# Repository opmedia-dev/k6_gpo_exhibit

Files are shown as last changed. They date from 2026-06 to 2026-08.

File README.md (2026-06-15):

# K6 GPO Exhibit

ESP32-based interface that lets an **unmodified** GPO 232 or 332 rotary-dial
telephone work as an interactive exhibit in a K6 phone box.

## Features

- **Random ringing** — the phone rings at configurable random intervals
  (default 5-30 min); answering plays a randomly selected history track
- **Dial-a-number** — dial up to 11 digits; if a matching MP3 exists on the
  SD card it plays, otherwise a "number not recognised" message plays
- **External control box** — three buttons (RING / CANCEL / RESET) on the
  operator's equipment box, connected via an extended lead
- **Full GPO phone interface** — hook detection, rotary pulse decoding, bell
  ringing (25 Hz UK cadence), all through the original 3-core cord
- **SD card audio** — all audio (history tracks, number tracks, dial tone,
  busy tone) loaded from a micro-SD card as MP3 files
- **I2S audio output** — MAX98357A DAC for quality playback through the
  phone's earpiece via a coupling transformer
- **Optional A+B coin box** — auto-detected daughter board supports classic
  GPO pre-payment coin mechanisms (Button A/B, coin weight switch)
- **Auto/Manual mode** — 4th button toggles auto-ring on/off with panel lamp
  indicator (GPIO 13, 3–6 V)
- **Wi-Fi file manager** — ESP32 creates a `K6-Exhibit` Wi-Fi hotspot;
  connect from any phone/laptop browser to upload, delete, and manage
  SD card files without removing the card
- **OTA firmware update** — upload a compiled `.bin` through the web
  interface to update firmware wirelessly
- **System & call logging** — separate logs for system events and call
  history, viewable and clearable via the web interface

No modifications are made to the telephone.

## Supported Phones

| Phone | Bell | Notes |
|---|---|---|
| GPO 232 | External (Bellset No. 26) | Blue wire drives external bell, or leave unconnected |
| GPO 332 | Internal (2 µF cap + bell coils) | Full bell ringing via blue wire |
| GPO 332L | Internal | "Listener" variant, same 3-wire connection |

Any GPO phone with a 3-wire connection (Line A, Line B, Bell) should work.
See the hardware docs for notes on other models (706, 746, etc.).

## System Architecture

```
┌─────────────┐   3-core cord    ┌─────────────────────────────┐
│  GPO Phone  │ ◄──────────────► │   ESP32 Interface Board     │
│  (unmod.)   │  extended lead   │   (in separate enclosure)   │
└─────────────┘                  │                             │
                                 │  ESP32 DevKit               │
                                 │  + SD card module           │
                                 │  + MAX98357A I2S DAC        │
                                 │  + L293D H-bridge (ringer)  │
                                 │  + 12V adapter → buck (5V)  │
                                 │    + XL6009 boost (50V)     │
                                 │  + Optocoupler (line sense) │
                                 │  + 3 control buttons        │
                                 └─────────────────────────────┘
```

## Hardware

See [`docs/hardware/`](docs/hardware/) for:
- [**Schematic**](docs/hardware/schematic.md) — full circuit with ASCII diagrams
- [**Bill of Materials**](docs/hardware/bom.md) — ~£29 in components
- [**Wiring Guide**](docs/hardware/wiring-guide.md) — step-by-step build + test

### PCB

A KiCad carrier board layout is in [`pcb/`](pcb/) — 100 × 80 mm, 2-layer,
all through-hole.  All modules (ESP32 DevKit, MAX98357A, SD card, buck/boost
converters) plug in via pin headers.  See [`pcb/README.md`](pcb/README.md)
for fabrication instructions.

## SD Card Setup

Format a micro-SD card as FAT32 and create this directory structure:

```
/system/
    dialtone.mp3           Continuous dial tone (loops while off-hook)
    busy.mp3               Busy / error tone (loops)
    not_recognised.mp3     "The number you have dialled…"
/history/
    001.mp3                History track 1 (picked at random on ring answer)
    002.mp3                History track 2
    …
/numbers/
    999.mp3                Plays when user dials 999
    100.mp3                Plays when user dials 100
    08001111.mp3           Plays when user dials 08001111
    …
```

- History tracks play when the phone rings and is answered
- Number tracks are matched by filename: dialling `999` looks for `/numbers/999.mp3`
- If no match is found, `/system/not_recognised.mp3` plays

## Wi-Fi File Manager

The ESP32 creates a Wi-Fi access point on boot:

| Setting | Value |
|---|---|
| SSID | `K6-Exhibit` |
| Password | `phonebox` |
| URL | `http://192.168.4.1/` |

Connect with any phone or laptop, open a browser, and you can:
- **Controls** — volume slider, auto-ring timing, mode toggle, Ring Now button
- **Visitor stats** — call counters, most-dialled numbers, total uptime
- **Browse** the SD card directory structure
- **Upload** new MP3 files (validated as valid MP3 before saving)
- **Delete** existing files
- **Create** new folders
- **View logs** — system events and call history (separate tabs)
- **Clear logs** — wipe system or call log
- **Flash firmware** — upload a `.bin` file for OTA update
- **System status** — free heap, SD card space (used/total), current state

### Logs

| Log | Path | Contents |
|-----|---|---|
| System | `/logs/system.log` | Boot, Wi-Fi, SD card, mode changes, OTA, errors |
| Calls | `/logs/calls.log` | Incoming/outgoing calls with timestamps, numbers, outcomes |

Logs auto-rotate at 64 KB to avoid filling the SD card.

## Firmware

Built with [PlatformIO](https://platformio.org/) (Arduino framework for ESP32).

### Build & Flash

```bash
cd firmware
pio run                    # compile
pio run -t upload          # flash to ESP32
pio device monitor         # serial console (115200 baud)
```

### Serial Commands

| Command | Action |
|---|---|
| `R` | Ring the bell |
| `H` | Hang up / stop everything |
| `C` | Cancel ring / stop playback |
| `S` | Print current state + diagnostics |
| `A` | Toggle auto-ring on/off |
| `V0`-`V9` | Set volume (0 = min, 9 = max) |

### Control Panel Buttons

| Button | Function |
|---|---|
| RING (GPIO 32) | Manually trigger the phone bell |
| CANCEL (GPIO 33) | Cancel ringing / stop current playback |
| RESET (GPIO 27) | Full system restart |
| MODE (GPIO 14) | Toggle auto/manual ring mode |

All buttons are active-low (connect to GND when pressed); the ESP32's
internal pull-ups are enabled.

### Auto-Mode Indicator Lamp

GPIO 13 drives a 3–6 V panel lamp (active-high) that illuminates when
auto-ring mode is active.  In **auto mode** the phone rings at random
intervals (5–30 min) and the lamp is ON.  In **manual mode** the phone
only rings when the RING button is pressed and the lamp is OFF.
Calling (lifting the handset, dialling) works in both modes.

### Firmware Architecture

```
main.cpp                    Arduino setup/loop, serial commands
  └─ PhoneController        Top-level state machine
       ├─ PhoneLine         Hook detection via optocoupler + ADC
       ├─ RotaryDecoder     Dial pulse counting → digit
       ├─ BellDriver        25 Hz H-bridge with UK ring cadence
       ├─ AudioPlayer       SD card MP3 playback via I2S
       ├─ ControlPanel      3-button debounced input
       └─ CoinBox           Optional A+B coin box (auto-detected)
```

State machine:

```
             auto-ring timer
                  or
IDLE ──── BTN_RING/serial 'R' ──── RINGING ──── (answer) ──── PLAYING_HISTORY
  │                                                                 │
  │                                                            (on-hook)
  │                                                                 │
  └── (lift handset) ── DIAL_TONE ── DIALING ─┬── PLAYING_NUMBER ──┘
                                               │         │
                                               │    (playback ends) ── BUSY ── (on-hook) ── IDLE
                                               │
                              [A+B, recognised] ├── AWAIT_COINS ── (coins in) ── AWAIT_BTN_A
                                               │                   "press A" prompt
                              [A+B, coins in]  ├── AWAIT_BTN_A ── (Btn A) ── PLAYING_NUMBER
                                               │                  (Btn B) ── IDLE (refund)
                                               │
                          [A+B, not recognised] └── AWAIT_BTN_B ── (Btn B) ── IDLE (refund)
                                                    "not recognised" then "press B" prompt

Without A+B: DIALING → PLAYING_NUMBER or PLAYING_NOT_REC directly.
Incoming calls (RINGING → answer) never require A+B interaction.
```

### Callbacks

```cpp
phone.onDigit([](uint8_t d)       { /* each digit as dialled */ });
phone.onNumber([](const char* n)  { /* complete number string */ });
phone.onHook([](HookState s)      { /* hook state change */     });
phone.onState([](PhoneState s)    { /* state transition */      });
```

## Pin Assignments

| GPIO | Function |
|---|---|
| 34 | Line sense (hook / dial pulse) — ADC input |
| 26 | I2S BCLK (to MAX98357A) |
| 25 | I2S LRCLK (to MAX98357A) |
| 22 | I2S DOUT (to MAX98357A) |
| 5 | SD card CS (SPI) |
| 23 | SD card MOSI |
| 19 | SD card MISO |
| 18 | SD card SCK |
| 4 | Ring enable (H-bridge EN) |
| 16 | Ring phase A (H-bridge IN1) |
| 17 | Ring phase B (H-bridge IN2) |
| 32 | Button: RING (active-low) |
| 33 | Button: CANCEL (active-low) |
| 27 | Button: RESET (active-low) |
| 14 | Button: MODE (active-low) |
| 13 | Auto-mode lamp (active-high, 3–6 V) |
| 2 | Status LED |
| 36 | Coin box: coin sense (optional, input-only) |
| 39 | Coin box: Button A (optional, input-only) |
| 35 | Coin box: Button B (optional, input-only) |

## Technical Reference

See [`docs/gpo-phone-reference.md`](docs/gpo-phone-reference.md) for detailed
GPO 232/332 electrical specifications, rotary dial pulse characteristics, and
bell ringing requirements.

## Future Enhancements

- **Wi-Fi / MQTT** integration for remote exhibit control
- **Multi-phone networking** — connect two GPO phones via ESP-NOW
- **VoIP gateway** — bridge the GPO phone to SIP/VoIP
- **A+B coin box daughter board** — PCB design for coin mechanism interface
- **OLED status display** on the operator's control box

## License

MIT

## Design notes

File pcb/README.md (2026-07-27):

# PCB — K6 GPO Exhibit Carrier Board

KiCad 10 project for a 2-layer carrier board (100 × 100 mm).  All modules
plug in via through-hole pin headers — no SMD soldering required.

See **[PINOUT.md](PINOUT.md)** for the complete pinout reference with every
pin, net, and signal described.

## Files

| File | Description |
|---|---|
| `k6_gpo_carrier.kicad_pro` | KiCad project file |
| `k6_gpo_carrier.kicad_sch` | Schematic (text-documentation style — shows all nets and pin assignments) |
| `k6_gpo_carrier.kicad_pcb` | PCB layout with component placement, ground-fill zones, and board outline |
| `generate_kicad.py` | Python script that generates all files above (run to regenerate) |
| `PINOUT.md` | Complete pinout reference (full tables for every connector and IC) |
| `k6_carrier_rev2-8.kicad_pcb` | **Hand-routed manufacturing master (Rev 2.1, as-built & bench-proven).** Use this file for reorders. Includes the Rev 2.1 fixes: R7 (R_LIM 2.2 kΩ) and D1 in series in the opto leg, C3 (10 µF/63 V coupling cap) in series with the transformer secondary, and R2 (470 Ω) as the opto-LED shunt. Power/48 V nets widened. Not generated by the scripts — edit here directly. |

> **Reorders:** fabricate from `k6_carrier_rev2-8.kicad_pcb`. The
> `generate_*.py` scripts produce the earlier auto-layout boards and do
> **not** include the hand-routed Rev 2.1 corrections above — regenerating
> will not reproduce this master. Before ordering: continuity-check the
> built board, confirm R7 is populated in series, and confirm D1's banded
> (cathode) end faces the PC817 side.

## Board Specifications

| Parameter | Value |
|---|---|
| Dimensions | 100 × 100 mm |
| Layers | 2 (F.Cu + B.Cu) |
| Copper weight | 1 oz |
| Board thickness | 1.6 mm |
| Mounting holes | 4× M3, 4 mm from edges |
| Min trace width | 0.5 mm (power) / 0.25 mm (signal) |
| Min drill | 0.4 mm (vias), 0.8 mm (IC pads), 1.0 mm (headers) |

## Component Placement

```
┌──────────────────────────────────────────────────────────────────────────────┐
│ (MH)  [12V IN]  [BUCK]   [BOOST]                [MAX98357A] [DAC] (MH)     │
│         J3       J1        J2                      J5        J6             │
│                                                                             │
│                                                    [XFMR T1]               │
│                 ┌─────────────────────┐                                     │
│                 │                     │            [PHONE J4]               │
│                 │    ESP32 DevKit     │             3-pin screw             │
│                 │        U1           │                                     │
│ [BUTTONS]       │  2×15 pin headers   │                                     │
│  J8 RING        └─────────────────────┘       [C1]                         │
│  J9 CANCEL                                                                  │
│  J10 RESET                                    ┌────────┐                   │
│                                               │ L293D  │                   │
│                                               │  U2    │                   │
│                 [R1 470R]  [R2 220R]          └────────┘  [R3 10K]         │
│ [SD CARD]                                     ┌────┐                       │
│  J7                                           │PC817│                      │
│                                               │ U3  │                      │
│ (MH)                                          └────┘            (MH)       │
└──────────────────────────────────────────────────────────────────────────────┘
  (MH) = Mounting hole M3
```

## Connectors

| Ref | Description | Pins |
|-----|---|---|
| J1 | LM2596 buck converter (12V → 5V) | 4: IN+, IN-, OUT+, OUT- |
| J2 | XL6009 boost converter (12V → 50V) | 4: IN+, IN-, OUT+, OUT- |
| J3 | 12V DC power input | 2: +12V, GND |
| J4 | Phone cord (3-pin screw terminal) | 3: Line A, Line B, Bell |
| J5 | MAX98357A DAC module | 7: VIN, GND, SD, GAIN, DIN, BCLK, LRC |
| J6 | DAC audio output (to transformer) | 2: L+, L- |
| J7 | SD card module (SPI) | 6: GND, VCC, MOSI, MISO, SCK, CS |
| J8 | RING button (to control panel) | 2: signal, GND |
| J9 | CANCEL button (to control panel) | 2: signal, GND |
| J10 | RESET button (to control panel) | 2: signal, GND |

## ICs

| Ref | Part | Package |
|-----|---|---|
| U1 | ESP32 DevKit V1 | 2×15 pin header socket (25.4 mm row spacing) |
| U2 | L293D H-bridge | DIP-16 (use IC socket) |
| U3 | PC817 optocoupler | DIP-4 (use IC socket) |

## Passive Components

| Ref | Value | Purpose |
|-----|---|---|
| R1 | 470 Ω 1W | Line current limit |
| R2 | 220 Ω ¼W | Optocoupler LED current limit |
| R3 | 10 kΩ ¼W | Optocoupler output pull-down |
| C1 | 100 nF | L293D decoupling capacitor |
| T1 | 600 Ω : 600 Ω transformer | Audio coupling to phone line |

## Fabrication

### Ordering from JLCPCB / PCBWay

1. Open the project in KiCad 10+
2. **File → Plot** → select Gerber format, output to `gerbers/`
3. Check layers: F.Cu, B.Cu, F.SilkS, B.SilkS, F.Mask, B.Mask, Edge.Cuts
4. **Generate Drill Files** → Excellon format
5. Zip the `gerbers/` folder and upload to your fabricator

Typical 5-board order from JLCPCB: ~$2 + shipping.

### Assembly Notes

1. Solder IC sockets first (U2 DIP-16, U3 DIP-4)
2. Solder resistors and capacitor
3. Solder pin headers for all module connectors
4. Solder screw terminals (J3 power, J4 phone)
5. Solder transformer T1
6. Insert ICs into sockets (mind pin 1 orientation)
7. Plug in modules: ESP32, MAX98357A, SD card, buck converter, boost converter

## Regenerating Files

If you modify the board layout, edit `generate_kicad.py` and run:

```bash
cd pcb
python3 generate_kicad.py
```

This regenerates all three KiCad files from scratch.

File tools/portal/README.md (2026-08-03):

# K6 GPO Portal (web UI source)

React + Vite + Tailwind (shadcn/ui) source for the control panel served by the
ESP32 firmware. The firmware does **not** run this build directly — instead the
compiled app is inlined into a single HTML file, gzip-compressed, and embedded
as a byte array in `firmware/src/portal_html.h`, which `handleIndex()` serves
with `Content-Encoding: gzip`.

Every control is wired to the firmware's existing HTTP API (`/api/status`,
`/api/stats`, `/api/files`, `/api/wifi`, `/api/ota`, `/api/terminal`, …); no
server changes are needed to change the look of the portal.

## Requirements

Node 18+ and npm.

## Regenerate the embedded portal

From this directory:

```bash
npm install
npm run build      # vite build -> dist/public/
npm run inline     # -> esp32_portal.html (single self-contained file)

# Compress and turn into the C byte array the firmware embeds:
gzip -9 -n -c esp32_portal.html > esp32_portal.html.gz
python3 - <<'PY'
data=open("esp32_portal.html.gz","rb").read()
out="../../firmware/src/portal_html.h"
L=["// AUTO-GENERATED — do not edit by hand.",
"// Gzip-compressed single-file React portal (source project: tools/portal).",
"// Regenerate: see tools/portal/README.md",
"#pragma once","#include <pgmspace.h>","#include <stddef.h>","",
"const uint8_t PORTAL_HTML_GZ[] PROGMEM = {"]
row=[];body=[]
for b in data:
    row.append("0x%02x,"%b)
    if len(row)==20: body.append("  "+"".join(row)); row=[]
if row: body.append("  "+"".join(row))
L.append("\n".join(body)); L.append("};")
L.append("const size_t PORTAL_HTML_GZ_LEN = %d;"%len(data)); L.append("")
open(out,"w").write("\n".join(L)); print("wrote",out,len(data),"bytes")
PY
```

Then rebuild the firmware (`cd ../../firmware && pio run`) and flash it.

## Local preview against a real device

`npm run build` then open `dist/public/index.html`, or run a dev server and
proxy `/api/*` to a phone box on your network. The app talks to relative
`/api/...` paths, so serving it from the device (or a proxy) is all that's
needed.

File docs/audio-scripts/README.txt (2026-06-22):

K6 GPO Exhibit — Audio Scripts
==============================

These scripts are intended for recording as MP3 audio files for the
K6 telephone exhibit. Record them using a clear British voice, or use
a text-to-speech service. All files should be mono, 8kHz or higher
sample rate, MP3 format.

The scripts are organised to match the SD card directory structure
expected by the firmware.

HISTORY FILES — /history/
-------------------------
Played in random order when a visitor answers an auto-ring call.

  k6_history.mp3      The story of the K6 telephone box (~45s)
  gpo_exchange.mp3    How calls were connected by operators (~50s)
  rotary_dialling.mp3 How the rotary dial works (~40s)
  speaking_clock.mp3  The story of TIM / Speaking Clock (~45s)
  999_history.mp3     The world's first emergency number (~45s)
  button_ab.mp3       How Button A and Button B worked (~45s)
  model_railways.mp3  Telephones and the railway (~50s)

NUMBER FILES — /numbers/
------------------------
Played when a visitor dials the corresponding number.

  Dial    File                  Description
  ----    ----                  -----------
  100     operator.mp3          GPO operator — "Number please?"
  0       operator.mp3          (same file, mapped to both numbers)
  123     speaking_clock.mp3    TIM speaking clock demonstration
  999     emergency.mp3         Emergency services demonstration
  192     directory.mp3         Directory enquiries
  150     faults.mp3            GPO faults reporting line
  246     station_master.mp3    Station master's office
  347     departures.mp3        Train departure announcements
  501     signal_box.mp3        Signal box / signalman
  742     parcels.mp3           Railway parcels office
  800     timetable.mp3         Timetable enquiries
  007     bond.mp3              Easter egg — spy theme
  666     spooky.mp3            Easter egg — ghost train

SYSTEM FILES — /system/
-----------------------
Used by the firmware for specific events.

  not_recognised.mp3  Played when a dialled number is not in the directory
  welcome.mp3         Optional welcome message for auto-ring answers
  insert_coins.mp3    Prompt to insert coins (coinbox mode only)
  press_a.mp3         Prompt to press Button A (coinbox mode only)

RECORDING TIPS
--------------
- Use a quiet room with minimal echo
- Speak clearly at a moderate pace
- Leave a 0.5-second silence at the start and end of each file
- Target volume: -16 dBFS peak (loud enough to hear through
  the telephone earpiece without distortion)
- For sound effects (static, reverb, bells), add them in post-
  production rather than trying to record them live
- The telephone earpiece has limited frequency response — avoid
  relying on very high or very low frequencies for important content

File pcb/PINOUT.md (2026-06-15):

# K6 GPO Exhibit — Carrier Board Pinout Reference

Full pinout for every connector and IC on the carrier board. Silkscreen
labels on the PCB use short abbreviations — this document provides the
complete mapping.

## Silkscreen Abbreviation Legend

| Abbreviation | Meaning |
|---|---|
| SN | LINE_SENSE (hook detect ADC) |
| RG | BTN_RING (manual ring button) |
| CN | BTN_CANCEL (cancel button) |
| LR | I2S_LRCLK (word select) |
| BC | I2S_BCLK (bit clock) |
| RS | BTN_RESET (reset button) |
| MO | SPI_MOSI |
| MI | SPI_MISO |
| CK | SPI_SCK |
| CS | SD_CS (SD card chip select) |
| DIN | I2S_DOUT (data to DAC) |
| RB | RING_B (bell H-bridge B) |
| RA | RING_A (bell H-bridge A) |
| REN | RING_EN (bell enable) |
| LD | LED_STATUS |
| VIN | LM2596 pin 1 (12V input) |
| SW | LM2596 pin 2 (switch output) |
| FB | LM2596 pin 4 (feedback / +5V) |
| ON | LM2596 pin 5 (ON/OFF) |
| LnA | LINE_A (phone line) |
| LnB | LINE_B (phone line) |
| An | Anode |
| Kth | Cathode |
| Col | Collector |
| Em | Emitter |

---

## J3 — 12V DC Power Input

2-pin screw terminal (rotated 90°)

| Pin | Net | Description |
|-----|-----|---|
| 1 | +12V | DC input from wall adapter |
| 2 | GND | Ground |

## U4 — LM2596-5.0 Buck Converter IC (12V → 5V)

TO-220-5 package, on-board with supporting passives.

| Pin | Silk | Net | Description |
|-----|---|-----|---|
| 1 | VIN | +12V | Input voltage (12V) |
| 2 | SW | SW_OUT | Switch output → D1 cathode / L1 input |
| 3 | GND | GND | Ground (also connected to heatsink tab) |
| 4 | FB | +5V | Feedback (fixed 5V version → connects to output) |
| 5 | ON | GND | ON/OFF control (GND = always on) |

### Supporting Buck Converter Components

| Ref | Value | Net 1 | Net 2 | Description |
|-----|---|---|---|---|
| C2 | 680 µF 25V electrolytic | +12V | GND | Input filter capacitor |
| L1 | 33 µH power inductor | SW_OUT | +5V | Energy storage inductor |
| D1 | 1N5825 (5A 40V Schottky) | GND (anode) | SW_OUT (cathode) | Freewheeling diode |
| C3 | 220 µF 25V electrolytic | +5V | GND | Output filter capacitor |

**Circuit:** +12V → CIN (C2) → U4 VIN (pin 1). U4 OUTPUT (pin 2) → L1 → +5V rail.
D1 cathode connects to pin 2/L1 junction (SW_OUT); D1 anode to GND.
COUT (C3) smooths the +5V output. Pin 5 tied to GND for always-on operation.

## J2 — XL6009 Boost Converter (12V → 50V)

4-pin header

| Pin | Silk | Net | Description |
|-----|---|-----|---|
| 1 | 12V+ | +12V | Input positive |
| 2 | GND | GND | Input negative |
| 3 | 50V+ | +50V | Output positive (adjust trimpot) |
| 4 | GND | GND | Output negative |

## U1 — ESP32 DevKit V1

2×15 pin header socket (25.4 mm row spacing, 2.54 mm pin pitch)

### Left Column (top → bottom)

| Pin | Silk | GPIO | Net | Function |
|-----|---|---|-----|---|
| L1 | 3V3 | — | +3V3 | 3.3V output |
| L2 | EN | — | — | Enable (reset) |
| L3 | 36 | 36 | — | Input only |
| L4 | 39 | 39 | — | Input only |
| L5 | 34 SN | 34 | LINE_SENSE | Hook detect ADC input |
| L6 | 35 | 35 | — | Unused |
| L7 | 32 RG | 32 | BTN_RING | Manual ring button |
| L8 | 33 CN | 33 | BTN_CANCEL | Cancel button |
| L9 | 25 LR | 25 | I2S_LRCLK | I2S word select clock |
| L10 | 26 BC | 26 | I2S_BCLK | I2S bit clock |
| L11 | 27 RS | 27 | BTN_RESET | Reset button |
| L12 | 14 | 14 | — | Unused |
| L13 | 12 | 12 | — | Unused |
| L14 | GND | — | GND | Ground |
| L15 | 13 | 13 | — | Unused |

### Right Column (top → bottom)

| Pin | Silk | GPIO | Net | Function |
|-----|---|---|-----|---|
| R1 | 5V | — | +5V | 5V input from buck converter |
| R2 | GND | — | GND | Ground |
| R3 | 23 MO | 23 | SPI_MOSI | SD card data out |
| R4 | 22 DIN | 22 | I2S_DOUT | I2S data to DAC |
| R5 | TX | TX0 | — | Serial TX (debug) |
| R6 | RX | RX0 | — | Serial RX (debug) |
| R7 | 21 | 21 | — | Unused |
| R8 | 19 MI | 19 | SPI_MISO | SD card data in |
| R9 | 18 CK | 18 | SPI_SCK | SD card SPI clock |
| R10 | 5 CS | 5 | SD_CS | SD card chip select |
| R11 | 17 RB | 17 | RING_B | Bell H-bridge input B |
| R12 | 16 RA | 16 | RING_A | Bell H-bridge input A |
| R13 | 4 REN | 4 | RING_EN | Bell H-bridge enable |
| R14 | 2 LD | 2 | LED_STATUS | On-board LED |
| R15 | 15 | 15 | — | Unused |

## J5 — MAX98357A I2S DAC Module

7-pin header

| Pin | Silk | Net | Description |
|-----|---|-----|---|
| 1 | 5V | +5V | Module power |
| 2 | GND | GND | Ground |
| 3 | SD | — | Shutdown (leave floating or tie high) |
| 4 | GAIN | — | Gain select (leave floating = 9 dB) |
| 5 | DIN | I2S_DOUT | I2S data input (from ESP32 GPIO 22) |
| 6 | BCK | I2S_BCLK | I2S bit clock (from ESP32 GPIO 26) |
| 7 | LRC | I2S_LRCLK | I2S word select (from ESP32 GPIO 25) |

## J6 — DAC Audio Output

2-pin header (connects to transformer T1 primary)

| Pin | Silk | Net | Description |
|-----|---|-----|---|
| 1 | SPK+ | AUDIO_P1 | Speaker output + |
| 2 | SPK- | AUDIO_P2 | Speaker output − |

## T1 — Audio Coupling Transformer

600 Ω : 600 Ω, 4-pin

| Pin | Silk | Net | Description |
|-----|---|-----|---|
| 1 | SPK+ | AUDIO_P1 | Primary (from DAC SPK+) |
| 2 | SPK- | AUDIO_P2 | Primary (from DAC SPK−) |
| 3 | LnA | LINE_A | Secondary → phone Line A |
| 4 | LnB | LINE_B | Secondary → phone Line B |

## J4 — Phone Cord

3-pin screw terminal (rotated 90°, pitch 5.08 mm)

| Pin | Silk | Net | Wire Colour | Description |
|-----|---|-----|---|---|
| 1 | A Red | LINE_A | Red | Line A |
| 2 | B Wht | LINE_B | White | Line B |
| 3 | Bell | BELL | Blue | Bell coil connection |

## J8 — Ring Button

2-pin header (active low, internal pull-up)

| Pin | Silk | Net | Description |
|-----|---|-----|---|
| 1 | RING | BTN_RING | Button signal → ESP32 GPIO 32 |
| 2 | GND | GND | Ground |

## J9 — Cancel Button

2-pin header (active low, internal pull-up)

| Pin | Silk | Net | Description |
|-----|---|-----|---|
| 1 | CANCEL | BTN_CANCEL | Button signal → ESP32 GPIO 33 |
| 2 | GND | GND | Ground |

## J10 — Reset Button

2-pin header (active low, internal pull-up)

| Pin | Silk | Net | Description |
|-----|---|-----|---|
| 1 | RESET | BTN_RESET | Button signal → ESP32 GPIO 27 |
| 2 | GND | GND | Ground |

## J7 — Micro-SD Card Module (SPI)

6-pin header

| Pin | Silk | Net | Description |
|-----|---|-----|---|
| 1 | GND | GND | Ground |
| 2 | 3V3 | +3V3 | Module power |
| 3 | MOSI | SPI_MOSI | Data out → ESP32 GPIO 23 |
| 4 | MISO | SPI_MISO | Data in ← ESP32 GPIO 19 |
| 5 | SCK | SPI_SCK | SPI clock → ESP32 GPIO 18 |
| 6 | CS | SD_CS | Chip select → ESP32 GPIO 5 |

## U2 — L293D H-Bridge Motor Driver (DIP-16)

| Pin | Side | Silk | Net | Description |
|-----|---|---|-----|---|
| 1 | L | EN | RING_EN | Enable 1/2 → ESP32 GPIO 4 |
| 2 | L | IN1 | RING_A | Input 1 → ESP32 GPIO 16 |
| 3 | L | BELL | BELL | Output 1 → bell coil |
| 4 | L | GND | GND | Ground |
| 5 | L | GND | GND | Ground |
| 6 | L | LnB | LINE_B | Output 2 → phone Line B |
| 7 | L | IN2 | RING_B | Input 2 → ESP32 GPIO 17 |
| 8 | L | 50V | +50V | Motor supply (from boost) |
| 9 | R | GND | GND | Ground |
| 10 | R | — | — | Not connected |
| 11 | R | — | — | Not connected |
| 12 | R | — | GND | Ground |
| 13 | R | — | GND | Ground |
| 14 | R | — | — | Not connected |
| 15 | R | — | — | Not connected |
| 16 | R | 5V | +5V | Logic supply |

## U3 — PC817 Optocoupler (DIP-4)

| Pin | Side | Silk | Net | Description |
|-----|---|---|-----|---|
| 1 | L | An | OPTO_ANODE | LED anode (from R2) |
| 2 | L | Kth | LINE_B | LED cathode → Line B |
| 3 | R | Em | OPTO_EMIT | Phototransistor emitter → R3 → GND |
| 4 | R | Col | +3V3 | Phototransistor collector → 3.3V |

**Hook detect circuit:** +12V → R1 (470 Ω) → junction → R2 (220 Ω) → PC817 anode (pin 1). PC817 cathode (pin 2) → LINE_B. When phone is off-hook, current flows through the loop, illuminating the optocoupler LED. The phototransistor output (pin 3) is read by ESP32 GPIO 34 (ADC).

## Passive Components

| Ref | Value | Silk | Net 1 | Net 2 | Function |
|-----|---|---|---|---|---|
| R1 | 470 Ω 1W | R1 470R | +12V | JUNC_A | Line current limit |
| R2 | 220 Ω ¼W | R2 220R | JUNC_A | OPTO_ANODE | Opto LED current limit |
| R3 | 10 kΩ ¼W | R3 10K | OPTO_EMIT | GND | Opto output pull-down |
| C1 | 100 nF | C1 100nF | +5V | GND | L293D decoupling |
| C2 | 680 µF 25V | C2 680µF | +12V | GND | LM2596 input filter |
| C3 | 220 µF 25V | C3 220µF | +5V | GND | LM2596 output filter |
| L1 | 33 µH 3A | L1 33µH | SW_OUT | +5V | Buck inductor |
| D1 | 1N5825 | D1 1N5825 | GND | SW_OUT | Buck freewheeling diode |

## Module Clearance Zones

Dashed silkscreen outlines on the PCB show where plug-in module boards sit.
Do not place tall components within these zones.

| Module | Size (mm) | Header | Orientation |
|---|---|---|---|
| XL6009 Boost | 43 × 21 | J2 (4-pin) | Extends right from header |
| MAX98357A DAC | 19 × 18 | J5 (7-pin) | Extends left from header |
| Micro-SD Card | 25 × 20 | J7 (6-pin) | Extends right from header |

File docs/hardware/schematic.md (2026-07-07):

# Hardware Schematic — ESP32 GPO Phone Interface (Rev 2)

> **Revision 2** — redesigned for two separate DC supplies (12 V + 48 V),
> corrected pull-ups on input-only GPIOs, four control buttons,
> development access holes on every ESP32 pin, and a 6-pin daughter
> board header.

> All components are housed in a **separate enclosure** connected to the
> phone via an extended 3-core lead.

---

## Revision Notes — What Changed from Rev 1

| Issue (Rev 1) | Root Cause | Fix (Rev 2) |
|---|---|---|
| False A+B coin box detection when no daughter board attached | GPIO 36/39/35 are input-only with **no internal pull-up**. They float randomly — a LOW reading during the 2 s boot window triggers false detection. | Added **external 10 kΩ pull-up resistors** (R4, R5, R6) to 3.3 V on each coin box GPIO. Pins now read HIGH reliably when nothing is connected. |
| Buttons not responding (except CANCEL intermittently) | Likely wiring/positioning error on the PCB. GPIO 14 (MODE button) also has an internal pull-down during ESP32 boot, which may fight the signal. The original docs only listed 3 buttons, but firmware uses 4. | All 4 buttons clearly positioned with their own PCB zone. GPIO 14 pull-down is only active during boot — the internal pull-up is set in firmware after boot, so this is fine for a button. Ensure button wiring is correct per the new layout. |
| Polarity issues | Component orientation not clearly marked on the stripboard. | New layout includes clear polarity markers for the optocoupler, L293D, and all electrolytic capacitors. |
| Single 12 V supply for everything | XL6009 boost converter draws heavily during ringing, causing voltage dips on the 5 V rail → ESP32 brownout. | **Two separate supplies**: 12 V 1 A for logic (5 V buck), 48 V 1 A for bell (direct to L293D VS). No shared current path. |

---

## 1. Power Supply

Two **separate** DC adapters power the system. This eliminates voltage
dips during bell ringing that caused ESP32 resets in Rev 1.

```
    ┌─────────────────────┐         ┌─────────────────────┐
    │  12 V DC  1 A       │         │  48 V DC  1 A       │
    │  (barrel jack)      │         │  (barrel jack)      │
    │                     │         │                     │
    │  Powers:            │         │  Powers:            │
    │  • Buck converter   │         │  • L293D H-bridge   │
    │    (12 V → 5 V)     │         │    pin 8 (VS)       │
    │  • Line sense       │         │    for bell ringing  │
    │    circuit (R1)     │         │                     │
    └─────────┬───────────┘         └─────────┬───────────┘
              │                               │
     ┌────────┴────────┐                      │
     │  Buck Converter  │                      │
     │  LM2596 module   │                      │
     │  12 V → 5 V      │                      │
     │  (adjust trimpot) │                     │
     └────────┬─────────┘                      │
              │                                │
         +5 V rail                        +48 V rail
         Powers:                          (bell only)
         • ESP32 VIN
         • MAX98357A VIN
         • SD card module
         • L293D pin 16 (VSS)
```

### Power Bus Wiring

The board has **two bus rails** running the full length:

| Bus | Voltage | Source | Connects to |
|-----|---|---|---|
| **5 V bus** | +5 V / GND | LM2596 output | ESP32 VIN, MAX98357A VIN, SD card VCC, L293D pin 16 |
| **48 V bus** | +48 V / GND | 48 V adapter | L293D pin 8 (VS) only |

> **IMPORTANT:** The GND rails of both supplies must be **connected
> together** at a single point on the board. This provides a common
> ground reference. Connect them near the L293D GND pins.

### Components

| Part | Example | Purpose |
|---|---|---|
| 12 V DC adapter | Any 12 V / 1 A barrel-jack adapter | Logic power |
| 48 V DC adapter | Any 48 V / 1 A barrel-jack adapter | Bell power |
| Buck converter module | LM2596 adjustable (set to 5 V) | 12 V → 5 V for logic |

> **Setup:** Before connecting anything else, power the buck converter
> from 12 V and adjust its trimpot until the output reads **5.0 V** on a
> multimeter.

---

## 2. Hook / Dial Pulse Detection

This circuit detects whether the handset is on the cradle (on-hook) or
lifted (off-hook), and senses the rotary dial pulses — all on a single
GPIO pin.

> **Rev 2.1 correction — the optocoupler must be *in series* with the
> loop, not bridged across it.** The original Rev 2 layout wired the
> PC817 LED across the line (Line A via R2 → LED → Line B), with Line B
> having no return to ground. That topology can carry **no loop current
> in any hook state**, so hook and dial detection never worked. The LED
> is now in series in the return leg: **+12 V → R1 → Line A → phone →
> Line B → R_LIM → D1 → LED → GND.** R2 is deleted. This was verified on
> the bench (hook + dial both decode correctly). See the warning below
> before ever applying the 48 V bell supply.

```
    +12 V ────────┐
                  │
                 [R1]  470 Ω  1W
                  │
                  └──────────── Terminal 1 (RED wire = Line A)

                  ═══ phone loop ═══  (open on-hook, ~360 Ω off-hook)

    Terminal 2 ───┐
    (WHITE wire   │
     = Line B)   [R_LIM]  2.2 kΩ        ← current limit (MANDATORY, see warning)
                  │
                  ▼  D1  (1N4148, anode → Line B side)
                  │
             ┌────┴────┐
             │  PC817   │
             │ OPTO-    │
             │ COUPLER  │
             │  Anode  ┌┤
             │    (p1) ││── Collector (p4) ─── +3.3 V
             │  LED    └┤
             │ Cathode   │
             │  (p2)     Emitter (p3) ──┬── GPIO 34 (ESP32)
             └────┬────┘                │
                  │                    [R3]  10 kΩ
                 GND                     │
                                        GND
```

**PC817 pinout (DIP-4) — polarity markers:**

```
    ┌──────────┐
    │  Pin 1   │  Anode  ── dot/band on package (from D1 cathode / Line B leg)
    │  Pin 2   │  Cathode ── to GND
    │  Pin 3   │  Emitter ── (to GPIO 34 + R3)
    │  Pin 4   │  Collector ── (to +3.3 V)
    └──────────┘
    Pin 1 is marked with a dot on the IC package.
    The LED inside goes from pin 1 (anode) to pin 2 (cathode).
```

**How it works:**

| Phone state | What happens | GPIO 34 reads |
|---|---|---|
| **On-hook** (handset down) | Loop open — no current, LED off | LOW (~0 V) |
| **Off-hook** (handset lifted) | Loop closed — ~4-13 mA flows through R1 → phone → R_LIM → D1 → LED → GND | HIGH (~3.3 V) |
| **Dial pulse** (rotary dial break) | Loop briefly interrupted → LED off | LOW pulse (20-120 ms) |

The firmware counts these LOW pulses to decode the dialled digit
(1 pulse = digit 1, 10 pulses = digit 0).

> ### ⚠️ SAFETY: R_LIM is mandatory before applying 48 V
>
> Line B carries the **48 V ring voltage** during ringing. The opto LED
> leg (Line B → D1 → LED → GND) has **no other current limit** — R1 is
> on the Line A side and is *not* in this path. Without **R_LIM
> (1.5–2.2 kΩ)** in the Line B leg, the 48 V ring drives destructive
> current through the LED.
>
> **This is not theoretical:** on the bench, applying 48 V with R_LIM
> omitted breached the PC817's isolation and back-fed the ESP32, cooking
> both the optocoupler *and* the ESP32 module (it powered up but ran
> hot). **Never apply 48 V unless R_LIM is fitted.**
>
> - Ring peak current with R_LIM = 2.2 kΩ: 48 V / 2.2 kΩ ≈ **22 mA**
>   (safe for the PC817).
> - Off-hook detect current: (15 V − ~1.9 V) / (470 + 360 + 2200) ≈
>   **4–5 mA** (enough to trigger; drop R_LIM to 1.5 kΩ if marginal).
> - **D1 (series diode)** blocks the reverse half of the ring, so a
>   separate anti-parallel clamp diode is *not* required.

---

## 3. Ring Generator

Makes the bell ring using a 48 V square-wave AC signal at 25 Hz,
switched by an L293D H-bridge IC.

```
    +48 V (from 48 V DC adapter) ── L293D pin 8 (VS)

    +5 V ──────────────────────────── L293D pin 16 (VSS / logic supply)

    ESP32 GPIO 4  ─────────────────── L293D pin 1 (EN1,2 — enable)
    ESP32 GPIO 16 ─────────────────── L293D pin 2 (IN1)
    ESP32 GPIO 17 ─────────────────── L293D pin 7 (IN2)

    L293D pin 3 (OUT1) ──────────── Terminal 3 (BLUE wire = Bell)
    L293D pin 6 (OUT2) ──────────── Terminal 2 (WHITE wire = Line B)

    L293D pins 4, 5, 12, 13 ─────── GND (common ground bus)
    L293D pin 9 ──────────────────── GND
```

**How it works:**

The firmware alternates IN1/IN2 at 25 Hz while EN is HIGH (with PWM
for volume control), producing a square wave that swings between +48 V
and -48 V across the bell coil.  The GPO 332's internal 2 µF capacitor
passes this AC to the bell mechanism.

> **Note:** Rev 1 used a boost converter to generate 50 V from 12 V.
> Rev 2 uses a dedicated 48 V DC supply, eliminating the boost converter
> entirely. 48 V is sufficient to ring the bell — the GPO spec is
> 60-80 V AC, but the capacitive impedance at 25 Hz means 48 V
> produces adequate striking force.

**L293D pinout (DIP-16) — notch at top:**

```
                 ┌───┐
    EN1,2  1 ────┤   ├──── 16  VSS (+5 V logic)
      IN1  2 ────┤   ├──── 15  EN3,4 (n/c)
     OUT1  3 ────┤   ├──── 14  IN4 (n/c)
      GND  4 ────┤   ├──── 13  GND
      GND  5 ────┤   ├──── 12  GND
     OUT2  6 ────┤   ├──── 11  OUT4 (n/c)
      IN2  7 ────┤   ├──── 10  IN3 (n/c)
  VS(+48V) 8 ────┤   ├──── 9   GND
                 └───┘
    Notch/dot at pin 1 end. Mount with notch facing away from
    the 48 V bus to keep high-voltage traces on one side.
```

---

## 4. Audio Output (I2S DAC → Phone Line)

Audio plays from the SD card through an I2S DAC module, then into the
phone line via a coupling transformer.

```
    ESP32                     MAX98357A              Audio Transformer
    GPIO 26 ── BCLK ────────► BCLK                 (600 Ω : 600 Ω, 1:1)
    GPIO 25 ── LRCLK ───────► LRC
    GPIO 22 ── DIN ──────────► DIN        L+ ──────► Primary pin 1 ──┐
    5 V ─────── VIN ─────────► VIN                                    │(transformer)
    GND ─────── GND ─────────► GND        L- ──────► Primary pin 2 ──┘
                                                           │
                                        Secondary pin 1 ──[ Cc ]── Terminal 1 (Line A)
                                        Secondary pin 2 ────────── Terminal 2 (Line B)
```

**How it works:**

The MAX98357A decodes I2S audio into an analogue signal on L+/L-.
The coupling transformer isolates this from the phone line's DC bias
and matches impedance.  Audio passes through the phone's internal
induction coil to the earpiece.

> ### ⚠️ Cc — DC-blocking coupling capacitor is MANDATORY
>
> The transformer secondary winding is only **~70–120 Ω at DC**, so if
> it connects directly across Terminal 1 ↔ Terminal 2 it forms a **DC
> short across the line**. That short:
> 1. **Swamps the hook loop** — the phone's 360 Ω (off-hook) vs. open
>    (on-hook) swing is invisible next to a fixed ~120 Ω, so the
>    optocoupler stays saturated and hook/dial detection fails; and
> 2. **Saturates the transformer core** with the DC bias current now
>    flowing (+12 V → R1 → Line A → secondary → Line B → LED → GND),
>    adding gross distortion.
>
> Fit **Cc in series with one secondary leg** (Line A leg shown):
> - **10 µF non-polar / bipolar, ≥63 V** (film or bipolar electrolytic), **or**
> - **two 10 µF 63 V electrolytics in series, back-to-back** (join the
>   two like terminals, − to −) ≈ **5 µF non-polar, 63 V** — perfectly
>   adequate for telephone-band voice (~106 Ω at 300 Hz).
>
> Cc passes voice but blocks DC, so the line is no longer shorted:
> hook + dial work, the core no longer saturates, and 25 Hz ring bleed
> into the earpiece is attenuated. The old "10 Ω in series with the
> primary" note is superseded by this.

---

## 5. SD Card (SPI)

Standard micro-SD card breakout module, using the ESP32's default VSPI bus.

```
    ESP32                SD Card Module
    GPIO 5  ── CS ──────► CS
    GPIO 23 ── MOSI ────► MOSI (DI)
    GPIO 19 ── MISO ◄───  MISO (DO)
    GPIO 18 ── SCK ─────► SCK (CLK)
    3.3 V ───── VCC ────► VCC
    GND ─────── GND ────► GND
```

---

## 6. Control Panel — Four Buttons

Four momentary push buttons on the operator's control box.
No external resistors needed — the ESP32's internal pull-ups are enabled
in firmware. Each button connects its GPIO pin to GND when pressed.

```
    ESP32 GPIO 32 ──── [RING button]   ──── GND
    ESP32 GPIO 33 ──── [CANCEL button] ──── GND
    ESP32 GPIO 27 ──── [RESET button]  ──── GND
    ESP32 GPIO 14 ──── [MODE button]   ──── GND
```

| Button | What it does |
|---|---|
| RING | Manually triggers the phone bell |
| CANCEL | Stops ringing or current audio playback |
| RESET | Reboots the ESP32 |
| MODE | Toggles between Automatic and Manual ringing mode |

> **Note on GPIO 14:** This pin has an internal pull-down during the
> ESP32 boot sequence (it is used for JTAG). The MODE button may read
> as "pressed" momentarily during the first ~100 ms of boot. The
> firmware ignores button inputs until after `setup()` completes, so
> this has no effect in practice. After boot, `INPUT_PULLUP` is
> configured and the pin behaves normally.

---

## 7. Auto-Mode Panel Lamp

A small panel indicator lamp (3-6 V filament or LED with resistor)
driven by a GPIO via a simple transistor switch if needed, or directly
for an LED.

```
    ESP32 GPIO 13 ──── [lamp +] ──── [lamp -] ──── GND
```

For a 3 V LED: add a **100 Ω resistor** in series.
For a 5-6 V filament lamp: use a **2N2222 NPN transistor** as a switch:

```
    GPIO 13 ── [1 kΩ] ── Base
                         Collector ── [lamp +]
                         Emitter ──── GND
                         [lamp -] ──── +5 V
```

| Lamp state | Meaning |
|---|---|
| Steady ON | Automatic ringing mode active |
| OFF | Manual mode |
| Flashing (500 ms) | Inactivity warning — no visitors for configured period |
| Fast blink (100 ms) | System booting |

---

## 8. A+B Coin Box Daughter Board Header

A 6-pin header connects the optional A+B coin box daughter board.
When no daughter board is installed, the **external pull-up resistors**
(R4, R5, R6) hold the three input pins HIGH, and the firmware
correctly disables the coin box feature.

### Mainboard wiring (Rev 2 — with pull-ups)

```
    +3.3 V ──┬──────────┬──────────┐
             │          │          │
            [R4]       [R5]       [R6]    ← 10 kΩ each
            10kΩ       10kΩ       10kΩ
             │          │          │
    GPIO 36 ─┤  GPIO 39 ┤  GPIO 35 ┤
             │          │          │
             │          │          │
             ▼          ▼          ▼
          Header      Header     Header
          Pin 1       Pin 2      Pin 3

    Header Pin 4 ──── +3.3 V (power for daughter board optocouplers)
    Header Pin 5 ──── GND
    Header Pin 6 ──── +5 V (optional, for daughter board LED drive)
```

### 6-pin header pinout

| Pin | Signal | Direction | Notes |
|-----|---|---|---|
| 1 | COIN_SENSE (GPIO 36) | Input | Coin weight switch |
| 2 | BTN_A (GPIO 39) | Input | Button A (collect coins) |
| 3 | BTN_B (GPIO 35) | Input | Button B (refund coins) |
| 4 | +3.3 V | Power | Supplies daughter board |
| 5 | GND | Power | Common ground |
| 6 | +5 V | Power | Optional — for optocoupler LED drive |

### Why external pull-ups are essential

GPIO 36, 39, and 35 are **input-only** pins on the ESP32. Unlike
regular GPIOs, they do **not** support the internal pull-up resistor
(`INPUT_PULLUP` has no effect on these pins). Without external pull-ups:

- The pins float at an indeterminate voltage
- Random LOW readings during the 2-second boot detection window
  cause the firmware to falsely detect a daughter board
- Once falsely detected, the coin box logic blocks normal call flow
  (waits for Button A press that never comes)

The 10 kΩ pull-ups hold the pins at 3.3 V (HIGH). When the daughter
board is connected, its optocoupler outputs pull the pins LOW through
a lower impedance (~1 kΩ), overriding the pull-ups cleanly.

---

## 9. Protection Diodes

The LINE_B net is shared between the L293D output (48 V during ringing),
the opto LED leg (R_LIM → D1 → PC817 anode), and the transformer
secondary (via Cc). Without protection, the ring voltage damages the
optocoupler and can back-feed into the DAC.

### R_LIM + D1 — opto LED current limit and reverse block (Rev 2.1)

```
    Terminal 2 (LINE_B) ──[R_LIM 2.2 kΩ]──►|── PC817 pin 1 (Anode)
                                          D1
                                       (1N4148,
                                    anode→Line B side)

    PC817 pin 2 (Cathode) ──── GND
```

**R_LIM (1.5–2.2 kΩ)** sits in series in the opto LED leg and limits
both the off-hook loop current (~4–5 mA) and, crucially, the **48 V ring
current (~22 mA at 2.2 kΩ)**. It is **mandatory** — R1 is on the Line A
side and does not protect this leg (see the Section 2 safety warning:
omitting R_LIM cooked the opto *and* the ESP32 on the bench).

**D1 in series** (anode toward Line B, cathode toward the LED anode)
passes the off-hook / dial loop current but **blocks the reverse half of
the 48 V ring**, so the LED is never reverse-biased. Because D1 is in
series, the old anti-parallel clamp diode is no longer used.

### D2–D5 — DAC overvoltage clamps

```
    +5V ──────────┬──────────────┐
                  │              │
              D2 cathode    D4 cathode
              D2 anode      D4 anode
                  │              │
              DAC_LP          DAC_LN
              (J_SPK pin 1)   (J_SPK pin 2)
                  │              │
              D3 cathode    D5 cathode
              D3 anode      D4 anode
                  │              │
    GND ──────────┴──────────────┘
```

These four diodes clamp the transformer primary voltage to between
−0.7 V and +5.7 V. During normal audio playback the DAC output stays
within 0–5 V, so the diodes do not conduct. During ringing, any
coupled voltage that exceeds these limits is safely shunted to the
+5 V or GND rail.

---

## Master Interconnect Table

Every wire in the system, listed by destination:

| From | To | Wire/Note |
|---|----|---|
| **12 V adapter +** | Buck converter IN+ | Logic power in |
| **12 V adapter +** | R1 (470 Ω) top end | Line sense supply |
| **12 V adapter -** | Common GND bus | Ground reference |
| **48 V adapter +** | L293D pin 8 (VS) | Bell power |
| **48 V adapter -** | Common GND bus | Ground reference (join to 12 V GND) |
| Buck converter OUT+ (5 V) | ESP32 VIN pin | Logic power |
| Buck converter OUT+ (5 V) | MAX98357A VIN | DAC power |
| Buck converter OUT+ (5 V) | L293D pin 16 (VSS) | H-bridge logic |
| Buck converter OUT+ (5 V) | SD card module VCC | SD card power |
| Buck converter OUT+ (5 V) | Header pin 6 | Daughter board (optional) |
| ESP32 3.3 V | PC817 Collector (pin 4) | Optocoupler pull-up |
| ESP32 3.3 V | R4, R5, R6 (top) | Coin box GPIO pull-ups |
| ESP32 3.3 V | Header pin 4 | Daughter board power |
| ESP32 3.3 V | SD card VCC (if 3.3 V module) | Some modules need 3.3 V |
| R1 (470 Ω) bottom | Terminal 1 (Line A) | Line A feed (R2 deleted in Rev 2.1) |
| Terminal 2 (Line B) | R_LIM (2.2 kΩ) top | Opto LED leg current limit |
| R_LIM (2.2 kΩ) bottom | D1 anode | Series limit → reverse block |
| D1 cathode (1N4148) | PC817 Anode (pin 1) | Loop drive, reverse-blocked |
| PC817 Cathode (pin 2) | GND | Loop return to ground |
| PC817 Emitter (pin 3) | GPIO 34 + R3 to GND | Hook/dial sense |
| L293D OUT1 (pin 3) | Terminal 3 (Blue/Bell) | Ring signal |
| L293D OUT2 (pin 6) | Terminal 2 (White/Line B) | Ring return |
| L293D pins 4,5,9,12,13 | GND | All GND pins connected |
| MAX98357A L+ | Transformer primary 1 | Audio out |
| MAX98357A L- | Transformer primary 2 | Audio out |
| Transformer secondary 1 | Cc → Terminal 1 (Red/Line A) | Audio to phone via DC-block cap Cc |
| Transformer secondary 2 | Terminal 2 (White/Line B) | Audio to phone |
| GPIO 32 | RING button → GND | Control panel |
| GPIO 33 | CANCEL button → GND | Control panel |
| GPIO 27 | RESET button → GND | Control panel |
| GPIO 14 | MODE button → GND | Control panel |
| GPIO 13 | Panel lamp → GND | Status indicator |
| GPIO 36 | Header pin 1 (+ R4 to 3.3 V) | Coin sense |
| GPIO 39 | Header pin 2 (+ R5 to 3.3 V) | Button A |
| GPIO 35 | Header pin 3 (+ R6 to 3.3 V) | Button B |
| D1 anode | R_LIM bottom (Line B leg) | Series diode (blocks reverse ring) |
| D1 cathode | PC817 Anode (pin 1) | Series diode (blocks reverse ring) |
| D2 anode | DAC_LP (J_SPK pin 1 / T1 pri 1) | Positive clamp on L+ |
| D2 cathode | +5V rail | Positive clamp on L+ |
| D3 anode | GND | Negative clamp on L+ |
| D3 cathode | DAC_LP (J_SPK pin 1 / T1 pri 1) | Negative clamp on L+ |
| D4 anode | DAC_LN (J_SPK pin 2 / T1 pri 2) | Positive clamp on L- |
| D4 cathode | +5V rail | Positive clamp on L- |
| D5 anode | GND | Negative clamp on L- |
| D5 cathode | DAC_LN (J_SPK pin 2 / T1 pri 2) | Negative clamp on L- |
| Terminal 1 | Red wire (Line A) | Phone cord |
| Terminal 2 | White wire (Line B) | Phone cord |
| Terminal 3 | Blue wire (Bell) | Phone cord |

---

## PCB Layout Guide (Rev 2)

### Board zones

Organise the prototype board into clearly separated zones to avoid
interference and make assembly/debugging easier:

```
    ┌─────────────────────────────────────────────────────────────┐
    │  ZONE A: POWER                                              │
    │  ┌──────────────────────────┐  ┌────────────────┐           │
    │  │  12 V barrel jack        │  │  48 V barrel   │           │
    │  │  Buck converter module   │  │  jack           │           │
    │  │  5 V / GND bus start     │  │  48 V bus       │           │
    │  └──────────────────────────┘  └────────────────┘           │
    │  GND tie point (12 V GND ── 48 V GND) ●                    │
    ├─────────────────────────────────────────────────────────────┤
    │  ZONE B: ESP32 + DEV ACCESS                                 │
    │  ┌──────────────────────────────────────────────┐           │
    │  │  ESP32 DevKit V1 (30-pin, 2×15 headers)      │           │
    │  │  ○ ○ ○ ○ ○ ○ ○ ○ ○ ○ ○ ○ ○ ○ ○              │           │
    │  │  █ █ █ █ █ █ █ █ █ █ █ █ █ █ █              │  ← ESP32  │
    │  │  █ █ █ █ █ █ █ █ █ █ █ █ █ █ █              │  module   │
    │  │  ○ ○ ○ ○ ○ ○ ○ ○ ○ ○ ○ ○ ○ ○ ○              │           │
    │  │           USB port → board edge               │           │
    │  └──────────────────────────────────────────────┘           │
    │  ○ = dev access hole (1 per pin, adjacent to each ESP32 pin)│
    ├─────────────────────────────────────────────────────────────┤
    │  ZONE C: PERIPHERALS                   │  HIGH VOLTAGE     │
    │  ┌──────────────────────────┐          │  ┌──────────────┐ │
    │  │  MAX98357A DAC module    │          │  │  L293D        │ │
    │  │  SD card module          │          │  │  (DIP-16)     │ │
    │  │  Audio transformer       │          │  │  48 V traces  │ │
    │  │  PC817 optocoupler       │          │  │  Bell output  │ │
    │  │  R1, R2, R3              │          │  └──────────────┘ │
    │  └──────────────────────────┘          │                   │
    ├─────────────────────────────────────────────────────────────┤
    │  ZONE D: PROTECTION DIODES                                  │
    │  ┌──────────────┐  ┌──────────────────────────────────────┐ │
    │  │  D1 (1N4007)  │  │  D2, D3 (DAC_LP clamps)             │ │
    │  │  PC817 prot   │  │  D4, D5 (DAC_LN clamps)             │ │
    │  └──────────────┘  └──────────────────────────────────────┘ │
    ├─────────────────────────────────────────────────────────────┤
    │  ZONE E: CONNECTORS                                         │
    │  ┌────────────┐ ┌────────────┐ ┌──────┐ ┌──────────────┐  │
    │  │ 3-way screw │ │ 4× button  │ │ Lamp │ │ 6-pin header │  │
    │  │ terminal    │ │ headers    │ │ conn │ │ (daughter bd) │  │
    │  │ (phone cord)│ │ (RING,     │ │      │ │              │  │
    │  │             │ │  CANCEL,   │ │      │ │              │  │
    │  │             │ │  RESET,    │ │      │ │              │  │
    │  │             │ │  MODE)     │ │      │ │              │  │
    │  └────────────┘ └────────────┘ └──────┘ └──────────────┘  │
    └─────────────────────────────────────────────────────────────┘
```

### Development access holes

Every ESP32 pin gets **one additional through-hole pad** adjacent to it
on the board. These are connected to the same net as the ESP32 pin but
are left unpopulated. Purpose:

- Probe with a multimeter or oscilloscope during development
- Solder temporary jumper wires for testing new features
- Attach clip leads without disturbing the main wiring

Arrange them in a single row running parallel to each side of the ESP32
module, spaced 2.54 mm (standard 0.1" pitch).

### Layout rules

1. **Keep the high-voltage area (L293D / 48 V) physically separated**
   from Zone B (ESP32) and the audio section. Minimum 10 mm clearance
   between 48 V traces and logic traces.
2. **Use a ground plane.** Join analogue and digital grounds at a single
   point near the ESP32.
3. The optocoupler (PC817) provides **galvanic isolation** — do not
   bridge the isolation gap with other traces.
4. Place the **audio transformer close** to the phone terminal block
   to minimise audio trace length.
5. **L293D heat dissipation** — the GND pins (4, 5, 12, 13) also serve
   as the heat sink. Connect them to a generous copper pour on the
   ground plane.
6. **Decoupling capacitors:** Place a 100 nF ceramic capacitor between
   L293D pin 16 (VSS) and GND, close to the IC. Place a 100 nF ceramic
   between the 5 V bus and GND near the ESP32 VIN pin.
7. **Pull-up resistors R4/R5/R6** should be placed close to the 6-pin
   daughter board header, not near the ESP32. This keeps the pull-up
   path short and clean.
8. **D1** should be placed close to the PC817 (Zone D, near Zone C
   peripherals). D2–D5 should be near the DAC speaker terminal (J_SPK).
9. **48 V trace width:** Use 0.75–1.0 mm traces for +48V, BELL, and
   LINE_B nets. Use 0.5 mm for +5V/+12V/+3V3 power rails. Increase
   clearance around 48 V nets to 0.5 mm minimum.

### Recommended board size

**100 mm × 100 mm** double-sided prototype board (standard size,
available from most PCB suppliers). The extra height accommodates
Zone D (protection diodes) with clear separation between all zones.

---

## ESP32 DevKit V1 Pin Map

Complete pin usage table. Pins marked **DEV** are unused by the
firmware and available via the development access holes.

| Pin | GPIO | Function | Direction | Notes |
|-----|---|---|---|---|
| D2 | 2 | Status LED | Output | On-board LED |
| D4 | 4 | Bell EN (L293D EN1,2) | Output | PWM for bell volume |
| D5 | 5 | SD card CS | Output | SPI chip select |
| D13 | 13 | Panel lamp | Output | Auto-mode indicator |
| D14 | 14 | MODE button | Input | Pull-up in firmware |
| D16 | 16 | Bell IN1 (L293D) | Output | H-bridge phase A |
| D17 | 17 | Bell IN2 (L293D) | Output | H-bridge phase B |
| D18 | 18 | SD card SCK | Output | SPI clock |
| D19 | 19 | SD card MISO | Input | SPI data in |
| D22 | 22 | I2S DIN (MAX98357A) | Output | Audio data |
| D23 | 23 | SD card MOSI | Output | SPI data out |
| D25 | 25 | I2S LRCLK | Output | Audio word select |
| D26 | 26 | I2S BCLK | Output | Audio bit clock |
| D27 | 27 | RESET button | Input | Pull-up in firmware |
| D32 | 32 | RING button | Input | Pull-up in firmware |
| D33 | 33 | CANCEL button | Input | Pull-up in firmware |
| D34 | 34 | Line sense (ADC) | Input | Analogue, input-only |
| D35 | 35 | Coin BTN_B | Input | Input-only, ext pull-up R6 |
| SVN (D36) | 36 | Coin SENSE | Input | Input-only, ext pull-up R4 |
| SVP (D39) | 39 | Coin BTN_A | Input | Input-only, ext pull-up R5 |
| VIN | — | +5 V power in | Power | From buck converter |
| 3V3 | — | +3.3 V out | Power | For optocoupler + pull-ups |
| GND | — | Ground | Power | Common ground bus |
| EN | — | Enable (reset) | — | Leave unconnected (has on-board pull-up) |
| D12 | 12 | DEV | — | Boot-sensitive (avoid pull-high at boot) |
| D15 | 15 | DEV | — | Outputs PWM at boot (may cause brief pulse) |
| D21 | 21 | DEV | — | Available |
| TX0 | 1 | Serial TX | Output | USB serial (debug) |
| RX0 | 3 | Serial RX | Input | USB serial (debug) |

> **Note:** This project uses the **30-pin** ESP32 DevKit V1 (2×15 pin
> headers). GPIO 0 is on the module but not broken out as a header pin —
> it is accessible via the on-board BOOT button. All GPIOs used by the
> firmware are available on the 30-pin version. Position the ESP32 with
> the **USB port facing the board edge** for easy cable access.

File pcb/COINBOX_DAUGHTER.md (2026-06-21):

# A+B Coin Box Daughter Board

Universal optocoupler-isolated interface board for connecting any GPO A+B
coin collecting box mechanism to the K6 GPO Exhibit carrier board.

## Board Specs

- **Size:** 45 x 35 mm, 2-layer, all through-hole
- **Power:** 3.3V from carrier board (pull-ups) + 5V from carrier board (optocoupler LED drive)
- **Isolation:** 3x optocouplers provide galvanic isolation between A+B box contacts and ESP32

## Circuit (per channel)

```
A+B box contact             Daughter board                    Carrier board
--------------+     +--------------------------------+     +--------------
              |     |  VCC_5V --> J_in pin 1 (C+)    |     |
  Switch -----+-----+- (dry contact across J_in)     |     |
              |     |  J_in pin 2 (C-) -> R(470R)    |     |
              |     |         -> Opto LED -> GND     |     |
              |     |                                |     |
              |     |  Opto collector -- R_pull(10k)--+-->--+ VCC_3V3
              |     |  Opto collector ----------------+-->--+ GPIO (36/39/35)
              |     |  Opto emitter -----------------+-->--+ GND
              |     |                                |     |
--------------+     +--------------------------------+     +--------------
```

**Contact OPEN:**  No current flows, opto LED off -> output pulled HIGH by 10k -> ESP32 reads HIGH
**Contact CLOSED:** 5V -> R(470R) -> LED = 8mA -> opto on -> output pulled LOW -> ESP32 reads LOW

## Connector Pinouts

### J1 -- Coin Sense Input (2-pin screw terminal)

| Pin | Label | Function |
|-----|---|---|
| 1 | C+ | VCC_5V output (drive voltage to switch) |
| 2 | C- | Switch return -> R1 -> opto LED -> GND |

Connect the A+B box balance arm (Spring Assembly No. 2) dry contacts across pins 1-2.

### J2 -- Button A Input (2-pin screw terminal)

| Pin | Label | Function |
|-----|---|---|
| 1 | A+ | VCC_5V output (drive voltage to switch) |
| 2 | A- | Switch return -> R2 -> opto LED -> GND |

Connect the A+B box Button A dry contacts across pins 1-2.

### J3 -- Button B Input (2-pin screw terminal)

| Pin | Label | Function |
|-----|---|---|
| 1 | B+ | VCC_5V output (drive voltage to switch) |
| 2 | B- | Switch return -> R3 -> opto LED -> GND |

Connect the A+B box Button B dry contacts across pins 1-2.

### J4 -- Output Header (6-pin, to carrier board)

Pin order matches carrier board J_COIN header for straight ribbon cable connection.

| Pin | Label | Connect To (carrier board J_COIN) |
|-----|---|---|
| 1 | COIN | ESP32 GPIO 36 (coin sense) |
| 2 | A | ESP32 GPIO 39 (Button A) |
| 3 | B | ESP32 GPIO 35 (Button B) |
| 4 | 3V3 | +3.3V rail (powers pull-ups R4/R5/R6) |
| 5 | GND | Ground |
| 6 | 5V | +5V rail (powers optocoupler LEDs via input side) |

## Components

| Ref | Component | Value | Purpose |
|-----|---|---|---|
| U1 | Optocoupler (DIP-4) | PC817 / EL817 | Coin sense isolation |
| U2 | Optocoupler (DIP-4) | PC817 / EL817 | Button A isolation |
| U3 | Optocoupler (DIP-4) | PC817 / EL817 | Button B isolation |
| R1 | Resistor | 470R 1/4W | Coin opto LED current limit |
| R2 | Resistor | 470R 1/4W | Button A opto LED current limit |
| R3 | Resistor | 470R 1/4W | Button B opto LED current limit |
| R4 | Resistor | 10K 1/4W | Coin output pull-up |
| R5 | Resistor | 10K 1/4W | Button A output pull-up |
| R6 | Resistor | 10K 1/4W | Button B output pull-up |
| J1 | Screw terminal | 2-pos, 5.08mm | Coin sense input |
| J2 | Screw terminal | 2-pos, 5.08mm | Button A input |
| J3 | Screw terminal | 2-pos, 5.08mm | Button B input |
| J4 | Pin header | 1x6, 2.54mm | Output to carrier board |

## Wiring Guide -- Which A+B Box Contacts to Use

The A+B mechanism uses numbered spring assemblies. The exact terminal
numbering varies by mechanism variant, but the function is the same:

### Mechanism No. 14 (most common, used in BCC No. 14/14A/14D/14DD)

| Signal | Spring Assembly | What It Does |
|---|---|---|
| **COIN (J1)** | Spring Assembly No. 2 | Balance arm -- closes when sufficient coins are in the basket |
| **BTN A (J2)** | Spring Assembly No. 1 (A-button path) | Closes momentarily when Button A is pressed |
| **BTN B (J3)** | Spring Assembly No. 1 (B-button path) | Closes momentarily when Button B is pressed |

### Mechanism No. 13 (earlier type, BCC No. 13)

Same spring assembly functions but uses bullet-style brass connectors
instead of the U-spring plug. Identify the balance arm contact and
A/B button contacts from the mechanism wiring diagram (N.215).

### General Approach (any A+B box)

1. **Identify the coin weight/balance arm contact** -- this closes when
   coins are sitting in the mechanism basket. Connect across it to J1.
2. **Identify the Button A contact** -- closes when Button A is pressed
   to collect coins. Connect across it to J2.
3. **Identify the Button B contact** -- closes when Button B is pressed
   to refund coins. Connect across it to J3.

**No external power needed** -- VCC_5V is supplied on pin 1 of each
screw terminal from the carrier board. The A+B box contacts are
simple dry switches; when they close, they bridge pin 1 to pin 2
and 8mA flows through the optocoupler LED. No external voltage
source is required.

### Testing Without an A+B Box

You can test the daughter board with a simple jumper wire or
momentary switch across any screw terminal pair. Shorting J1 should
cause the ESP32 serial output to show coin detection; shorting J2/J3
should trigger Button A/B events.

## Auto-Detection

The firmware automatically detects whether the daughter board is
installed at boot. GPIO 36/39/35 are input-only pins with no
internal pull-up on the ESP32. When the daughter board is connected,
the 10k pull-ups hold these pins HIGH. If any pin reads LOW during
the 2-second boot window (indicating an optocoupler is active), the
coin box feature is enabled.

When no daughter board is connected, the pins float and the firmware
disables all coin logic -- the phone operates exactly as a normal
exhibit phone with no coin requirement.

## Reference

- [britishtelephones.com -- Mechanism No. 14](https://www.britishtelephones.com/mech14.htm)
- [britishtelephones.com -- How A&B Works](https://www.britishtelephones.com/howaandb.htm)
- [britishtelephones.com -- Coin Box Wiring Diagrams](https://www.britishtelephones.com/ccbwiring.htm)

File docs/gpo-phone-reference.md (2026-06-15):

# GPO 232 & 332 Telephone — Technical Reference

## Overview

The **GPO Telephone No. 232** (1935) and **No. 332** (1937) are classic British
Post Office Bakelite rotary-dial telephones.  Both use a 3-core cord to
connect to the line, and neither requires modification for this project.

| Feature | No. 232 | No. 332 |
|---|---|---|
| Internal bell | **No** — requires external Bellset No. 26 | **Yes** — bell + 2 µF capacitor fitted |
| Induction coil | No. 20 (Mk1) / No. 27 (Mk2) | No. 27 |
| DC resistance (off-hook) | ~150-200 Ω | ~150-200 Ω |
| Handset | No. 164 (carbon mic + electromagnetic receiver) | No. 164 |
| Dial | Automatic No. 10 series | Automatic No. 10 series |
| Cord | 3-core, spade-terminal or wrapped-loop | 3-core |

## 3-Core Cord Wiring

The cord from the phone terminates in three wires.  Colours may vary on
restored phones, but the original convention is:

| Wire | Colour (original) | Function | Internal terminal |
|---|---|---|---|
| Line A | Red | Line pair — through hook switch to circuit | T9 (332) |
| Line B | White | Line pair — return | T1 (332) |
| Bell | Blue | Bell / earth — via 2 µF cap to bell (332) | T11 (332) |

> **GPO 232 note:** Because the 232 has no internal bell, the blue wire
> connects to the external Bellset.  If no bellset is fitted, only the red
> and white wires are needed for basic phone operation (hook, dial, audio).

## Rotary Dial Pulse Characteristics

The GPO Dial Automatic No. 10 produces:

- **Pulse rate:** 10 impulses per second (ips), tolerance 9-11 ips
- **Break/make ratio:** approximately 2:1 (66 ms break, 33 ms make)
- **Digit encoding:** N pulses = digit N (digit 0 = 10 pulses)
- **Off-normal contacts:** short-circuit the receiver during dialling to
  suppress clicks in the earpiece

From the exchange (our ESP32) side, a dialled digit appears as a series
of brief current interruptions on the line pair.

## Hook Switch

The hook switch is a set of spring contacts actuated by the handset cradle.
Placing the handset on the cradle opens the line circuit; lifting it closes
the circuit and allows DC current to flow.

- **On-hook:** open circuit (~∞ Ω across line pair)
- **Off-hook:** ~150-200 Ω (induction coil + carbon microphone bias)

## Bell Ringing

### GPO 332 (internal bell)
The bell coils are connected between T11 (bell wire) and one side of the
line pair, in series with a 2 µF capacitor.  The capacitor blocks DC and
passes the AC ringing signal.

- **Frequency:** 25 Hz (UK standard)
- **Voltage:** 50-75 V AC peak-to-peak nominal, though many bells will
  operate from as low as 30 V AC
- **UK cadence:** 400 ms ON, 200 ms OFF, 400 ms ON, 2000 ms OFF (3 s cycle)

### GPO 232 (external bellset)
The Bellset No. 26 contains the bell and ringing capacitor.  It connects
between the line pair and earth.  The same ring signal drives it.

## Carbon Microphone

The handset (Telephone No. 164) contains a carbon-granule transmitter that
requires DC bias current to operate.  In normal exchange operation this
current (~20-30 mA) is supplied by the 48 V exchange battery through the
line.  Our interface board provides this via a 12 V supply and series
resistor.  The microphone modulates the line current, producing an audio
signal.

## Earpiece / Receiver

The electromagnetic receiver in the handset is driven by audio-frequency
AC on the line, coupled through the phone's induction coil.  Nominal
impedance is around 300 Ω.

## References

- [British Telephones — Telephone No. 232](https://www.britishtelephones.com/t232.htm)
- [British Telephones — Telephone No. 332](https://www.britishtelephones.com/t332.htm)
- Diagram N332 (circuit diagram for No. 332)
- Diagram N4300 (connecting No. 232 to Bellset No. 26)

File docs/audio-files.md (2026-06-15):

# Audio Files Required

This document lists all audio files the firmware expects on the SD card. Files are organised into directories by purpose.

## SD Card Directory Structure

```
/
├── system/            System sounds and configuration
├── history/           Exhibit history tracks (played at random)
├── numbers/           Audio keyed by dialled number
├── plugins/           JSON dial sequence scripts (not audio)
└── logs/              Auto-generated logs and stats (do not edit)
```

---

## /system/ — System Sounds

These are the core audio files the firmware looks for by exact path.

| File | Required | Description |
|---|---|---|
| `dialtone.mp3` | **Yes** | Continuous dial tone played when the handset is lifted. Should loop cleanly. |
| `busy.mp3` | **Yes** | Busy/error tone played when a call cannot be connected. Should loop cleanly. |
| `not_recognised.mp3` | **Yes** | "The number you have dialled has not been recognised" announcement. Plays when a dialled number has no matching file or alias. |
| `ringing_tone.mp3` | **Yes** | UK ringing tone (ring-ring ... ring-ring). Played through the earpiece while waiting for a connection. |
| `replace_handset.mp3` | Recommended | End-of-call reminder. Played after audio finishes to prompt the visitor to hang up. |
| `insert_coins.mp3` | Optional | A+B coin box only. "Insert coins now" prompt played when the coin box is active. |
| `press_a.mp3` | Optional | A+B coin box only. "Press Button A to connect" instruction. |
| `press_b.mp3` | Optional | A+B coin box only. "Press Button B for your money back" instruction. |

### /system/ — Configuration Files (auto-managed)

These JSON files are created and updated automatically by the firmware via the web UI. Do not edit manually.

| File | Purpose |
|---|---|
| `settings.json` | All device settings (volume, bell, ring timing, idle alert, etc.) |
| `aliases.json` | Number-to-filename mappings configured in the Number Directory |

---

## /history/ — Exhibit History Tracks

MP3 files in this directory are picked **at random** when a visitor answers an auto-ring call (or when no specific number is dialled). These are the main exhibit content — the stories, recordings, and historical audio that visitors hear.

**Naming:** Any `.mp3` filename works. The firmware scans the directory and picks randomly. Suggested convention: `001.mp3`, `002.mp3`, etc., or descriptive names like `history_of_k6.mp3`.

**Examples:**
```
/history/001_history_of_k6_phone_box.mp3
/history/002_local_area_1950s.mp3
/history/003_telephone_exchange_story.mp3
/history/004_post_office_memories.mp3
```

**Requirements:**
- At least one `.mp3` file is needed for the exhibit to play content
- Files should be standard MP3 format (CBR or VBR, any bitrate)
- Recommended: 128kbps mono or stereo for good quality vs. file size balance

---

## /numbers/ — Dialled Number Audio

When a visitor dials a number, the firmware looks for a matching file in this directory. The filename is determined by the Number Directory (aliases) configured in the web UI.

**How it works:**
1. Visitor dials `999`
2. Firmware checks aliases — finds `999` → `emergency`
3. Firmware plays `/numbers/emergency.mp3`

If no alias exists, the firmware tries `/numbers/999.mp3` directly (literal number as filename).

**Examples:**
```
/numbers/emergency.mp3        (mapped from 999)
/numbers/operator.mp3         (mapped from 100)
/numbers/speaking_clock.mp3   (mapped from 123)
/numbers/weather.mp3          (mapped from 200)
```

**Requirements:**
- Standard MP3 format
- Filename must match the alias name (or the literal dialled number if no alias)
- No limit on the number of files

---

## /plugins/ — Dial Sequence Scripts

JSON files that define custom multi-step sequences triggered by dialling specific numbers. These are **not audio files** but they reference audio files.

**Naming:** `<number>.json` — e.g., `999.json` is triggered when `999` is dialled.

**Example** (`/plugins/999.json`):
```json
{
  "steps": [
    {"action": "play", "file": "/system/siren.mp3"},
    {"action": "delay", "ms": 2000},
    {"action": "play", "file": "/numbers/emergency.mp3"}
  ]
}
```

**Available actions:**

| Action | Parameters | Description |
|---|---|---|
| `play` | `file` (path) | Play an MP3 file, advance when finished |
| `delay` | `ms` (milliseconds) | Wait for the specified time |
| `loop` | `file` (path), `ms` (milliseconds) | Play file on loop for the specified time |

**Notes:**
- Maximum 10 steps per plugin
- Plugins are checked **before** normal number/alias lookup (they take priority)
- Any audio files referenced in plugin steps must exist at the specified path

---

## /logs/ — Auto-generated (Do Not Edit)

These files are created and managed automatically by the firmware.

| File | Purpose |
|---|---|
| `system.log` | Boot events, errors, Wi-Fi, SD card, mode changes, OTA updates |
| `calls.log` | Incoming/outgoing call records with timestamps |
| `stats.json` | Visitor statistics (ring count, answer count, call durations, etc.) |
| `boot_count.txt` | Boot counter for log rotation |

---

## Audio Format Guidelines

- **Format:** MP3 (`.mp3`)
- **Bitrate:** 128kbps recommended (64–320kbps supported)
- **Sample rate:** 44.1kHz or 22.05kHz
- **Channels:** Mono or stereo (mono recommended — the telephone earpiece is mono)
- **Quality note:** The audio plays through a vintage telephone earpiece with limited frequency response (~300Hz–3.4kHz), so high-fidelity recordings are not necessary. Clear speech at 128kbps mono is ideal.

## Quick Setup Checklist

To get a working exhibit, you need at minimum:

1. Create the directories: `/system/`, `/history/`, `/numbers/`, `/plugins/`, `/logs/`
2. Add the four required system files to `/system/`:
   - `dialtone.mp3`
   - `busy.mp3`
   - `not_recognised.mp3`
   - `ringing_tone.mp3`
3. Add at least one history track to `/history/`
4. Optionally add number-specific audio to `/numbers/`
5. Optionally add `replace_handset.mp3` to `/system/`
6. Insert the SD card and power on — the firmware creates `/logs/` and config files automatically

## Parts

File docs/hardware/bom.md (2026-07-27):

# Bill of Materials (Rev 2)

> **Revision 2** — updated for dual DC supply (12 V + 48 V), four
> control buttons, external pull-ups, and panel lamp.

## Power Supply

| Qty | Component | Value / Part | Purpose | Approx. Cost |
|-----|---|---|---|---|
| 1 | 12 V DC adapter | 12 V / 1 A, barrel-jack wall-wart | Logic power | £5 |
| 1 | 48 V DC adapter | 48 V / 1 A, barrel-jack wall-wart | Bell power | £10-15 |
| 1 | Buck converter module | LM2596 adjustable (set to 5 V) | 12 V → 5 V for ESP32 and peripherals | £1-2 |

> **Rev 2 change:** The XL6009 boost converter has been removed. Bell
> power comes directly from the 48 V adapter, eliminating the component
> that caused voltage dips and ESP32 brownouts during ringing.

## Controller & Audio

| Qty | Component | Value / Part | Purpose | Approx. Cost |
|-----|---|---|---|---|
| 1 | ESP32 DevKit V1 | ESP-WROOM-32 | Main controller | £6 |
| 1 | MAX98357A I2S DAC module | — | Audio output to phone earpiece | £2 |
| 1 | Micro-SD card module | SPI breakout | MP3 file storage | £1 |
| 1 | Micro-SD card | ≥ 1 GB, FAT32 | Stores audio files and settings | £3 |

## Phone Line Interface

| Qty | Component | Value / Part | Purpose | Approx. Cost |
|-----|---|---|---|---|
| 1 | Optocoupler | PC817 (DIP-4) | Hook/dial isolation + detection | £0.30 |
| 1 | H-bridge motor driver | L293D (DIP-16) | Bell ring generator | £1.50 |
| 1 | Audio transformer | 600 Ω : 600 Ω 1:1 | Phone line audio coupling | £2 |

## Passive Components

| Qty | Component | Value | Label | Purpose |
|-----|---|---|---|---|
| 1 | Resistor | 470 Ω, 1 W | R1 | Line current limit (12 V to phone) |
| 1 | Resistor | 2.2 kΩ, ¼ W | R7 (R_LIM) | **Opto LED leg current limit — limits off-hook (~5 mA) AND 48 V ring (~22 mA). MANDATORY (Rev 2.1)** |
| 1 | Resistor | 470 Ω, ¼ W | R2 | Shunt across PC817 LED (pin 1 ↔ pin 2) — diverts coupling-cap leakage so the opto only lights on real off-hook current (required when C3 is an electrolytic) |
| 1 | Resistor | 10 kΩ, ¼ W | R3 | Pull-down for optocoupler output (GPIO 34) |
| 3 | Resistor | 10 kΩ, ¼ W | R4, R5, R6 | **Pull-ups for coin box GPIOs (36, 39, 35)** |
| 2 | Capacitor (ceramic) | 100 nF | C1, C2 | Decoupling: C1 at L293D VSS, C2 at ESP32 VIN |
| 1 | Capacitor (electrolytic) | 10 µF / 63 V radial, **+ toward Line A** | C3 (Cc) | **DC-block coupling cap in series with transformer secondary — MANDATORY (Rev 2.1). Blocks the ~120 Ω DC short that otherwise kills hook/dial + saturates the core.** As-built uses a forward-biased electrolytic + R2 shunt (bench-proven). A non-polar film/bipolar ≥63 V part is the cleaner production choice and removes the need for R2. |

> **Rev 2.1 change:** The optocoupler is now wired *in series* in the
> loop return leg (Line B → R7/R_LIM → D1 → LED → GND), not bridged
> across the line. Added **R7 (R_LIM)** (current limit, mandatory before
> applying 48 V) and **C3 (Cc)** (DC-block coupling cap on the transformer
> secondary). **R2 is repurposed** as a 470 Ω shunt across the PC817 LED
> (pin 1 ↔ pin 2) to divert the electrolytic coupling-cap's small DC
> leakage. Without R7, the 48 V ring cooks the opto and ESP32; without
> C3, the transformer DC-shorts the line and hook/dial detection cannot
> work. (If C3 is a non-polar film cap, R2 can be omitted.)

## Protection Diodes

| Qty | Component | Value / Part | Label | Purpose |
|-----|---|---|---|---|
| 1 | Rectifier diode | 1N4007 (DO-41) | D1 | **In series** in opto LED leg (anode→Line B via R7) — blocks reverse half of 48 V ring (Rev 2.1). 1N4148 also works; 1N4007 fitted as-built. |
| 4 | Rectifier diode | 1N4007 (DO-41) | D2–D5 | Overvoltage clamps on transformer primary (DAC_LP and DAC_LN to +5V and GND) |

> **Why these are needed:** During bell ringing, L293D OUT2 drives LINE_B
> between 0 V and 48 V. The opto LED leg (R_LIM → D1 → PC817) and the
> transformer secondary (via Cc) are also on LINE_B. **R_LIM** limits the
> forward ring current through the LED and **D1 (in series)** blocks the
> reverse half, so the LED is protected both ways. Without D2–D5, the
> coupled ring voltage can back-feed through the transformer primary into
> the MAX98357A output pins.

> **Rev 2 change:** Added R4/R5/R6 pull-up resistors. These are
> essential — GPIO 36/39/35 are input-only and have no internal
> pull-up. Without these, the firmware falsely detects an A+B coin
> box. Also removed the LM2596 discrete components (inductor, Schottky
> diode, electrolytic caps) since we now use a pre-built module.

## Control Panel

| Qty | Component | Notes |
|-----|---|---|
| 4 | Momentary push buttons | RING / CANCEL / RESET / MODE |
| 1 | Panel lamp | 3-6 V LED or filament indicator lamp |

> **Rev 2 change:** Added MODE button (GPIO 14) — was missing from
> Rev 1 BOM but required by firmware. Added panel lamp.

## Connectors & Mechanical

| Qty | Component | Notes |
|-----|---|---|
| 1 | 3-way screw terminal block | Phone cord connection (Line A, Line B, Bell) |
| 2 | Barrel jack sockets (2.1 mm) | 12 V and 48 V power inputs |
| 1 | 6-pin header (2.54 mm) | A+B coin box daughter board connector |
| 2 | 15-pin female headers | ESP32 DevKit V1 (30-pin) sockets (allows removal) |
| 1 | Project box / enclosure | Houses all electronics + buttons |
| 1 | Multi-core cable (≥ 6 conductors) | Extended lead from phone to enclosure |
| 1 | Custom carrier PCB | 100 × 100 mm, 2-layer |
| — | Hook-up wire, solder, standoffs | Assembly |

## Optional — A+B Coin Box Daughter Board

Small add-on board for connecting a GPO A+B coin collecting box mechanism.
Plugs into the 6-pin header on the carrier board.

| Qty | Component | Value / Part | Purpose | Approx. Cost |
|-----|---|---|---|---|
| 3 | Optocoupler (DIP-4) | PC817 / EL817 | Isolate A+B box contacts from ESP32 | £0.90 |
| 3 | Resistor | 470 Ω, ¼ W | Optocoupler LED current limit | £0.10 |
| 3 | Screw terminal | 2-pos, 5.08 mm pitch | A+B box contact inputs | £0.60 |
| 1 | Pin header | 1×6, 2.54 mm | Output to carrier board 6-pin header | £0.10 |
| 1 | Daughter board PCB | 45 × 35 mm | — | £2 |
| — | Hook-up wire | 22–26 AWG | A+B box to daughter board wiring | £1 |
| | | | **Daughter board subtotal** | **~£5** |

> **Rev 2 change:** The 10 kΩ pull-up resistors that were on the
> daughter board in Rev 1 have been moved to the **carrier board**
> (R4/R5/R6). This ensures the pull-ups are always present even when
> the daughter board is not connected.

## Optional — Other

| Qty | Component | Purpose |
|-----|---|---|
| 1 | Electromagnetic bell (Bellset No. 26) | External bell for GPO 232 |
| 1 | USB Micro-B cable | For reprogramming / serial debug |
| 1 | 3D-printed enclosure | Tidier than a generic project box |
| 1 | 2N2222 NPN transistor | For driving a filament panel lamp (not needed for LED) |
| 1 | 1 kΩ resistor | Base resistor for 2N2222 (if using filament lamp) |
| 1 | 100 Ω resistor | Series resistor for LED panel lamp (if using LED) |

## Total Estimated Cost

| Category | Cost |
|---|---|
| Power supply (12 V adapter + 48 V adapter + buck module) | ~£18 |
| Controller + audio (ESP32 + DAC + SD) | ~£12 |
| Phone line interface (opto + H-bridge + transformer) | ~£4 |
| Passives (resistors, capacitors, diodes) | ~£3 |
| Connectors, buttons, lamp | ~£5 |
| **Total** | **~£42** |

*Excludes: phone, SD card content, enclosure, extended cable.*

## Where to Buy (UK)

- **Amazon UK** — ESP32 DevKit, LM2596 modules, SD card modules, 48 V adapters
- **RS Components / Mouser** — L293D, resistors, capacitors, barrel jack sockets
- **eBay** — PC817 optocouplers, 600 Ω audio transformers, push buttons, 48 V PSUs
- **CPC/Farnell** — Resistors, capacitors, screw terminals, headers
- **AliExpress** — Cheapest for modules (longer delivery)
- **Pimoroni / The Pi Hut** — ESP32 boards, breakout modules

## Rev 1 → Rev 2 Component Changes Summary

| Removed | Added | Reason |
|---|---|---|
| XL6009 boost converter module | 48 V DC adapter | Direct bell power, no boost needed |
| LM2596 bare IC + inductor + Schottky + caps | LM2596 pre-built module | Simpler, fewer discrete components |
| — | 3× 10 kΩ pull-up resistors (R4/R5/R6) | Fix false A+B detection |
| — | MODE button (4th button) | Was in firmware but missing from BOM |
| — | Panel lamp + driver components | Auto-mode status indicator |
| — | 2nd barrel jack socket | Separate 48 V power input |
| — | 6-pin header | Standardised daughter board connector |
| — | 2× 15-pin female headers | ESP32 30-pin DevKit V1 socket (allows removal for dev) |
| — | 100 nF decoupling cap (C2) | Noise filtering at ESP32 VIN |
| — | 5× 1N4007 rectifier diodes (D1–D5) | PC817 reverse voltage protection + DAC overvoltage clamps |

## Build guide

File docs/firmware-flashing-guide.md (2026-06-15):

# Firmware Flashing Guide

Step-by-step instructions for flashing the K6 GPO Exhibit firmware to an ESP32 for the first time. Covers Windows, macOS, and Linux.

## What You Need

- **ESP32 DevKit** (ESP32-WROOM-32 or similar) — the board that goes on the carrier PCB
- **USB cable** — micro-USB or USB-C depending on your ESP32 board
- **Computer** — Windows 10/11, macOS 12+, or Ubuntu/Debian Linux
- **Internet connection** — to download tools and libraries (first time only)

---

## Step 1: Install Python

PlatformIO requires Python 3.6 or later. Check if you already have it:

```
python3 --version
```

### Windows

1. Download the latest Python from [python.org/downloads](https://www.python.org/downloads/)
2. Run the installer
3. **Important:** Tick the box that says **"Add Python to PATH"** before clicking Install
4. Open a new Command Prompt and verify: `python --version`

### macOS

Python 3 is included on recent macOS versions. If not:

```bash
brew install python
```

If you don't have Homebrew, install it first from [brew.sh](https://brew.sh).

### Linux (Ubuntu/Debian)

```bash
sudo apt update
sudo apt install python3 python3-pip python3-venv
```

---

## Step 2: Install PlatformIO

PlatformIO is the build system used to compile and flash the firmware. Install it via pip:

### All Platforms

```bash
pip install platformio
```

Or if `pip` isn't on your PATH:

```bash
python3 -m pip install platformio
```

Verify it installed correctly:

```bash
pio --version
```

You should see something like `PlatformIO Core, version 6.x.x`.

> **Alternative: VS Code Extension**
>
> If you prefer a graphical interface, install [Visual Studio Code](https://code.visualstudio.com/) and then install the **PlatformIO IDE** extension from the Extensions marketplace. This gives you a GUI for building and flashing. The commands below still work in the VS Code terminal.

---

## Step 3: Install USB Drivers

The ESP32 DevKit uses a USB-to-serial chip to communicate with your computer. You may need to install the driver for it.

### Identify Your Chip

Look at the largest chip near the USB connector on your ESP32 board:

| Chip | Markings | Driver |
|---|---|---|
| CP2102 | "SILABS CP2102" | [Silicon Labs CP210x](https://www.silabs.com/developers/usb-to-uart-bridge-vcp-drivers) |
| CH340 | "CH340G" or "CH340C" | [WCH CH340](http://www.wch-ic.com/downloads/CH341SER_ZIP.html) |
| CP2104 | "CP2104" | Same as CP2102 (Silicon Labs) |

### Windows

1. Download the driver for your chip from the link above
2. Run the installer
3. Restart your computer if prompted
4. Plug in the ESP32 — it should appear in Device Manager under **Ports (COM & LPT)** as `COM3`, `COM4`, etc.

### macOS

- **CP2102**: Download and install from [Silicon Labs](https://www.silabs.com/developers/usb-to-uart-bridge-vcp-drivers). You may need to allow the kernel extension in **System Settings → Privacy & Security**.
- **CH340**: Download and install from [WCH](http://www.wch-ic.com/downloads/CH341SER_MAC_ZIP.html). On macOS Ventura+, you may need to allow the driver in **System Settings → Privacy & Security**.

After installing, plug in the ESP32. Check it appears:

```bash
ls /dev/cu.usbserial* /dev/cu.SLAB_USBtoUART* 2>/dev/null
```

You should see something like `/dev/cu.usbserial-0001` or `/dev/cu.SLAB_USBtoUART`.

### Linux (Ubuntu/Debian)

Most Linux kernels include drivers for both CP2102 and CH340 out of the box. No manual installation needed.

Plug in the ESP32 and check:

```bash
ls /dev/ttyUSB* /dev/ttyACM* 2>/dev/null
```

You should see `/dev/ttyUSB0` or similar.

**Permission fix** — if you get "Permission denied" errors when flashing:

```bash
sudo usermod -a -G dialout $USER
```

Then **log out and back in** (or restart) for the group change to take effect.

---

## Step 4: Download the Project

Clone or download the repository:

```bash
git clone https://github.com/opmedia-dev/k6_gpo_exhibit.git
cd k6_gpo_exhibit
```

Or download as a ZIP from GitHub and extract it.

---

## Step 5: Connect the ESP32

1. Plug the ESP32 into your computer via USB
2. Wait a few seconds for the driver to initialise
3. Confirm the device is detected:

**Windows:**
Open Device Manager → Ports (COM & LPT). Note the COM port number (e.g., `COM3`).

**macOS:**
```bash
ls /dev/cu.usbserial* /dev/cu.SLAB_USBtoUART*
```

**Linux:**
```bash
ls /dev/ttyUSB* /dev/ttyACM*
```

If nothing appears, try a different USB cable — some cables are charge-only and don't carry data.

---

## Step 6: Compile the Firmware

Navigate to the firmware directory and compile:

```bash
cd firmware
pio run
```

The first time you run this, PlatformIO will automatically:
- Download the ESP32 platform tools (~200MB)
- Download the Arduino framework for ESP32
- Download the required libraries (ESP32-audioI2S, ArduinoJson)
- Compile the firmware

This may take **2-5 minutes** the first time. Subsequent builds take ~10 seconds.

You should see output ending with:

```
RAM:   [==        ]  19.5% (used 63856 bytes from 327680 bytes)
Flash: [=======   ]  66.4% (used 1304733 bytes from 1966080 bytes)
========================= [SUCCESS] Took X.XX seconds =========================
```

If you see `[SUCCESS]`, the firmware compiled correctly and you're ready to flash.

---

## Step 7: Flash the Firmware

With the ESP32 still plugged in:

```bash
pio run -t upload
```

PlatformIO will automatically detect the correct port. If it can't find the ESP32, specify the port manually:

**Windows:**
```bash
pio run -t upload --upload-port COM3
```

**macOS:**
```bash
pio run -t upload --upload-port /dev/cu.usbserial-0001
```

**Linux:**
```bash
pio run -t upload --upload-port /dev/ttyUSB0
```

You should see:

```
Uploading .pio/build/esp32dev/firmware.bin
esptool.py v4.x
...
Writing at 0x00010000... (100%)
Wrote XXXXXX bytes
Hash of data verified.
Leaving...
Hard resetting via RTS pin...
========================= [SUCCESS] Took X.XX seconds =========================
```

The ESP32 will automatically reboot with the new firmware.

---

## Step 8: Verify It's Working

Open the serial monitor to see the boot output:

```bash
pio device monitor
```

You should see output similar to:

```
[boot] K6 GPO Exhibit v1.2.0
[boot] SD card: OK
[boot] WiFi AP: K6-Exhibit (password: phonebox)
[boot] Web server started at 192.168.4.1
[boot] Ready
```

Press `Ctrl+C` to exit the serial monitor.

### Connect to the Web Interface

1. On your phone or laptop, connect to the Wi-Fi network **K6-Exhibit** (password: **phonebox**)
2. Open a browser and go to **http://192.168.4.1/**
3. You should see the K6 GPO Exhibit management interface

---

## Step 9: Prepare the SD Card

Before the exhibit is fully functional, you need an SD card with the required audio files. See [`docs/audio-files.md`](audio-files.md) for the complete list.

**Quick summary:**

1. Format a micro-SD card as **FAT32**
2. Create these directories: `/system/`, `/history/`, `/numbers/`
3. Add the required system files:
   - `/system/dialtone.mp3`
   - `/system/busy.mp3`
   - `/system/not_recognised.mp3`
   - `/system/ringing_tone.mp3`
4. Add at least one history track to `/history/` (e.g., `001.mp3`)
5. Insert the SD card into the ESP32's SD card module
6. Power cycle the ESP32

The `/logs/` and `/plugins/` directories are created automatically by the firmware.

You can also upload audio files wirelessly via the web interface after the SD card is inserted.

---

## Troubleshooting

### "No such file or directory: platformio" or "pio: command not found"

PlatformIO isn't on your PATH. Try running it via Python:

```bash
python3 -m platformio run
```

Or add the PlatformIO installation directory to your PATH:
- **Windows:** `%USERPROFILE%\.platformio\penv\Scripts`
- **macOS/Linux:** `~/.platformio/penv/bin`

### "Error: Failed to connect to ESP32: Timed out waiting for packet header"

- Press and hold the **BOOT** button on the ESP32 board while the upload starts, then release it when you see "Connecting..."
- Try a different USB cable (must be a data cable, not charge-only)
- Try a different USB port (preferably directly on the computer, not a hub)

### "Permission denied" on Linux

```bash
sudo usermod -a -G dialout $USER
```

Log out and back in, then retry.

### "Permission denied" on macOS (driver not loaded)

Go to **System Settings → Privacy & Security** and click **Allow** next to the blocked driver message. Then unplug and replug the ESP32.

### Compilation errors

Make sure you're in the `firmware/` directory (not the project root):

```bash
cd k6_gpo_exhibit/firmware
pio run
```

### ESP32 keeps rebooting (crash loop)

Connect the serial monitor (`pio device monitor`) and check the error output. Common causes:
- SD card not inserted or not formatted as FAT32
- SD card module not wired correctly

The firmware enters safe mode after 3 consecutive crashes within 10 seconds. In safe mode, only the Wi-Fi access point and web interface are active — you can use this to diagnose the issue or flash new firmware via OTA.

### "SD card: FAIL" in serial output

- Check the SD card is inserted and making good contact
- Verify the SD card is formatted as FAT32 (not exFAT or NTFS)
- Check the SPI wiring: CS=GPIO 5, MOSI=GPIO 23, MISO=GPIO 19, SCK=GPIO 18

---

## Updating Firmware Later

After the first flash, you have two options for updating:

### Option 1: USB (same as above)

```bash
cd firmware
pio run -t upload
```

### Option 2: Wireless (OTA)

1. Connect to the **K6-Exhibit** Wi-Fi network
2. Open **http://192.168.4.1/**
3. Scroll to **Update Firmware**
4. Click **Choose File** and select the `.bin` file from `firmware/.pio/build/esp32dev/firmware.bin`
5. Click **Install Update**
6. Wait for the upload to complete — the device will restart automatically

The firmware uses A/B partitioning, so if an OTA update fails, it automatically rolls back to the previous working version after 3 failed boots.

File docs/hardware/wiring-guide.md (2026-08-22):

# Wiring Guide (Rev 2)

> **Revision 2** — updated for dual DC supply, four buttons, external
> pull-ups, panel lamp, and 6-pin daughter board header.

## Before You Start

1. **Identify your phone model.**
   - GPO 232 — no internal bell (needs external Bellset No. 26)
   - GPO 332 — internal bell + 2 µF capacitor
2. **Check the cord wires.** Wire colours may vary on restored phones.
   Use a multimeter:
   - **Line pair:** two wires that show ~150-200 Ω when the handset is lifted
   - **Bell wire:** the third wire, high impedance to both line wires when on-hook
3. **Do not modify the phone.** All connections are to the free cord ends only.
4. **The ESP32 board lives in a separate enclosure**, connected to the phone
   via an extended multi-core cable.

---

## Parts You Need

| # | Part | Notes |
|---|---|---|
| 1 | ESP32 DevKit V1 (30-pin) | Main controller, USB port faces board edge |
| 2 | 12 V DC adapter (≥ 1 A) | Barrel jack, logic power |
| 3 | 48 V DC adapter (≥ 1 A) | Barrel jack, bell power |
| 4 | LM2596 buck converter module | Adjustable, set to 5 V output |
| 5 | PC817 optocoupler | Hook/dial detection |
| 6 | L293D H-bridge (DIP-16) | Bell ring generator |
| 7 | MAX98357A I2S DAC module | Audio output |
| 8 | Micro-SD card breakout module | SPI interface |
| 9 | 600 Ω : 600 Ω audio transformer | 1:1, telephone line coupling |
| 10 | 470 Ω resistor (1 W) | R1 — line current limit |
| 11 | 1.5–2.2 kΩ resistor (¼ W) | R_LIM — opto LED leg current limit (Rev 2.1, replaces R2). Mandatory before 48 V |
| 11b | 10 µF ≥63 V non-polar cap (or 2× 10 µF 63 V electrolytic back-to-back) | Cc — DC-block coupling cap on transformer secondary (Rev 2.1) |
| 11c | 1N4148 diode | D1 — series in opto LED leg, blocks reverse ring (Rev 2.1) |
| 12 | 10 kΩ resistor (¼ W) | R3 — pull-down on GPIO 34 |
| 13 | 3× 10 kΩ resistors (¼ W) | R4, R5, R6 — pull-ups on GPIO 36/39/35 |
| 14 | 2× 100 nF ceramic capacitors | C1, C2 — decoupling |
| 15 | 4× momentary push buttons | RING / CANCEL / RESET / MODE |
| 16 | 1× panel lamp (LED or filament) | Auto-mode indicator |
| 17 | 3-way screw terminal block | Phone cord connection |
| 18 | 2× barrel jack sockets | 12 V and 48 V power inputs |
| 19 | 1× 6-pin header (2.54 mm) | A+B daughter board connector |
| 20 | Prototype PCB | 100 × 80 mm minimum |
| 21 | Hook-up wire, solder | Assembly |

---

## Step 1: Set Up the Power Supplies

> **Do this first, before connecting any other components.**
> **Rev 2 uses two separate power supplies.**

### 1a. Buck converter (12 V → 5 V)

```
    12 V adapter (+) ──────► [LM2596 module IN+]
    12 V adapter (-) ──────► [LM2596 module IN-]

    Adjust trimpot until output reads 5.0 V on multimeter.

    [LM2596 module OUT+] = +5 V rail
    [LM2596 module OUT-] = GND rail
```

### 1b. 48 V supply (bell power)

```
    48 V adapter (+) ──────► +48 V rail (goes to L293D pin 8 only)
    48 V adapter (-) ──────► GND rail

    ⚠ CAUTION: 48 V can give a nasty tingle. Don't touch the output.
```

### 1c. Common ground

```
    12 V GND ──────┐
                   ├──── Common GND bus on the board
    48 V GND ──────┘

    Connect these at a SINGLE POINT near the L293D GND pins.
```

---

## Step 2: Wire the ESP32 DevKit

### 2a. Power

```
    +5 V rail ──────► ESP32 VIN pin
    GND rail ───────► ESP32 GND pin
```

> **Note:** Do not connect both USB and 12 V at the same time unless you
> add a diode on VIN to prevent back-feeding.

### 2b. Development access holes

For each ESP32 pin, solder an extra through-hole pad adjacent to it on
the prototype board, connected to the same trace. Leave these unpopulated
— they provide probe points and temporary connection points during
development.

---

## Step 3: Wire the Phone Cord Terminal Block

Strip ~5 mm from each wire of the 3-core cord:

```
    Terminal 1  ◄──  Red wire    (Line A)
    Terminal 2  ◄──  White wire  (Line B)
    Terminal 3  ◄──  Blue wire   (Bell)
```

---

## Step 4: Wire the Hook / Dial Detection Circuit

> **Rev 2.1 — opto is IN SERIES with the loop (R2 deleted).** The LED
> sits in the return leg with a current-limit resistor and a series
> diode: **+12 V → R1 → Line A → phone → Line B → R_LIM → D1 → LED →
> GND.** Do **not** wire the LED across Line A↔Line B (the old layout) —
> that carries no loop current and never detects hook or dial.

```
    +12 V ─── [R1 470 Ω 1W] ─── Terminal 1 (Red / Line A)

    Terminal 2 (White / Line B) ─── [R_LIM 2.2 kΩ] ─── D1 anode
    D1 cathode (1N4148, stripe) ─── PC817 pin 1 (Anode)
    PC817 pin 2 (Cathode) ─── GND

    PC817 pin 4 (Collector) ─── +3.3 V (ESP32 3V3 pin)
    PC817 pin 3 (Emitter) ─── GPIO 34
    PC817 pin 3 (Emitter) ─── [R3 10 kΩ] ─── GND
```

**PC817 pinout — check polarity carefully:**

```
    ┌──────────┐
    │  1  ●    │  Anode   ── DOT on package (from D1 cathode / Line B leg)
    │  2       │  Cathode ── to GND
    │  3       │  Emitter ── (to GPIO 34 + R3)
    │  4       │  Collector ── (to +3.3 V)
    └──────────┘
    Pin 1 is marked with a DOT on the IC.
    Current flows: pin 1 (anode) → pin 2 (cathode).
    D1 stripe (cathode) faces the PC817 anode; D1 body points at Line B.
```

> **Polarity is critical.** If the optocoupler or D1 is backwards, hook
> detection will not work. The dot on the package marks pin 1.
>
> **⚠️ Never apply the 48 V bell supply without R_LIM fitted.** Line B
> carries 48 V during ringing, and R_LIM is the only current limit in
> this leg (R1 is on the Line A side). On the bench, omitting R_LIM let
> the 48 V ring breach the opto and cook both the PC817 **and the
> ESP32**. R_LIM = 2.2 kΩ keeps the ring current to ~22 mA.

---

## Step 5: Wire the Ring Generator (L293D H-Bridge)

```
    L293D pin 1  (EN1,2)  ──── GPIO 4
    L293D pin 2  (IN1)    ──── GPIO 16
    L293D pin 7  (IN2)    ──── GPIO 17
    L293D pin 8  (VS)     ──── +48 V (from 48 V DC adapter)
    L293D pin 16 (VSS)    ──── +5 V
    L293D pin 3  (OUT1)   ──── Terminal 3 (Blue / Bell wire)
    L293D pin 6  (OUT2)   ──── Terminal 2 (White / Line B)
    L293D pins 4, 5, 9, 12, 13 ──── GND
```

> **All five GND pins must be connected.** They also act as the heat
> sink — connect them to a copper pour if possible.

**L293D pinout (DIP-16) — notch/dot at pin 1 end:**

```
          ┌────────┐
   EN1,2  │ 1●  16 │  VSS (+5V)
     IN1  │ 2   15 │  EN3,4 (n/c)
    OUT1  │ 3   14 │  IN4 (n/c)
     GND  │ 4   13 │  GND
     GND  │ 5   12 │  GND
    OUT2  │ 6   11 │  OUT4 (n/c)
     IN2  │ 7   10 │  IN3 (n/c)
 VS(48V)  │ 8    9 │  GND
          └────────┘
```

Place a **100 nF ceramic capacitor (C1)** between pin 16 (VSS) and the
nearest GND pin, as close to the IC as possible.

---

## Step 6: Wire the Audio Output (MAX98357A + Transformer)

```
    GPIO 26 ──── MAX98357A BCLK
    GPIO 25 ──── MAX98357A LRC
    GPIO 22 ──── MAX98357A DIN
    +5 V    ──── MAX98357A VIN
    GND     ──── MAX98357A GND

    MAX98357A L+ ──── Audio transformer PRIMARY pin 1
    MAX98357A L- ──── Audio transformer PRIMARY pin 2

    Audio transformer SECONDARY pin 1 ──[ Cc ]── Terminal 1 (Red / Line A)
    Audio transformer SECONDARY pin 2 ────────── Terminal 2 (White / Line B)
```

> **⚠️ Cc (DC-block coupling cap) is MANDATORY.** The transformer
> secondary is only ~70–120 Ω at DC, so wiring it directly across
> Terminal 1 ↔ Terminal 2 shorts the line at DC — this swamps the hook
> loop (detection fails) and saturates the core (distortion). Fit **Cc
> in series with one secondary leg**: 10 µF non-polar ≥63 V, **or** two
> 10 µF 63 V electrolytics back-to-back (− to −) ≈ 5 µF non-polar. This
> supersedes the old "10 Ω on the primary" note.

---

## Step 7: Wire the SD Card Module

```
    SD module pin order (left to right, facing pins):
    CS  SCK  MOSI  MISO  VCC  GND

    GPIO 5  ──── CS
    GPIO 18 ──── SCK (CLK)
    GPIO 23 ──── MOSI (DI)
    GPIO 19 ──── MISO (DO)
    +3.3 V  ──── VCC
    GND     ──── GND
```

> Most SD card modules have an on-board 3.3 V regulator, so you can
> safely connect VCC to 3.3 V or 5 V depending on the module. Check
> your module's documentation.

Place a **100 nF ceramic capacitor (C2)** between the ESP32 VIN pin
and GND, close to the ESP32 board.

---

## Step 8: Wire the Control Panel

### 8a. Four buttons

Four momentary push buttons, each wired between the GPIO pin and GND.
No external resistors — the ESP32 enables internal pull-ups in firmware.

```
    GPIO 32 ──── [RING button]   ──── GND
    GPIO 33 ──── [CANCEL button] ──── GND
    GPIO 27 ──── [RESET button]  ──── GND
    GPIO 14 ──── [MODE button]   ──── GND
```

> **Check each button with a multimeter** before soldering: when pressed,
> continuity between the two pins should read < 1 Ω. When released,
> open circuit.

### 8b. Panel lamp

For a 3 V LED with 100 Ω series resistor:

```
    GPIO 13 ──── [100 Ω] ──── LED anode (+)
                               LED cathode (-) ──── GND
```

> The longer LED leg is the anode (+). The flat side of the LED
> housing is the cathode (-).

For a 5-6 V filament lamp with transistor driver:

```
    GPIO 13 ──── [1 kΩ] ──── 2N2222 Base
                              2N2222 Emitter ──── GND
                              2N2222 Collector ── Lamp (-) terminal
                              Lamp (+) terminal ── +5 V
```

---

## Step 9: Wire the Coin Box Pull-Ups and Header

### 9a. Pull-up resistors (required even without daughter board)

```
    +3.3 V ──┬──────────┬──────────┐
             │          │          │
           [R4]       [R5]       [R6]
           10kΩ       10kΩ       10kΩ
             │          │          │
    GPIO 36 ─┘  GPIO 39 ┘  GPIO 35 ┘
```

> **These pull-ups are essential.** GPIO 36, 39, 35 have no internal
> pull-up. Without R4/R5/R6, the firmware falsely detects a coin box
> and blocks normal phone operation.

### 9b. 6-pin daughter board header

```
    Header Pin 1 ──── GPIO 36 (+ R4 pull-up to 3.3 V)
    Header Pin 2 ──── GPIO 39 (+ R5 pull-up to 3.3 V)
    Header Pin 3 ──── GPIO 35 (+ R6 pull-up to 3.3 V)
    Header Pin 4 ──── +3.3 V
    Header Pin 5 ──── GND
    Header Pin 6 ──── +5 V
```

Mount this header at the board edge for easy daughter board connection.

---

## Step 10: Prepare the SD Card

1. Format a micro-SD card as **FAT32**
2. Create directories and add MP3 files:

```
    /system/
        dialtone.mp3             ← Continuous dial tone (will loop)
        busy.mp3                 ← Busy/error tone (will loop)
        not_recognised.mp3       ← "The number you have dialled..."
    /history/
        001.mp3                  ← History tracks (random pick on answer)
        002.mp3
        003.mp3
    /numbers/
        999.mp3                  ← Plays when user dials 999
        100.mp3                  ← Plays when user dials 100
        08001111.mp3             ← Plays when user dials 08001111
```

3. Insert into the SD card module **before** powering on

See `docs/audio-files.md` for the complete list of required and optional
audio files.

---

## Testing Procedure

> **Quick start:** once the board boots, send `T` on serial (or the **self-test**
> button on the web Terminal tab) to run the whole checklist in one shot — SD,
> line-sense reading, bell strike, 1 kHz earpiece tone, panel buttons, coin box
> and heap. The individual tests below explain each item and how to fix failures.

### Commissioning commands (serial / web Terminal)

| Command | Serial | Web Terminal | Purpose |
|---|---|---|---|
| Self-test | `T` | `selftest` | One-shot bring-up checklist (PASS/FAIL/WARN). |
| Calibrate line | `K` | `calibrate on` then `calibrate off` | Capture on-hook + off-hook ADC levels and auto-set the hook thresholds, saved to `/system/settings.json`. Run this after any change to R_LIM or the opto leg. |
| Dial echo | `E` | `dialecho` | Toggle rotary self-confirm — each dialled digit is blinked on the panel lamp (0 = 10 blinks) so dialling can be verified with no laptop. |
| Dial ticks | `I` | `ticks` | Toggle the earpiece click heard on each rotary pulse (on by default), reproducing the ticks a real GPO dial makes as it runs back. Saved to `/system/settings.json`. |
| Audio probe | `Q` | `probe` | Play a 1 kHz tone and report the peak/RMS/crest of the samples fed to I2S (digital side only). |
| Line debug | `N` | — (serial only) | Stream raw `line=` values and dial `BREAK`/`make` pulse timing. |
| Wi-Fi report | `W` | — (serial only) | Link mode, channel, signal strength, connected clients, worst loop/web delay, then a survey of every network in range with per-channel congestion and the clearest of channels 1/6/11. Takes the radio off channel for a second or so. |
| Set channel | `W <1-13>` | Settings → Wi-Fi | Move the hotspot to a channel and restart to apply. Saved to `/system/settings.json`. |
| Request trace | `G` | — (serial only) | Log every HTTP request with the time spent handling it and the time it waited to be picked up — the fastest way to see which requests a slow page load is stuck on. |
| Clear timers | `Z` | `/api/status?reset=1` | Zero the loop/web/connection counters so a measurement covers a known window. |

### Test 1: Power (no phone connected)

1. Connect the **12 V adapter only** first. Do not connect 48 V yet.
2. Verify with a multimeter:
   - Buck converter output = **5.0 V** (±0.2 V)
3. Confirm the ESP32 boots — serial monitor (115200 baud) should show:
   ```
   K6 GPO Exhibit — ESP32 Phone Interface
   [audio] SD card ready
   [phone] controller ready
   ```
4. Verify the boot lamp indication: LED turns on, blinks, then bell
   strikes once when boot completes.
5. Now connect the **48 V adapter**. Verify 48 V at the L293D pin 8 with
   a multimeter.

### Test 2: Coin Box Detection

1. With **no daughter board connected**, check serial output at boot:
   ```
   [coin] no coin box detected — feature disabled
   ```
2. If it says "DETECTED" instead, check R4/R5/R6 pull-up wiring.

### Test 3: SD Card

1. Send `S` via serial. Check output shows `sd=OK`.
2. If `sd=FAIL`, check SPI wiring and card format.

### Test 4: Buttons

1. Send `S` via serial to check current state.
2. Press each button and verify serial output:
   - RING → `[app] RING pressed` (bell should ring if phone is on-hook)
   - CANCEL → `[app] CANCEL pressed` (stops ringing if active)
   - RESET → ESP32 reboots
   - MODE → `[app] MODE toggled` (switches auto/manual)
3. If a button doesn't respond:
   - Check continuity from GPIO pin to button terminal
   - Check continuity from other button terminal to GND
   - Verify button is not shorted (stuck low)

### Test 5: Hook Detection

1. Connect the phone's 3-core cord to the terminal block.
2. With handset **on the cradle**, send `S` — should show `hook=ON_HOOK`.
3. **Lift the handset** — serial should print:
   ```
   [app] hook: OFF_HOOK
   [phone] → DIAL_TONE
   ```
   You should hear the dial tone in the earpiece.
4. If on/off-hook aren't cleanly detected, run the calibration wizard: send
   `K` (or `calibrate on` / `calibrate off` in the web Terminal), which captures
   both ADC levels and sets the thresholds automatically — no need to edit
   `config.h`.

### Test 6: Rotary Dialling

1. With handset lifted, dial digit **5**.
2. Serial should print `[phone] digit: 5`. (Send `E` first to also blink each
   digit on the panel lamp for a hands-off check.)
   You should also hear a click in the earpiece on each pulse — the authentic
   GPO dialling sound. Send `I` (or `ticks`) to turn these clicks off.
3. Wait 3 seconds — if `/numbers/5.mp3` exists it plays, otherwise
   you'll hear "number not recognised".

### Test 7: Bell Ringing

1. Replace the handset (on-hook).
2. Send `R` via serial **or** press the RING button.
3. The bell should ring with the UK cadence (ring-ring, pause).
4. Lift the handset — ringing stops, a random history track plays.

### Test 8: Panel Lamp

1. Check the lamp turns on solid in AUTO mode.
2. Press MODE → lamp should turn off (MANUAL mode).
3. Press MODE again → lamp turns back on (AUTO mode).

---

## Troubleshooting

| Symptom | What to check |
|---|---|
| ESP32 doesn't boot | Check 5 V rail with multimeter. Ensure VIN (not 3.3 V) is connected to +5 V. |
| No hook detection | Confirm opto is wired IN SERIES (Line B → R_LIM → D1 → LED → GND), not across the line. Confirm Cc is fitted (a directly-connected transformer secondary DC-shorts the line and holds the opto saturated). Check opto + D1 orientation (dot = pin 1 = anode). Use the `N` serial command to watch the raw `line=` value swing on/off hook. |
| Dial pulses not counted | Enable the `N` serial command and dial — you should see `BREAK`/`make` pairs with `break_len` of ~20–120 ms. If the raw value doesn't drop below the off threshold on a break, run the `K` calibration wizard (or lower R_LIM). Calibration replaces the old need to hand-edit `LINE_THRESHOLD_ON/OFF` in `config.h`. |
| Bell doesn't ring | Verify 48 V at L293D pin 8. Check all 5 GND pins on L293D. GPO 232 needs an external bellset. |
| Bell too quiet | 48 V is lower than the GPO spec of 60-80 V. Consider a higher voltage adapter (up to 60 V — check L293D absolute max). |
| No audio / no sound | Check MAX98357A wiring (BCLK, LRC, DIN). Try `V9` serial command for max volume. Check transformer orientation. |
| Audio distorted | First run `Q` (audio probe) — a clean digital feed reads crest ≈ 1.41; a much lower ratio means the samples are already clipped before I2S (lower the line level / volume). If the digital side is clean, confirm Cc (DC-block cap) is fitted in series with the transformer secondary — without it, DC bias current saturates the core. If still distorted with Cc, listen at the amp output (MAX98357A L+/L−) with a small speaker: clean there ⇒ transformer at fault; distorted there ⇒ MAX98357A module at fault. |
| SD card not detected | Check SPI wiring (CS, MOSI, MISO, SCK). Ensure card is FAT32 formatted. Try a different card. |
| MP3 doesn't play | Check file paths match exactly (`/system/`, `/history/`, `/numbers/`). Ensure valid MP3 encoding. |
| Buttons don't work | Check wiring to GND. Verify correct GPIO numbers. Use multimeter to confirm button makes contact. |
| False A+B coin box detected | Check R4/R5/R6 (10 kΩ pull-ups to 3.3 V) on GPIO 36/39/35. All three must be present. |
| ESP32 resets during ring | Check GND tie point between 12 V and 48 V supplies. Add 470 µF capacitor on 5 V rail. |
| MODE button triggers at boot | Normal — GPIO 14 has internal pull-down during boot. Firmware ignores buttons until setup() completes. |
| Lamp doesn't light | Check LED polarity (long leg = anode = +). Check GPIO 13 goes HIGH with multimeter. |

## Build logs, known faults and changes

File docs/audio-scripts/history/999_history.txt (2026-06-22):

999 HISTORY — The World's First Emergency Number
=================================================
File: /history/999_history.mp3
Estimated duration: ~45 seconds

--- SCRIPT ---

Britain's nine-nine-nine emergency number was the world's first, introduced on the thirtieth of June, nineteen thirty-seven.

The idea came after a tragic fire in London, where five women died partly because neighbours struggled to reach the fire brigade by telephone. The GPO responded by creating a single, easy-to-remember number that would connect callers to police, fire, or ambulance services immediately.

The number nine was chosen deliberately. On a rotary dial, nine is the furthest hole from the finger stop, making it easy to find in the dark or in thick smoke simply by feel. Dialling three nines also gave the exchange equipment enough time to set up the priority connection.

The very first nine-nine-nine call was made in London on the first of July, nineteen thirty-seven. Within a week, over a thousand emergency calls had been received.

Today, nine-nine-nine handles over thirty million calls a year across the United Kingdom.

--- NOTES ---
- Serious, respectful tone for the fire tragedy
- Shift to informative and slightly impressed when discussing the design reasoning
- Clear, deliberate delivery of dates and numbers

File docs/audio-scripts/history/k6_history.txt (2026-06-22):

K6 HISTORY — The Story of the K6 Telephone Box
================================================
File: /history/k6_history.mp3
Estimated duration: ~45 seconds

--- SCRIPT ---

The iconic K6 telephone box is one of Britain's most recognisable landmarks.

Designed by architect Sir Giles Gilbert Scott, the K6 was introduced in 1935 to mark the Silver Jubilee of King George the Fifth. Its distinctive red colour made it easy to spot in towns, villages, and cities across the country.

More affordable than earlier designs, over sixty thousand K6 kiosks were installed, becoming a familiar part of everyday life. For decades, they connected communities, allowing people to make calls long before mobile phones existed.

As technology evolved, many telephone boxes disappeared, but thousands of K6 kiosks survive today. Some still serve as public telephones, while others have been transformed into libraries, defibrillator stations, and community information points.

Nearly a century after its introduction, the K6 remains a lasting symbol of British design, innovation, and public service.

--- NOTES ---
- Read in a warm, informative tone — museum documentary style
- Moderate pace, clear enunciation
- Brief pause between paragraphs

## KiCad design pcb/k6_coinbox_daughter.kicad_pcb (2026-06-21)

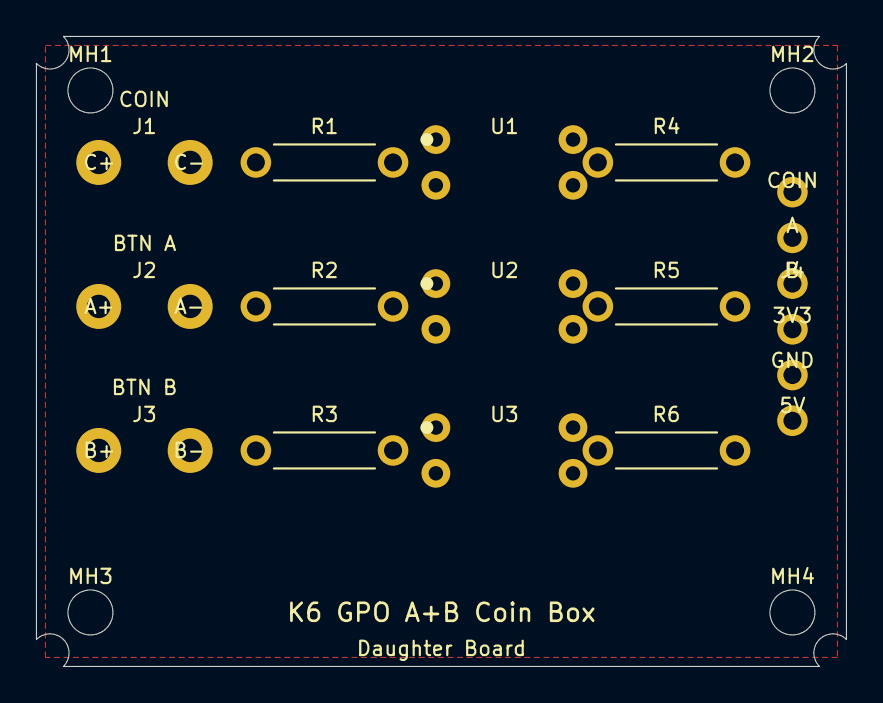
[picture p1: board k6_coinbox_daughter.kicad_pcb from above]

Board: 2 copper layers, 45.0 x 35.0 mm, 17 parts (0 on the bottom side), 12 nets, no tracks yet.

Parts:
J1: COIN; J1
J2: BTN_A; J2
J3: BTN_B; J3
J4: TO_ESP32; J4
MH1: MH; MH1
MH2: MH; MH2
MH3: MH; MH3
MH4: MH; MH4
R1: 470R; R1
R2: 470R; R2
R3: 470R; R3
R4: 10K; R4
R5: 10K; R5
R6: 10K; R6
U1: PC817; U1
U2: PC817; U2
U3: PC817; U3

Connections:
BTNA_IN_B: J2.2, R2.1
BTNB_IN_B: J3.2, R3.1
BTN_A: J4.2, R5.2, U2.4
BTN_B: J4.3, R6.2, U3.4
COIN_IN_B: J1.2, R1.1
COIN_SENSE: J4.1, R4.2, U1.4
GND: J4.5, U1.2, U1.3, U2.2, U2.3, U3.2, U3.3
OPTO1_CA: R1.2, U1.1
OPTO2_CA: R2.2, U2.1
OPTO3_CA: R3.2, U3.1
VCC_3V3: J4.4, R4.1, R5.1, R6.1
VCC_5V: J1.1, J2.1, J3.1, J4.6

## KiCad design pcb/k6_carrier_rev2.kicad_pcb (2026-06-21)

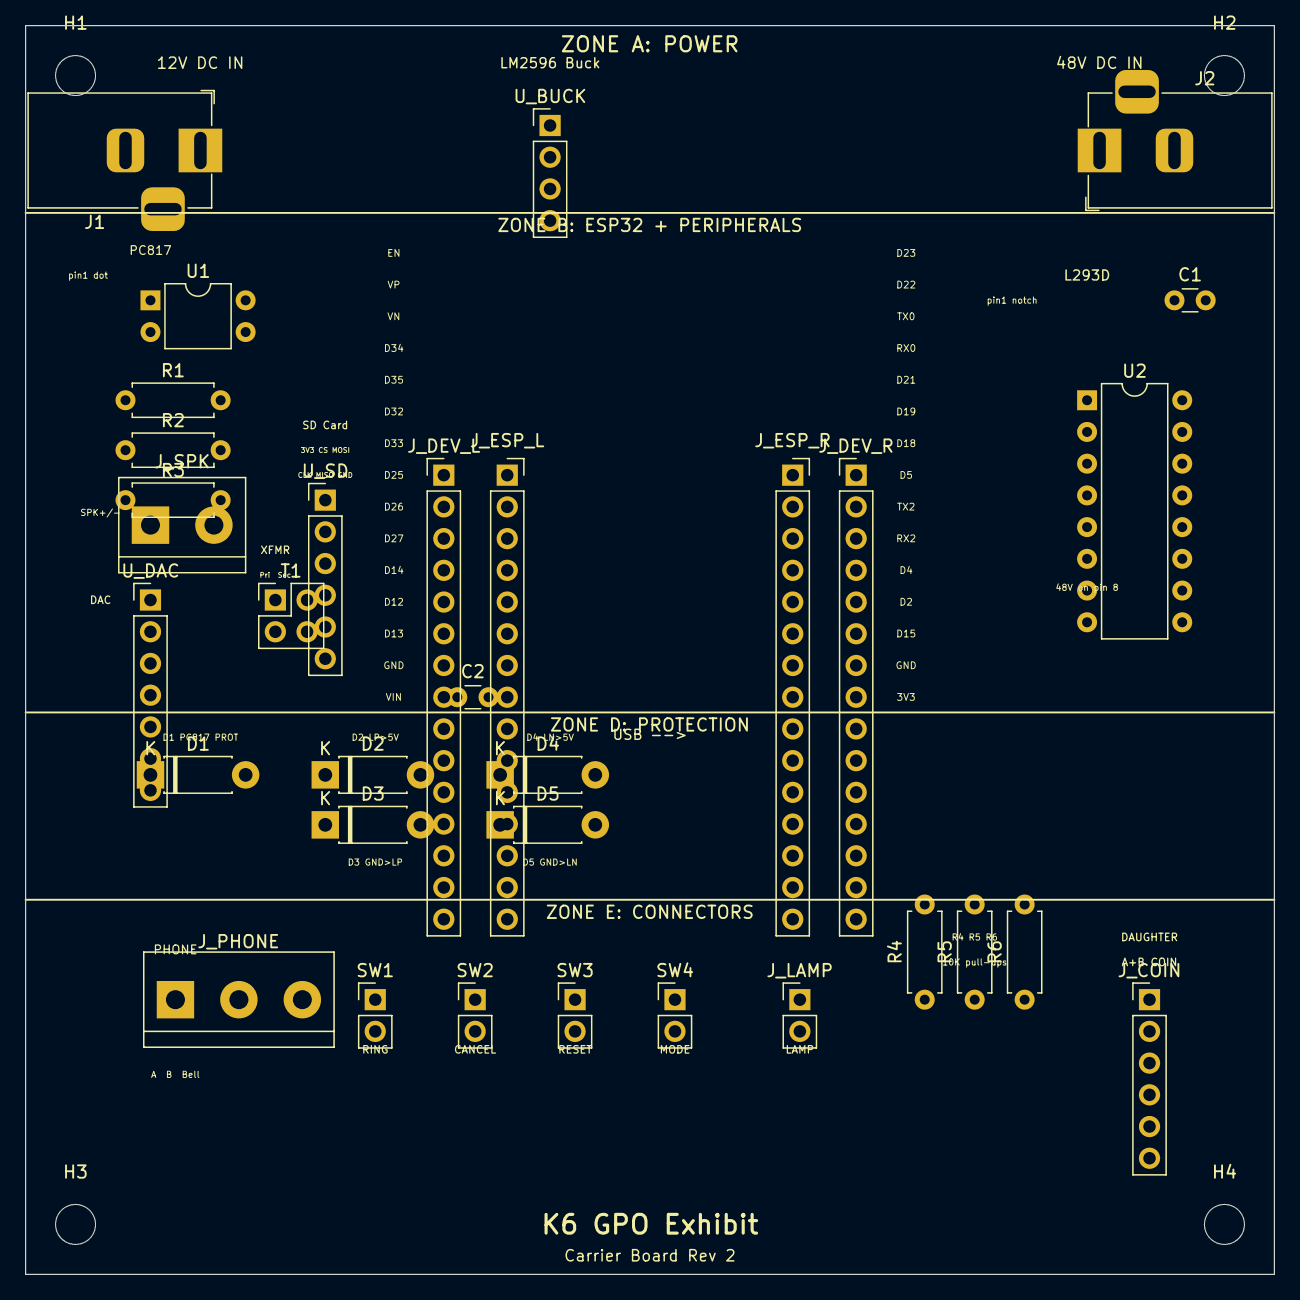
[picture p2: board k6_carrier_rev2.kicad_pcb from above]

Board: 2 copper layers, 100.0 x 100.0 mm, 37 parts (0 on the bottom side), 34 nets, no tracks yet.

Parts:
C1, C2: 100nF; C_Disc_D3.0mm_W1.6mm_P2.50mm
D1, D2, D3, D4, D5: 1N4007; D_DO-41_SOD81_P7.62mm_Horizontal
H1, H2, H3, H4: M3; MountingHole_3.2mm_M3
J1: 12V_DC; BarrelJack_Horizontal
J2: 48V_DC; BarrelJack_Horizontal
J_COIN: A+B; PinHeader_1x06_P2.54mm_Vertical
J_DEV_L: DEV_Left; PinHeader_1x15_P2.54mm_Vertical
J_DEV_R: DEV_Right; PinHeader_1x15_P2.54mm_Vertical
J_ESP_L: ESP32_Left; PinSocket_1x15_P2.54mm_Vertical
J_ESP_R: ESP32_Right; PinSocket_1x15_P2.54mm_Vertical
J_LAMP: Lamp; PinHeader_1x02_P2.54mm_Vertical
J_PHONE: Phone; TerminalBlock_bornier-3_P5.08mm
J_SPK: Speaker; TerminalBlock_bornier-2_P5.08mm
R1: 470R_1W; R_Axial_DIN0207_L6.3mm_D2.5mm_P7.62mm_Horizontal
R2: 220R; R_Axial_DIN0207_L6.3mm_D2.5mm_P7.62mm_Horizontal
R3, R4, R5, R6: 10K; R_Axial_DIN0207_L6.3mm_D2.5mm_P7.62mm_Horizontal
SW1: RING; PinHeader_1x02_P2.54mm_Vertical
SW2: CANCEL; PinHeader_1x02_P2.54mm_Vertical
SW3: RESET; PinHeader_1x02_P2.54mm_Vertical
SW4: MODE; PinHeader_1x02_P2.54mm_Vertical
T1: 600R_XFMR; PinHeader_2x02_P2.54mm_Vertical
U1: PC817; DIP-4_W7.62mm
U2: L293D; DIP-16_W7.62mm
U_BUCK: LM2596; PinHeader_1x04_P2.54mm_Vertical
U_DAC: MAX98357A; PinHeader_1x07_P2.54mm_Vertical
U_SD: SD_Card; PinHeader_1x06_P2.54mm_Vertical

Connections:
+3V3: J_COIN.4, J_DEV_R.1, J_ESP_R.1, R4.1, R5.1, R6.1, U1.4, U_SD.1
+5V: C1.1, C2.1, D2.2, D4.2, J_COIN.6, J_DEV_L.1, J_ESP_L.1, U2.16, U_BUCK.3, U_DAC.1
+12V: J1.1, R1.1, U_BUCK.1
+48V: J2.1, U2.8
BELL: J_PHONE.3, U2.3
DAC_LN: D4.1, D5.2, J_SPK.2, T1.3
DAC_LP: D2.1, D3.2, J_SPK.1, T1.1
GND: C1.2, C2.2, D3.1, D5.1, J1.2, J2.2, J_COIN.5, J_DEV_L.2, J_DEV_R.2, J_ESP_L.2, J_ESP_R.2, J_LAMP.2, R3.2, SW1.2, SW2.2, SW3.2, SW4.2, U2.4, U2.5, U2.9, U2.12, U2.13, U_BUCK.2, U_BUCK.4, U_DAC.2, U_SD.6
GPIO2: J_DEV_R.4, J_ESP_R.4
GPIO4: J_DEV_R.5, J_ESP_R.5, U2.1
GPIO5: J_DEV_R.8, J_ESP_R.8, U_SD.2
GPIO12: J_DEV_L.4, J_ESP_L.4
GPIO13: J_DEV_L.3, J_ESP_L.3, J_LAMP.1
GPIO14: J_DEV_L.5, J_ESP_L.5, SW4.1
GPIO15: J_DEV_R.3, J_ESP_R.3
GPIO16: J_DEV_R.6, J_ESP_R.6, U2.2
GPIO17: J_DEV_R.7, J_ESP_R.7, U2.7
GPIO18: J_DEV_R.9, J_ESP_R.9, U_SD.4
GPIO19: J_DEV_R.10, J_ESP_R.10, U_SD.5
GPIO21: J_DEV_R.11, J_ESP_R.11
GPIO22: J_DEV_R.14, J_ESP_R.14, U_DAC.5
GPIO23: J_DEV_R.15, J_ESP_R.15, U_SD.3
GPIO25: J_DEV_L.8, J_ESP_L.8, U_DAC.7
GPIO26: J_DEV_L.7, J_ESP_L.7, U_DAC.6
GPIO27: J_DEV_L.6, J_ESP_L.6, SW3.1
GPIO32: J_DEV_L.10, J_ESP_L.10, SW1.1
GPIO33: J_DEV_L.9, J_ESP_L.9, SW2.1
GPIO34: J_DEV_L.12, J_ESP_L.12, R3.1, U1.3
GPIO35: J_COIN.3, J_DEV_L.11, J_ESP_L.11, R6.2
GPIO36: J_COIN.1, J_DEV_L.14, J_ESP_L.14, R4.2
GPIO39: J_COIN.2, J_DEV_L.13, J_ESP_L.13, R5.2
LINE_A: J_PHONE.1, R1.2, R2.1, T1.2
LINE_B: D1.1, J_PHONE.2, T1.4, U1.2, U2.6
OPTO_A: D1.2, R2.2, U1.1

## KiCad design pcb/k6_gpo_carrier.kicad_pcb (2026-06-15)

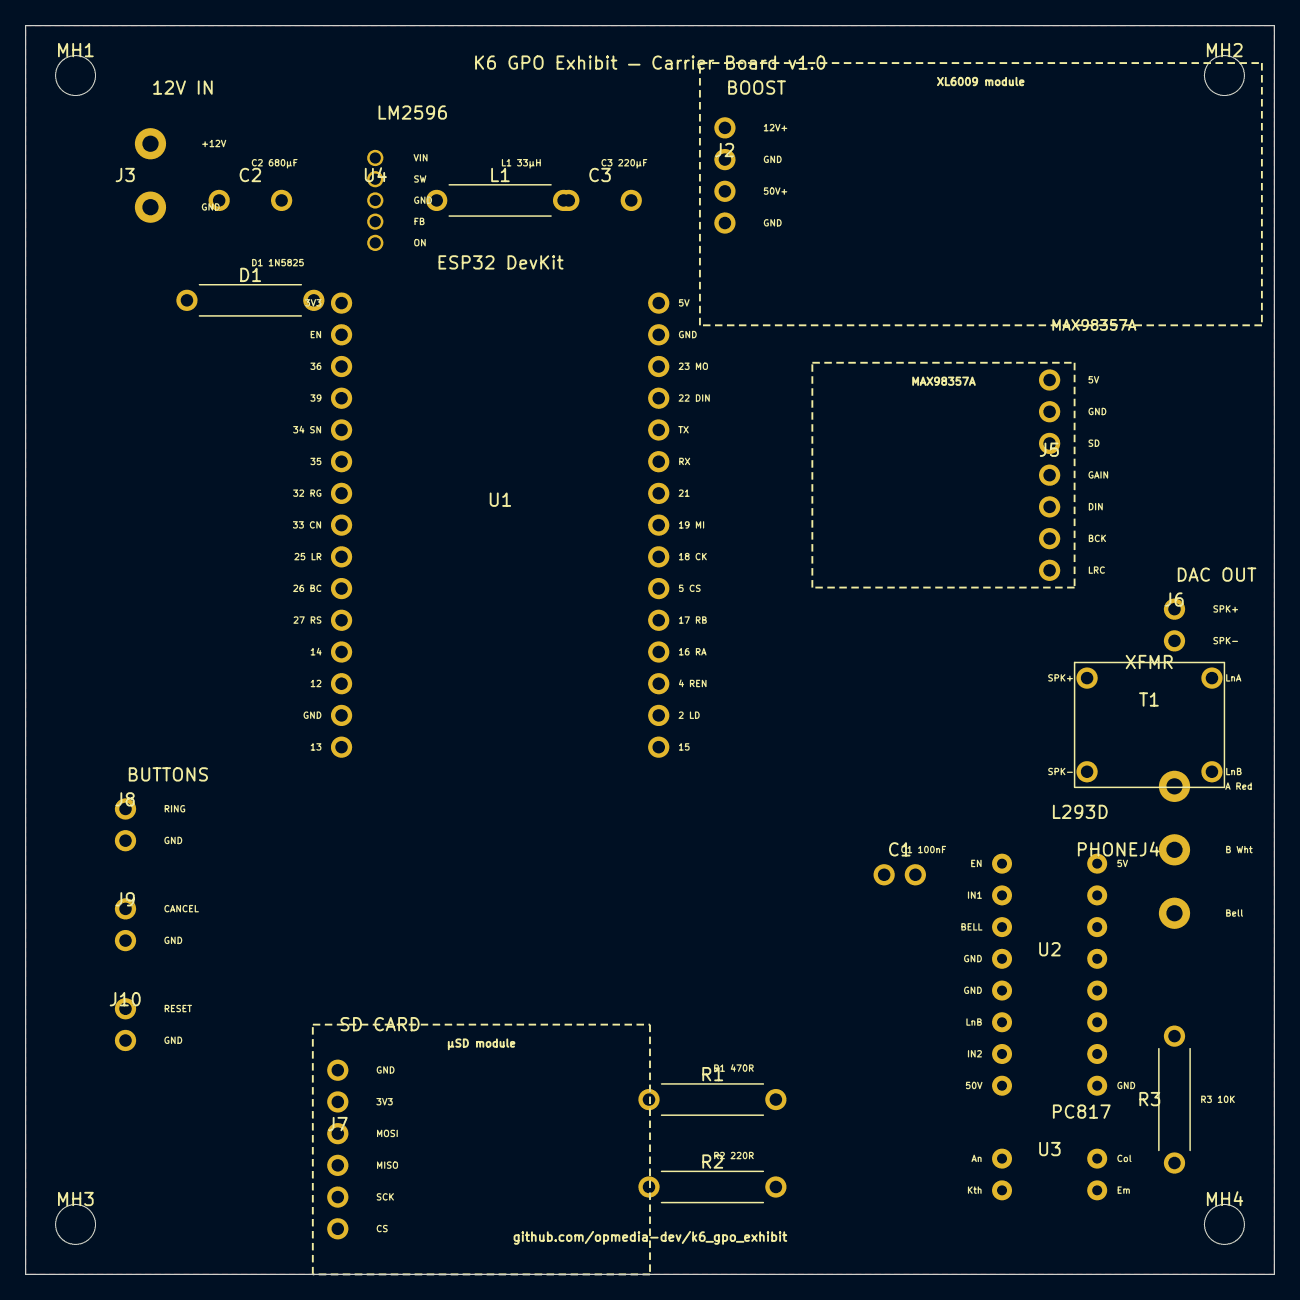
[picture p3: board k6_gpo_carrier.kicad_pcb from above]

Board: 2 copper layers, 100.0 x 100.0 mm, 26 parts (0 on the bottom side), 27 nets, no tracks yet.

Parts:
C1: 100nF; C1
C2: 680uF; C2
C3: 220uF; C3
D1: 1N5825; D1
J2: XL6009_Boost; J2
J3: 12V_IN; J3
J4: PHONE; J4
J5: MAX98357A; J5
J6: DAC_OUT; J6
J7: SD_Card; J7
J8: BTN_RING; J8
J9: BTN_CANCEL; J9
J10: BTN_RESET; J10
L1: 33uH; L1
MH1: MH; MH1
MH2: MH; MH2
MH3: MH; MH3
MH4: MH; MH4
R1: 470R; R1
R2: 220R; R2
R3: 10K; R3
T1: 600R_XFMR; T1
U1: ESP32_DevKit; U1
U2: L293D; U2
U3: PC817; U3
U4: LM2596-5.0; U4

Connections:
+3V3: J7.2, U1.L1, U3.4
+5V: C1.1, C3.1, J5.1, L1.2, U1.R1, U2.16, U4.4
+12V: C2.1, J2.1, J3.1, R1.1, U4.1
+50V: J2.3, U2.8
AUDIO_P1: J6.1, T1.1
AUDIO_P2: J6.2, T1.2
BELL: J4.3, U2.3
BTN_CANCEL: J9.1, U1.L8
BTN_RESET: J10.1, U1.L11
BTN_RING: J8.1, U1.L7
GND: C1.2, C2.2, C3.2, D1.1, J2.2, J2.4, J3.2, J5.2, J7.1, J8.2, J9.2, J10.2, R3.2, U1.L14, U1.R2, U2.4, U2.5, U2.9, U2.12, U2.13, U4.3, U4.5
I2S_BCLK: J5.6, U1.L10
I2S_DOUT: J5.5, U1.R4
I2S_LRCLK: J5.7, U1.L9
JUNC_A: R1.2, R2.1
LINE_A: J4.1, T1.3
LINE_B: J4.2, T1.4, U2.6, U3.2
OPTO_ANODE: R2.2, U3.1
OPTO_EMIT: R3.1, U3.3
RING_A: U1.R12, U2.2
RING_B: U1.R11, U2.7
RING_EN: U1.R13, U2.1
SD_CS: J7.6, U1.R10
SPI_MISO: J7.4, U1.R8
SPI_MOSI: J7.3, U1.R3
SPI_SCK: J7.5, U1.R9
SW_OUT: D1.2, L1.1, U4.2

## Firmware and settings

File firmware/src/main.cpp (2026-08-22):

#include <Arduino.h>
#include <SPI.h>
#include <SD.h>
#include <esp_task_wdt.h>
#include <esp_ota_ops.h>
#include "phone_controller.h"
#include "web_manager.h"
#include "logger.h"
#include "stats.h"
#include "config.h"

// ============================================================================
// K6 GPO Exhibit — main application
//
// An ESP32 interface for an unmodified GPO 232/332 rotary telephone,
// designed for a K6 phone box exhibit.
//
// Features:
//   • Phone rings at random intervals; answering plays a history track
//   • Dialling a number plays a matching MP3 or "number not recognised"
//   • External control box: RING / CANCEL / RESET buttons
//   • All audio from SD card, played via I2S to MAX98357A DAC
//   • Optional A+B coin box (auto-detected daughter board on GPIO 36/39/35)
//   • Wi-Fi AP with web file manager and OTA firmware update
//
// Serial commands (115200 baud):
//   R   — trigger ring
//   H   — hang up / stop
//   C   — cancel ring
//   S   — print state
//   A   — toggle auto-ring on/off
//   V0-9 — set volume (0=min, 9=max)
//   B   — cycle coin box override (auto → off → on → auto)
//   T   — bring-up self-test checklist
//   K   — line-sense calibration wizard
//   E   — toggle rotary self-confirm (echo digits on lamp)
//   I   — toggle earpiece dial-pulse clicks
//   Q   — audio probe (1 kHz peak/RMS of digital feed)
// ============================================================================

PhoneController phone;
WebManager      web;
Logger          logger;
StatsTracker    stats;

// --- Safe mode (crash recovery) ---------------------------------------------
// RTC memory survives software resets but not power cycles.
RTC_DATA_ATTR static int  boot_crash_count = 0;
static bool safe_mode = false;
static const int  SAFE_MODE_THRESHOLD = 3;
static const unsigned long STABLE_BOOT_MS = 30000;  // 30s = considered stable

// --- Callbacks --------------------------------------------------------------

// Debug flag in audio_player.cpp: when true, the I2S hook logs call rate + peak.
extern volatile bool g_audio_hook_debug;

// Debug flag in phone_line.cpp: when true, logs raw line reading + dial edges.
extern volatile bool g_line_debug;

// Rotary self-confirm mode: when true, each decoded digit is echoed as lamp
// blinks so dialling can be verified on the bench with no laptop attached.
volatile bool g_dial_confirm = false;

// Non-blocking lamp echo for rotary self-confirm mode. Digits are queued and
// blinked out by serviceDialEcho() from the main loop so dialling and the state
// machine are never stalled (0 is shown as 10 blinks).
static uint8_t       s_echo_queue[16];
static uint8_t       s_echo_head = 0;
static uint8_t       s_echo_tail = 0;
static int           s_echo_blinks_left = 0;
static uint8_t       s_echo_phase = 0;   // 0 idle,1 pre-gap,2 on,3 off,4 done
static unsigned long s_echo_next  = 0;

static void queueDigitEcho(uint8_t digit) {
    uint8_t next = (uint8_t)((s_echo_tail + 1) % sizeof(s_echo_queue));
    if (next == s_echo_head) return;  // queue full: drop
    s_echo_queue[s_echo_tail] = (digit == 0) ? 10 : digit;
    s_echo_tail = next;
}

static void serviceDialEcho() {
    unsigned long now = millis();
    if (s_echo_phase == 0) {
        if (s_echo_head == s_echo_tail) return;  // nothing queued
        s_echo_blinks_left = s_echo_queue[s_echo_head];
        s_echo_head = (uint8_t)((s_echo_head + 1) % sizeof(s_echo_queue));
        s_echo_phase = 1;
        s_echo_next  = now + 250;  // short gap so separate digits are distinct
        return;
    }
    if (now < s_echo_next) return;
    switch (s_echo_phase) {
        case 1:  // pre-gap done -> lamp on
            digitalWrite(PIN_AUTO_LAMP, HIGH);
            s_echo_phase = 2;
            s_echo_next  = now + 150;
            break;
        case 2:  // on done -> lamp off, count the blink
            digitalWrite(PIN_AUTO_LAMP, LOW);
            s_echo_blinks_left--;
            s_echo_next  = now + 150;
            s_echo_phase = (s_echo_blinks_left > 0) ? 3 : 4;
            break;
        case 3:  // inter-blink gap done -> next blink on
            digitalWrite(PIN_AUTO_LAMP, HIGH);
            s_echo_phase = 2;
            s_echo_next  = now + 150;
            break;
        default: // digit finished -> restore resting state, go idle
            digitalWrite(PIN_AUTO_LAMP, phone.autoRingEnabled() ? HIGH : LOW);
            s_echo_phase = 0;
            break;
    }
}

static void onDigit(uint8_t digit) {
    Serial.printf("[app] digit: %d\n", digit);
    if (g_dial_confirm) queueDigitEcho(digit);
}

static void onNumber(const char* number) {
    Serial.printf("[app] number: %s\n", number);
    logger.callLog("DIAL number=%s", number);
}

static void onHook(HookState state) {
    Serial.printf("[app] hook: %s\n",
                  state == HookState::OFF_HOOK ? "OFF_HOOK" : "ON_HOOK");
}

static unsigned long dial_tone_start_ms_ = 0;

static void onState(PhoneState state) {
    switch (state) {
    case PhoneState::RINGING:
        logger.callLog("INCOMING ring_start");
        stats.recordIncomingRing();
        break;
    case PhoneState::PLAYING_HISTORY:
        logger.callLog("INCOMING answered");
        stats.recordIncomingAnswered();
        stats.recordPickup();
        stats.callStarted();
        break;
    case PhoneState::DIAL_TONE:
        stats.recordPickup();
        dial_tone_start_ms_ = millis();
        break;
    case PhoneState::DIALING: {
        // First digit arrived — record time since dial tone started.
        unsigned long dialToneMs = millis() - dial_tone_start_ms_;
        stats.recordFirstDigit(dialToneMs);
        break;
    }
    case PhoneState::RINGING_TONE:
    case PhoneState::PLAYING_NUMBER:
        if (state == PhoneState::PLAYING_NUMBER) {
            logger.callLog("OUTGOING connected number=%s", phone.dialledNumber());
            stats.recordOutgoingCall(phone.dialledNumber());
        }
        stats.recordCompletion();
        stats.callStarted();
        break;
    case PhoneState::PLAYING_NOT_REC:
        logger.callLog("OUTGOING not_recognised number=%s", phone.dialledNumber());
        stats.recordNotRecognised(phone.dialledNumber());
        stats.recordDiscovery(phone.dialledNumber());
        stats.recordCompletion();
        stats.callStarted();
        break;
    case PhoneState::AWAIT_COINS:
        stats.recordCompletion();
        break;
    case PhoneState::AWAIT_BTN_B:
        logger.callLog("OUTGOING not_recognised (coinbox) number=%s", phone.dialledNumber());
        stats.recordNotRecognised(phone.dialledNumber());
        stats.recordDiscovery(phone.dialledNumber());
        stats.recordCompletion();
        break;
    case PhoneState::IDLE:
        logger.callLog("IDLE");
        stats.callEnded();
        break;
    default:
        break;
    }
}

// --- Serial command handler -------------------------------------------------

// Read the remainder of a serial line after a command letter. Waits up to
// 10s for the first character, then reads until CR/LF (1s idle timeout).
static String readSerialLine() {
    String s;
    unsigned long start = millis();
    // Wait for the first character (feed the watchdog so an operator taking
    // their time — e.g. lifting the handset mid-calibration — can't trip it).
    while (!Serial.available() && millis() - start < 10000) {
        esp_task_wdt_reset();
        delay(1);
    }
    unsigned long t = millis();
    while (millis() - t < 1000) {
        esp_task_wdt_reset();
        if (Serial.available()) {
            char ch = Serial.read();
            if (ch == '\r' || ch == '\n') break;
            s += ch;
            t = millis();
        }
    }
    return s;
}

static void handleSerial() {
    if (!Serial.available()) return;

    char c = Serial.read();
    switch (toupper(c)) {
    case 'R':
        Serial.println("[cmd] ring");
        phone.ring();
        break;
    case 'H':
        Serial.println("[cmd] hang up");
        phone.hangUp();
        break;
    case 'C':
        Serial.println("[cmd] cancel");
        phone.cancelRing();
        break;
    case 'S':
        Serial.printf("[cmd] state=%s  hook=%s  line=%d  mode=%s  sd=%s  coinbox=%s(%s)\n",
                      phone.stateName(),
                      phone.line().hookState() == HookState::OFF_HOOK
                          ? "OFF_HOOK" : "ON_HOOK",
                      phone.line().lastRawReading(),
                      phone.autoRingEnabled() ? "AUTO" : "MANUAL",
                      phone.player().sdReady() ? "OK" : "FAIL",
                      phone.coinBox().isInstalled() ? "ACTIVE" : "OFF",
                      phone.coinBox().overrideMode() == 1 ? "forced-on" :
                      phone.coinBox().overrideMode() == 0 ? "forced-off" : "auto");
        break;
    case 'A':
        phone.setAutoRing(!phone.autoRingEnabled());
        Serial.printf("[cmd] auto-ring %s\n",
                      phone.autoRingEnabled() ? "ON" : "OFF");
        break;
    case 'V': {
        // Read the next character as volume digit 0-9.
        unsigned long t = millis();
        while (!Serial.available() && millis() - t < 500) {}
        if (Serial.available()) {
            int v = Serial.read() - '0';
            if (v >= 0 && v <= 9) {
                uint8_t vol = map(v, 0, 9, 0, 21);
                phone.player().setVolume(vol);
                Serial.printf("[cmd] volume → %d/21\n", vol);
            }
        }
        break;
    }
    case 'B': {
        int cur = phone.coinBox().overrideMode();
        int next = (cur == -1) ? 0 : (cur == 0) ? 1 : -1;
        phone.coinBox().setOverride(next);
        break;
    }
    case 'L': {
        // Get/set master line level (0-100). "L" prints, "L 15" sets.
        String arg = readSerialLine();
        arg.trim();
        if (arg.length()) {
            int v = arg.toInt();
            if (v < 0) v = 0;
            if (v > 100) v = 100;
            phone.player().setLineLevel((uint8_t)v);
        }
        Serial.printf("[cmd] line level = %d%%\n", phone.player().lineLevel());
        break;
    }
    case 'D': {
        g_audio_hook_debug = !g_audio_hook_debug;
        Serial.printf("[cmd] I2S hook debug %s\n", g_audio_hook_debug ? "ON" : "OFF");
        break;
    }
    case 'N': {
        g_line_debug = !g_line_debug;
        Serial.printf("[cmd] line/dial debug %s\n", g_line_debug ? "ON" : "OFF");
        break;
    }
    case 'T': {
        // Bring-up self-test checklist.
        Serial.println(web.selfTest());
        break;
    }
    case 'Q': {
        // Audio probe: play 1 kHz and report peak/RMS of the digital feed.
        Serial.println(web.audioProbe());
        break;
    }
    case 'E': {
        g_dial_confirm = !g_dial_confirm;
        Serial.printf("[cmd] dial echo %s\n", g_dial_confirm ? "ON" : "OFF");
        break;
    }
    case 'I': {
        // Toggle the earpiece dial-pulse clicks.
        phone.setDialTicks(!phone.dialTicks());
        web.persistSettings();
        Serial.printf("[cmd] dial ticks %s\n", phone.dialTicks() ? "ON" : "OFF");
        break;
    }
    case 'K': {
        // Line-sense calibration wizard.
        Serial.println("[cal] Ensure handset is ON-HOOK, then press Enter...");
        readSerialLine();
        int on = phone.line().readAveraged(128);
        Serial.printf("[cal] on-hook raw=%d\n", on);
        Serial.println("[cal] LIFT the handset (OFF-HOOK), then press Enter...");
        readSerialLine();
        int off = phone.line().readAveraged(128);
        Serial.printf("[cal] off-hook raw=%d\n", off);
        if (phone.line().applyCalibration(on, off)) {
            web.persistSettings();
            Serial.printf("[cal] thresholds set: on>=%d  off<%d  (saved)\n",
                          phone.line().thresholdOn(), phone.line().thresholdOff());
        } else {
            Serial.println("[cal] FAILED: on/off levels too close. Check wiring, retry.");
        }
        break;
    }
    case 'F': {
        // Tone/EQ preset test. "F 0".."F 3". Set BEFORE starting playback.
        String arg = readSerialLine();
        arg.trim();
        int preset = arg.length() ? arg.toInt() : 0;
        switch (preset) {
        case 0: phone.player().setEq(0, 0, 0);      break;  // flat
        case 1: phone.player().setEq(-20, 0, 0);    break;  // gentle low cut
        case 2: phone.player().setEq(-40, 0, -12);  break;  // telephone band
        case 3: phone.player().setEq(-40, -6, -40); break;  // narrow mid only
        default: Serial.println("[cmd] F 0=flat 1=lowcut 2=telephone 3=narrow"); break;
        }
        break;
    }
    case 'W': {
        // Wi-Fi report, and "W <1-13>" to move the hotspot to a channel.
        String arg = readSerialLine();
        arg.trim();
        if (arg.length()) {
            int ch = arg.toInt();
            if (web.setApChannel((uint8_t)ch)) {
                Serial.printf("[cmd] AP channel -> %d, restarting to apply\n", ch);
                delay(200);
                ESP.restart();
            } else {
                Serial.println("[cmd] usage: W          report");
                Serial.println("[cmd]        W <1-13>  set hotspot channel (restarts)");
            }
        } else {
            Serial.println(web.wifiReport());
        }
        break;
    }
    case 'G': {
        Serial.printf("[cmd] request trace %s\n", web.toggleWebTrace() ? "ON" : "OFF");
        break;
    }
    case 'Z': {
        web.resetTimingStats();
        Serial.println("[cmd] timing counters cleared");
        break;
    }
    case 'P': {
        // Play a file directly, regardless of hook state. Reads the rest of
        // the line as the path, e.g.  "P /history/test.wav".
        String path = readSerialLine();
        path.trim();
        if (!path.length()) {
            Serial.println("[cmd] usage: P <path>   e.g. P /history/test.wav");
        } else if (!phone.player().sdReady()) {
            Serial.println("[cmd] error: SD not available");
        } else {
            bool ok = phone.player().playFile(path.c_str(), false);
            Serial.printf("[cmd] %s %s\n", ok ? "playing" : "error playing", path.c_str());
        }
        break;
    }
    default:
        break;
    }
}

// --- Arduino entry points ---------------------------------------------------

void setup() {
    Serial.begin(115200);
    delay(500);

    // Start boot indication immediately — fast lamp flash.
    pinMode(PIN_AUTO_LAMP, OUTPUT);
    digitalWrite(PIN_AUTO_LAMP, HIGH);

    Serial.println();
    Serial.println("========================================");
    Serial.println("  K6 GPO Exhibit — ESP32 Phone Interface");
    Serial.println("  GPO 232 / 332 Rotary Telephone");
    Serial.println("========================================");
    Serial.println();

    // Safe mode: if the device has crashed SAFE_MODE_THRESHOLD times in a
    // row without running for STABLE_BOOT_MS, skip phone init and only
    // start Wi-Fi + web so the user can re-flash via OTA.
    boot_crash_count++;
    if (boot_crash_count >= SAFE_MODE_THRESHOLD) {
        safe_mode = true;
        Serial.println("*** SAFE MODE — phone logic disabled, web only ***");
        Serial.println("*** Upload new firmware via http://192.168.4.1/ ***");

        // Attempt automatic rollback to previous firmware if available.
        const esp_partition_t* prev = esp_ota_get_last_invalid_partition();
        if (prev) {
            Serial.printf("[app] rolling back to previous firmware on %s\n", prev->label);
            esp_ota_set_boot_partition(prev);
            delay(500);
            ESP.restart();
        }

        // Still need SD for the web file manager.
        SPI.begin();
        SD.begin(PIN_SD_CS);
        logger.begin();
        logger.systemLog("SAFE MODE entered after %d crashes (no rollback available)", boot_crash_count);
        stats.begin();
        web.begin(logger, stats, phone);
        return;
    }

    // Blink lamp during init (100ms on/off = fast flash).
    digitalWrite(PIN_AUTO_LAMP, LOW);
    delay(100);
    digitalWrite(PIN_AUTO_LAMP, HIGH);

    phone.onDigit(onDigit);
    phone.onNumber(onNumber);
    phone.onHook(onHook);
    phone.onState(onState);
    phone.begin();
    logger.begin();
    stats.begin();

    Serial.println("[app] commands: R=ring  H=hangup  C=cancel  S=status  A=auto-ring  V0-9=vol  P <path>=play file");
    Serial.println("[app] diagnostics: T=self-test  K=calibrate line  E=dial echo  I=dial ticks  Q=audio probe  N=line debug");
    Serial.println("[app] network: W=wi-fi report+channel survey  W <1-13>=set channel  G=trace requests  Z=clear timers");
    Serial.printf("[app] mode: %s (lamp %s)\n",
                  phone.autoRingEnabled() ? "AUTO" : "MANUAL",
                  phone.autoRingEnabled() ? "ON" : "OFF");
    if (phone.coinBox().isInstalled()) {
        Serial.println("[app] A+B coin box detected — coin logic active");
    }

    web.begin(logger, stats, phone);
    logger.systemLog("SD=%s coinbox=%s mode=%s",
                    phone.player().sdReady() ? "OK" : "FAIL",
                    phone.coinBox().isInstalled() ? "INSTALLED" : "NONE",
                    phone.autoRingEnabled() ? "AUTO" : "MANUAL");
    if (!phone.player().sdReady()) {
        stats.recordError(StatsTracker::ErrorType::SD_FAILURE, "SD card not available at boot");
    }

    // Mark current firmware as valid (A/B rollback support).
    esp_ota_mark_app_valid_cancel_rollback();
    Serial.println("[app] firmware marked valid");

    // Capture the on-hook line-sense level at boot and persist it (tagged with
    // the boot number) so line-level drift is visible across power cycles.
    int boot_line = phone.line().readAveraged(64);
    stats.recordBootLine(logger.bootNumber(), boot_line);
    logger.systemLog("LINE boot-level raw=%d cal=%s on>=%d off<%d",
                     boot_line, phone.line().calibrated() ? "yes" : "no",
                     phone.line().thresholdOn(), phone.line().thresholdOff());

    // Boot complete — single bell strike and steady lamp.
    phone.bell().strike(150);
    digitalWrite(PIN_AUTO_LAMP, phone.autoRingEnabled() ? HIGH : LOW);
    Serial.println("[app] boot complete — ready");

    // Hardware watchdog: reboot if loop() stops for 15 seconds.
    esp_task_wdt_init(15, true);
    esp_task_wdt_add(NULL);
}

// Periodic heartbeat: a liveness line in the system log with uptime and heap
// so an unattended exhibit's health can be reviewed after the fact.
static const unsigned long HEARTBEAT_INTERVAL_MS = 3600000;  // hourly
static unsigned long s_last_heartbeat_ms = 0;
static uint32_t      s_min_heap = 0xFFFFFFFF;

static void serviceHeartbeat() {
    uint32_t heap = ESP.getFreeHeap();
    if (heap < s_min_heap) s_min_heap = heap;

    if (millis() - s_last_heartbeat_ms < HEARTBEAT_INTERVAL_MS) return;
    s_last_heartbeat_ms = millis();
    logger.systemLog("HEARTBEAT uptime=%lus heap=%u min_heap=%u sd=%s state=%s",
                     millis() / 1000, heap, s_min_heap,
                     phone.player().sdReady() ? "ok" : "FAIL",
                     phone.stateName());
}

void loop() {
    esp_task_wdt_reset();

    // Once we've been running for STABLE_BOOT_MS, clear the crash counter.
    if (boot_crash_count > 0 && millis() > STABLE_BOOT_MS) {
        boot_crash_count = 0;
    }

    if (!safe_mode) {
        phone.update();
        bool sd_was_ok = phone.player().sdReady();
        // checkSdCard() auto-remounts a lost card and rebuilds the audio path,
        // so a wedged SD/audio subsystem self-heals without a power cycle.
        phone.player().checkSdCard();
        bool sd_now_ok = phone.player().sdReady();
        if (sd_was_ok && !sd_now_ok) {
            stats.recordError(StatsTracker::ErrorType::SD_FAILURE, "SD card lost during operation");
            logger.systemLog("ERROR: SD card lost — attempting auto-recovery");
        } else if (!sd_was_ok && sd_now_ok) {
            logger.systemLog("RECOVERED: SD card remounted, audio path reinitialised");
        }
    }
    stats.update();
    web.update();
    serviceDialEcho();
    serviceHeartbeat();
    handleSerial();
}

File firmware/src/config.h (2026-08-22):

#pragma once

// ============================================================================
// K6 GPO Exhibit — ESP32 Interface for GPO 232/332 Telephones
// Pin assignments and system configuration
// ============================================================================

// --- Phone line interface ---------------------------------------------------
constexpr int PIN_LINE_SENSE   = 34;  // ADC1_CH6, input-only GPIO

// --- Bell / ring generator --------------------------------------------------
constexpr int PIN_RING_EN      = 4;   // H-bridge enable (active-high)
constexpr int PIN_RING_A       = 16;  // H-bridge input A
constexpr int PIN_RING_B       = 17;  // H-bridge input B

// --- I2S audio output (to MAX98357A DAC → coupling transformer → phone) -----
constexpr int PIN_I2S_BCLK     = 26;
constexpr int PIN_I2S_LRCLK    = 25;
constexpr int PIN_I2S_DOUT     = 22;

// --- SD card (SPI) ----------------------------------------------------------
constexpr int PIN_SD_CS        = 5;
// MOSI=23, MISO=19, SCK=18 (default VSPI)

// --- External control panel buttons (active-low with internal pull-up) ------
constexpr int PIN_BTN_RING     = 32;  // trigger incoming ring
constexpr int PIN_BTN_CANCEL   = 33;  // cancel ring / stop playback
constexpr int PIN_BTN_RESET    = 27;  // system reset
constexpr int PIN_BTN_MODE     = 14;  // toggle auto/manual ring mode

// --- A+B Coin Box (optional daughter board) ----------------------------------
// These input-only GPIOs are active-low via optocoupler.  GPIO 36/39/35
// have NO internal pull-up — external 10 kΩ pull-up resistors (R4/R5/R6)
// on the carrier board hold them HIGH when no daughter board is connected.
// Without these pull-ups the pins float and false detection occurs.
constexpr int PIN_COIN_SENSE   = 36;  // coin weight switch (coins inserted)
constexpr int PIN_COIN_BTN_A   = 39;  // Button A (collect coins, connect call)
constexpr int PIN_COIN_BTN_B   = 35;  // Button B (refund coins)

// --- Auto-mode indicator lamp ------------------------------------------------
constexpr int PIN_AUTO_LAMP    = 13;  // drives 3-6V panel lamp (active-high)

// --- Status LED -------------------------------------------------------------
constexpr int PIN_STATUS_LED   = 2;   // on-board LED on most dev-kits

// --- Wi-Fi access point ------------------------------------------------------
constexpr const char* WIFI_AP_SSID = "K6-Exhibit";
constexpr const char* WIFI_AP_PASS = "phonebox";    // min 8 chars for WPA2

// --- Firmware version --------------------------------------------------------
#define FIRMWARE_VERSION "1.5.0"

// --- Timing constants -------------------------------------------------------

// Hook detection
constexpr unsigned long HOOK_DEBOUNCE_MS      = 80;
constexpr int           LINE_THRESHOLD_ON     = 800;   // ADC value: phone off-hook
constexpr int           LINE_THRESHOLD_OFF    = 300;   // ADC value: phone on-hook

// Rotary dial pulse decoding
constexpr unsigned long PULSE_MIN_BREAK_MS    = 8;
constexpr unsigned long PULSE_MAX_BREAK_MS    = 120;
constexpr unsigned long INTER_DIGIT_TIMEOUT_MS = 300;

// UK ring cadence: 400 ms ON, 200 ms OFF, 400 ms ON, 2000 ms OFF (3 s cycle)
constexpr unsigned long RING_ON_1_MS          = 400;
constexpr unsigned long RING_OFF_1_MS         = 200;
constexpr unsigned long RING_ON_2_MS          = 400;
constexpr unsigned long RING_OFF_2_MS         = 2000;
constexpr int           RING_FREQ_HZ          = 25;

// The 48 V bell drive couples onto the line and pins the hook sense high while
// striking; the rectified charge also lingers briefly after the bell stops.
// Only trust the hook state this far into a silent cadence gap, so a false
// "answer" can't be triggered by coupling. Set larger than the short 200 ms
// gap so only the long 2000 ms gap qualifies (line fully settled by then).
constexpr unsigned long RING_ANSWER_GUARD_MS  = 350;

// Random auto-ring interval (ms).  The phone will ring automatically at a
// random interval between these two bounds.
constexpr unsigned long AUTO_RING_MIN_MS      = 300000;   // 5 minutes
constexpr unsigned long AUTO_RING_MAX_MS      = 1800000;  // 30 minutes

// Dialling
constexpr int           MAX_DIALLED_DIGITS    = 11;
constexpr unsigned long NUMBER_COMPLETE_MS    = 3000;     // gap after last digit
constexpr unsigned long DIAL_TONE_TIMEOUT_MS  = 15000;    // idle off-hook timeout

// Button debounce
constexpr unsigned long BTN_DEBOUNCE_MS       = 50;

// A+B coin box
constexpr unsigned long COIN_DEBOUNCE_MS      = 100;   // debounce for coin/button inputs
constexpr unsigned long COIN_DETECT_BOOT_MS   = 2000;  // time at boot to detect daughter board
constexpr unsigned long COIN_BTN_A_TIMEOUT_MS = 30000; // max wait for Button A after answer
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

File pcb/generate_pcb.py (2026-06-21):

#!/usr/bin/env python3
"""Generate KiCad 6 PCB file for K6 GPO Exhibit carrier board (Rev 2).

Uses the pcbnew Python API to create a valid PCB with proper footprints.
Board: 100mm x 100mm, 2-layer
ESP32 DevKit V1 (30-pin, 2x15) with USB facing bottom edge.

Run with: /usr/bin/python3 generate_pcb.py
(Must use system Python for pcbnew module access)

Layout (top to bottom):
  Zone A (y 0-15mm):  Power — barrel jacks + LM2596 module
  Zone B (y 15-55mm): ESP32 centre, peripherals on left/right sides
  Zone D (y 55-70mm): Protection diodes
  Zone E (y 70-100mm): Connectors — terminal, buttons, lamp, daughter board, pull-ups
"""

import pcbnew
import os

def mm(val):
    return int(val * 1e6)

BOARD_W = 100.0
BOARD_H = 100.0
OX = 100.0  # Board origin X in KiCad coords
OY = 50.0   # Board origin Y in KiCad coords

FP_LIB = "/usr/share/kicad/footprints/"


def load_fp(lib_name, fp_name):
    lib_path = os.path.join(FP_LIB, lib_name + ".pretty")
    fp = pcbnew.FootprintLoad(lib_path, fp_name)
    if fp is None:
        raise RuntimeError(f"Could not load {lib_name}:{fp_name}")
    return fp


def place(board, lib_name, fp_name, ref, value, x_mm, y_mm, angle_deg=0):
    fp = load_fp(lib_name, fp_name)
    fp.SetReference(ref)
    fp.SetValue(value)
    fp.SetPosition(pcbnew.wxPointMM(x_mm, y_mm))
    if angle_deg != 0:
        fp.SetOrientationDegrees(angle_deg)
    board.Add(fp)
    return fp


def text(board, txt, x, y, layer, sz=1.0, thk=0.15):
    t = pcbnew.PCB_TEXT(board)
    t.SetText(txt)
    t.SetPosition(pcbnew.wxPointMM(x, y))
    t.SetLayer(layer)
    t.SetTextSize(pcbnew.wxSizeMM(sz, sz))
    t.SetTextThickness(mm(thk))
    board.Add(t)


def line(board, x1, y1, x2, y2, layer, w=0.15):
    seg = pcbnew.PCB_SHAPE(board)
    seg.SetShape(pcbnew.SHAPE_T_SEGMENT)
    seg.SetStart(pcbnew.wxPointMM(x1, y1))
    seg.SetEnd(pcbnew.wxPointMM(x2, y2))
    seg.SetLayer(layer)
    seg.SetWidth(mm(w))
    board.Add(seg)


def main():
    board = pcbnew.BOARD()
    board.SetCopperLayerCount(2)

    # ── Board outline ──
    cx = [(OX, OY), (OX+BOARD_W, OY), (OX+BOARD_W, OY+BOARD_H), (OX, OY+BOARD_H)]
    for i in range(4):
        x1, y1 = cx[i]; x2, y2 = cx[(i+1)%4]
        line(board, x1, y1, x2, y2, pcbnew.Edge_Cuts, 0.1)

    # ── Nets ──
    net_names = ["", "GND", "+5V", "+3V3", "+12V", "+48V",
        "GPIO4", "GPIO16", "GPIO17", "GPIO26", "GPIO25", "GPIO22",
        "GPIO5", "GPIO23", "GPIO19", "GPIO18",
        "GPIO32", "GPIO33", "GPIO27", "GPIO14",
        "GPIO36", "GPIO39", "GPIO35", "GPIO13", "GPIO34", "GPIO2",
        "LINE_A", "LINE_B", "BELL", "OPTO_A", "DAC_LP", "DAC_LN",
        "GPIO12", "GPIO15", "GPIO21"]
    for i, n in enumerate(net_names):
        board.Add(pcbnew.NETINFO_ITEM(board, n, i))

    S = pcbnew.F_SilkS

    # ═══════════════════════════════════════════════════════════
    # Coordinate system: all relative to board top-left (OX, OY)
    # x grows right, y grows down
    # ═══════════════════════════════════════════════════════════

    # ── ZONE A: POWER (y = 0..15mm) ──

    # J1: 12V barrel jack — left side
    place(board, "Connector_BarrelJack", "BarrelJack_Horizontal",
          "J1", "12V_DC", OX+14, OY+10)
    text(board, "12V DC IN", OX+14, OY+3, S, 0.9, 0.12)

    # LM2596 buck module header (4-pin vertical: IN+ IN- OUT+ OUT-)
    place(board, "Connector_PinHeader_2.54mm", "PinHeader_1x04_P2.54mm_Vertical",
          "U_BUCK", "LM2596", OX+42, OY+8)
    text(board, "LM2596 Buck", OX+42, OY+3, S, 0.8, 0.12)

    # J2: 48V barrel jack — right side, rotated 180
    place(board, "Connector_BarrelJack", "BarrelJack_Horizontal",
          "J2", "48V_DC", OX+86, OY+10, 180)
    text(board, "48V DC IN", OX+86, OY+3, S, 0.9, 0.12)

    # ── ZONE B: ESP32 + PERIPHERALS (y = 17..55mm) ──
    # ESP32 centered horizontally, pin 1 (USB end) at bottom

    esp_cx = OX + 50                # ESP32 centre X
    esp_row = 22.86                 # row-to-row distance (0.9")
    esp_lx = esp_cx - esp_row/2     # left socket X = 138.57
    esp_rx = esp_cx + esp_row/2     # right socket X = 161.43
    dev_off = 5.08                  # dev hole offset from socket
    dev_lx = esp_lx - dev_off       # dev left X = 133.49
    dev_rx = esp_rx + dev_off       # dev right X = 166.51

    # ESP32 pin sockets centred at y = OY+36 (gives pin1 at y+53.8, pin15 at y+18.2)
    esp_cy = OY + 36
    pin1_y = esp_cy + 7*2.54        # bottom pin (USB end) = OY + 53.78
    pin15_y = esp_cy - 7*2.54       # top pin (antenna end) = OY + 18.22

    # Left and right ESP32 sockets
    place(board, "Connector_PinSocket_2.54mm", "PinSocket_1x15_P2.54mm_Vertical",
          "J_ESP_L", "ESP32_Left", esp_lx, esp_cy)
    place(board, "Connector_PinSocket_2.54mm", "PinSocket_1x15_P2.54mm_Vertical",
          "J_ESP_R", "ESP32_Right", esp_rx, esp_cy)

    # Dev access holes (pin headers parallel to ESP32 sockets)
    place(board, "Connector_PinHeader_2.54mm", "PinHeader_1x15_P2.54mm_Vertical",
          "J_DEV_L", "DEV_Left", dev_lx, esp_cy)
    place(board, "Connector_PinHeader_2.54mm", "PinHeader_1x15_P2.54mm_Vertical",
          "J_DEV_R", "DEV_Right", dev_rx, esp_cy)

    # C2: decoupling cap near ESP32 VIN (bottom left of ESP32)
    place(board, "Capacitor_THT", "C_Disc_D3.0mm_W1.6mm_P2.50mm",
          "C2", "100nF", esp_lx - 4, pin1_y)

    # USB direction label
    text(board, "USB -->", esp_cx, pin1_y + 3, S, 0.8, 0.12)

    # ESP32 left pin labels (bottom=pin1=VIN to top=pin15=EN)
    left_labels = ["VIN","GND","D13","D12","D14","D27","D26","D25",
                   "D33","D32","D35","D34","VN","VP","EN"]
    for i, lbl in enumerate(left_labels):
        text(board, lbl, dev_lx - 4, pin1_y - i*2.54, S, 0.55, 0.08)

    # ESP32 right pin labels
    right_labels = ["3V3","GND","D15","D2","D4","RX2","TX2","D5",
                    "D18","D19","D21","RX0","TX0","D22","D23"]
    for i, lbl in enumerate(right_labels):
        text(board, lbl, dev_rx + 4, pin1_y - i*2.54, S, 0.55, 0.08)

    # ── LEFT PERIPHERALS (x = 0..28mm) ──

    # PC817 optocoupler (DIP-4, 12.7 x 9mm)
    place(board, "Package_DIP", "DIP-4_W7.62mm",
          "U1", "PC817", OX+10, OY+22)
    text(board, "PC817", OX+10, OY+18, S, 0.7, 0.1)
    text(board, "pin1 dot", OX+5, OY+20, S, 0.5, 0.08)

    # R1: 470Ω 1W — same pad size as R2/R3 for consistency
    place(board, "Resistor_THT", "R_Axial_DIN0207_L6.3mm_D2.5mm_P7.62mm_Horizontal",
          "R1", "470R_1W", OX+8, OY+30)

    # R2: 220Ω — horizontal
    place(board, "Resistor_THT", "R_Axial_DIN0207_L6.3mm_D2.5mm_P7.62mm_Horizontal",
          "R2", "220R", OX+8, OY+34)

    # R3: 10kΩ — horizontal
    place(board, "Resistor_THT", "R_Axial_DIN0207_L6.3mm_D2.5mm_P7.62mm_Horizontal",
          "R3", "10K", OX+8, OY+38)
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

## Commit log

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2026-06-07 feat: exhibit mode — SD card MP3 playback, auto-ring, dial-a-number, control buttons
    Major feature additions for K6 phone box exhibit use:
    Audio system:
    - Replace built-in DAC with I2S output via MAX98357A DAC module
    - Add SD card MP3 playback (ESP32-audioI2S library)
    - All audio (tones, history, number tracks) loaded from SD card
    - Directory-based lookup: /history/ for random picks, /numbers/<digits>.mp3
    Exhibit features:
    - Random auto-ring timer (configurable 5-30 min interval)
    - Answering a ring plays a random history track from SD card
    - Dialling up to 11 digits matches against /numbers/ directory
    - Unmatched numbers play 'not recognised' announcement
    - File-based number mapping —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
    [audio_player.cpp, config.h, main.cpp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]
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2026-06-07 fix: Update KiCad PCB to version 8 format (fix layer name compatibility)
    KiCad 8 removed old layer aliases (ECO1.User, F.SilkS, F.CrtYd, etc.)
    from the fixed layer hash. Updated all layer definitions and references
    to use the KiCad 8 canonical names:
    F.SilkS -> F.Silkscreen
    F.CrtYd -> F.Courtyard
    F.Fab -> F.Fabrication
    ECO1.User -> User.Eco1
    etc.
    File format version bumped to 20240108 (KiCad 8).
    [k6_gpo_carrier.kicad_pcb, k6_gpo_carrier.kicad_sch]
2026-06-07 fix: KiCad 10 compatibility — use canonical short layer names and new ordinals
    KiCad 10 uses the short canonical names from LSET::Name() as the
    fixed layer hash keys (B.Adhes, F.SilkS, Eco1.User, F.CrtYd, etc.)
    and new interleaved layer ordinals (F.Cu=0, F.Mask=1, B.Cu=2, ...).
    Updated from KiCad 8 full-form names (B.Adhesive, F.Silkscreen, etc.)
    which are display names only, not valid for the parser's layer hash.
    File format version bumped to 20260329 (KiCad 10).
    [k6_gpo_carrier.kicad_pcb, k6_gpo_carrier.kicad_sch]
2026-06-07 fix: Use correct KiCad 10.0.x file format version (20260206)
    Version 20260329 is from the development branch (post-10.0 release).
    The 10.0 stable branch uses 20260206 as its latest format version.
    [k6_gpo_carrier.kicad_pcb, k6_gpo_carrier.kicad_sch]
2026-06-07 fix: Unique reference designators for mounting holes (MH1-MH4)
    FreeRouting/Specctra export requires unique reference designators.
    All four mounting holes now have MH1, MH2, MH3, MH4 instead of
    all sharing 'MH'.
    [k6_gpo_carrier.kicad_pcb, k6_gpo_carrier.kicad_sch]
2026-06-07 feat: Add detailed pin labels to silkscreen for all connectors
    Every connector now has per-pin silkscreen labels showing:
    - J3: 12V IN (+12V, GND)
    - J1: Buck converter (IN+/IN-/OUT+/OUT-)
    - J2: Boost converter (IN+/IN-/OUT+/OUT-)
    - U1: ESP32 DevKit (all 30 GPIO labels with function names)
    - J5: MAX98357A DAC (VIN, GND, SD, GAIN, DIN, BCLK, LRC)
    - J6: DAC output (SPK+, SPK-)
    - J4: Phone cord (LINE A Red, LINE B White, BELL Blue)
    - J7: SD Card (GND, VCC, MOSI, MISO, SCK, CS)
    - J8/J9/J10: Buttons (RING/CANCEL/RESET + GND)
    - U2: L293D (all 16 pins with net connections)
    - U3: PC817 (Anode, Cathode, Emitter, Collector)
    - T1: Audio transformer (P1/P2 speaker, S1/S2 line)
    - R1, R2, R3, C1: Values an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
    [k6_gpo_carrier.kicad_pcb, k6_gpo_carrier.kicad_sch]
2026-06-07 fix: Resolve label overlap — enlarge board to 100x100mm, shorten labels, add pinout reference
    - Board enlarged from 100x80mm to 100x100mm (still JLCPCB cheapest tier)
    - Components repositioned with more spacing between zones
    - Silkscreen labels shortened (e.g. GPIO34 SENSE → 34 SN)
    - Fixed L293D/PC817 label pitch (was 1.27mm, corrected to 2.54mm)
    - Added pcb/PINOUT.md with complete pinout tables for every connector
    - Updated README with new board dimensions and layout diagram
    [k6_gpo_carrier.kicad_pcb, k6_gpo_carrier.kicad_sch]
2026-06-08 fix: remove invalid justify=center for KiCad 10 compatibility
    KiCad 10 parser only accepts left/right/top/bottom/mirror in justify
    clauses. Center is the default when justify is omitted entirely.
    [k6_gpo_carrier.kicad_pcb, k6_gpo_carrier.kicad_sch]
2026-06-08 fix: LM2596 buck module updated to 5-pin header (IN+, IN-, OUT+, OUT-, ON/OFF)
    Also includes previous fix for KiCad 10 justify=center parse error.
    [k6_gpo_carrier.kicad_pcb, k6_gpo_carrier.kicad_sch]
2026-06-08 feat: Replace LM2596 module with TO-220-5 IC and full buck converter circuit
    - U4: LM2596-5.0 TO-220-5 IC (VIN, SW_OUT, GND, FB, ON/OFF)
    - C2: 680µF 25V input capacitor
    - L1: 33µH power inductor (SW_OUT → +5V)
    - D1: 1N5825 Schottky freewheeling diode
    - C3: 220µF 25V output capacitor
    - New SW_OUT net for switch node connections
    - Dashed silkscreen clearance outlines for:
    - XL6009 boost module (43×21mm)
    - MAX98357A DAC module (19×18mm)
    - Micro-SD card module (25×20mm)
    - J5/J6/T1/J4 moved down to avoid XL6009 module zone overlap
    - PINOUT.md updated with full LM2596 circuit documentation
    - Schematic netlist updated for new components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
    [k6_gpo_carrier.kicad_pcb, k6_gpo_carrier.kicad_sch]
2026-06-08 fix: Resolve component overlaps — move D1/C3 away from ESP32 area, separate DAC/XFMR/PHONE spacing
    - D1 moved left of ESP32 area (2.2mm clearance to nearest ESP32 pin)
    - C3 moved into top row next to L1 (no longer below ESP32)
    - J2 (XL6009) shifted right to accommodate C3 in top row
    - J6 (DAC out) moved down to y+48, separated from J5 (MAX98357A)
    - T1 (XFMR) moved to y+56, J4 (Phone) to y+66 — cascading separation
    - Added DAC OUT label for J6
    [k6_gpo_carrier.kicad_pcb, k6_gpo_carrier.kicad_sch]
2026-06-08 fix: Reduce U4 (LM2596) pad size to 1.3mm for 1.7mm pitch TO-220-5
    Default 1.7mm pads at 1.7mm pitch caused shorting between all adjacent
    pins. Reduced to 0.9mm drill / 1.3mm pad → 0.4mm gap between pads.
    Also added drill/pad_size parameters to pin_header_1xN for reuse.
    [k6_gpo_carrier.kicad_pcb, k6_gpo_carrier.kicad_sch]
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2026-06-12 fix: rework A+B coin box flow per user requirements
    - Incoming calls (ring → answer): NO A+B interaction, plays history directly
    - Outgoing calls with A+B:
    1. Lift handset → dial tone (no coin gate)
    2. Dial number
    3. Number recognised → prompt 'insert coins' (if not already in)
    → coins in → prompt 'press Button A' → A pressed → audio plays
    4. Number not recognised → play 'not recognised'
    → prompt 'press Button B' → B pressed → coins refunded, IDLE
    - Coins can be inserted before lifting handset (pre-loaded)
    - Button A must be pressed BEFORE audio plays (collects coins, connects)
    - Added /system/press_a.mp3 and /system/press_b.mp3 optional prompts
    - New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
    [config.h, phone_controller.cpp, phone_controller.h]
2026-06-14 feat: add 'replace handset' prompt at end of all playback flows
    After history track, number playback, or not-recognised playback finishes,
    plays /system/replace_handset.mp3 before transitioning to busy tone.
    Optional — if the file doesn't exist on SD card, goes straight to busy.
    Also added /system/press_b.mp3 prompt constant for AWAIT_BTN_B state.
    [config.h, phone_controller.cpp, phone_controller.h]
2026-06-14 feat: Wi-Fi AP file manager, OTA updates, system & call logging
    - ESP32 creates 'K6-Exhibit' Wi-Fi hotspot (password: phonebox)
    - Web UI at http://192.168.4.1/ for SD card file management
    - Browse/upload/delete files, create directories
    - OTA firmware update via .bin upload with progress bar
    - System log (/logs/system.log): boot, Wi-Fi, SD, mode, errors
    - Call log (/logs/calls.log): incoming/outgoing with timestamps
    - Log viewer in web UI with clear function
    - Logs auto-rotate at 64KB
    - Switched to huge_app partition table for headroom (37.7% flash)
    [config.h, main.cpp, web_manager.cpp]
2026-06-14 feat: safe mode fallback — auto-recovery after 3 consecutive crashes
    Uses RTC memory to count consecutive boot crashes. If the device
    crashes 3 times without running for 30s, it enters safe mode:
    phone logic disabled, Wi-Fi AP + web file manager + OTA only.
    This ensures firmware can always be re-flashed wirelessly even
    if a bad OTA update crashes the phone controller.
    [main.cpp]
2026-06-14 feat: web UI controls, visitor stats, MP3 validation, SD card info
    - Volume slider in web UI (real-time control via /api/volume)
    - Configurable auto-ring timing (min/max minutes via /api/autoring)
    - Ring Now button + Mode toggle from web UI
    - Visitor statistics dashboard: incoming/outgoing/answered counts,
    most-dialled numbers (top 5), total cumulative uptime
    - Stats persisted to /logs/stats.json, auto-save every 60s
    - MP3 file validation on upload: checks MPEG sync word or ID3 header,
    rejects non-MP3 files with error message
    - SD card space display (used/total MB) in system status
    - Last playing track shown in Controls section
    - Added ArduinoJson library for stats serialization
    - Config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
    [audio_player.cpp, main.cpp, phone_controller.cpp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]
2026-06-14 feat: number aliases via web UI, PWA support
    - Number alias manager: map dialled numbers to audio filenames
    (e.g. 999 → emergency plays /numbers/emergency.mp3)
    - Aliases stored in /system/aliases.json, editable via web UI
    - Aliases resolved at dial time in both direct play and coin box flows
    - Reload aliases instantly after web edit (no reboot needed)
    - PWA: manifest.json + service worker for Add to Home Screen
    - Caches main UI for offline-capable shell, API calls always go to network
    - Apple meta tags for iOS home screen support
    - Firmware version bumped to 1.2.0
    [audio_player.cpp, config.h, phone_controller.cpp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]
2026-06-14 feat: remote reboot button, live call timer in web UI
    - Restart Device button in System Status section (saves stats before reboot)
    - Call timer shows elapsed time (m:ss) in Controls section for active calls
    - Timer updates every 5s via status polling, shows — when idle
    [phone_controller.h, web_manager.cpp]
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2026-06-14 feat: call duration stats, watchdog, SD recovery, settings persistence, audio preview
    - Call duration tracking: avg/longest/total talk time in stats dashboard
    - Hardware watchdog (15s timeout): auto-reboot on hard crash/loop hang
    - SD card error recovery: periodic health check, auto-remount on failure
    - Settings persistence: volume, bell vol, auto-ring timing saved to
    /system/settings.json and restored on boot
    - Audio preview: play button on MP3 files in file manager streams to
    browser for previewing before uploading to exhibit
    - Bump firmware to v1.2.0
    [audio_player.cpp, main.cpp, stats.cpp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]
2026-06-14 feat: ringing tone, configurable ring count, daily log rotation
    - Outgoing calls play UK ringing tone (/system/ringing_tone.mp3) for 6s
    before connecting, simulating the called party answering
    - New RINGING_TONE state in phone controller state machine
    - Configurable ring count (0-60 cadences, 0=unlimited) via web UI slider
    and /api/ringcount endpoint. Saved to settings.json across reboots
    - Daily log rotation: logs archived to /logs/system_bN_dD.log when
    uptime crosses 24h boundaries. Boot counter tracked in boot_count.txt
    - Timestamp format improved: shows day count for multi-day uptimes
    - Ring count limit stops auto-ring after N cadences if unanswered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
    [config.h, phone_controller.cpp, phone_controller.h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]
2026-06-14 feat: ringing tone min/max, ring count, daily log rotation, boot counter
    - Ringing tone duration now a min/max range (2-15s) randomised per call
    via web UI. Simulates realistic variable answer times
    - Configurable ring count (0-60, 0=unlimited) limits auto-ring cadences
    - Daily log rotation: archives to /logs/system_bN_dD.log at 24h boundary
    - Boot counter persisted to /logs/boot_count.txt, shown in log headers
    - Fix unused variable warning in logger
    - All settings (ring tone range, ring count) persisted to settings.json
    [config.h, phone_controller.cpp, phone_controller.h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]
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2026-06-15 feat: boot indication + power-off protection
    Boot indication:
    - Lamp lights immediately on power-on (fast flash during init)
    - Single bell strike when boot completes and system is ready
    - Lamp settles to steady state reflecting auto/manual mode
    Power-off protection:
    - Settings and stats use write-to-temp-then-rename pattern.
    If power is cut mid-write, the temp file is incomplete but
    the original file is untouched. On next boot, if the main
    file is missing but temp exists, it recovers from temp.
    - Explicit f.flush() before f.close() on all SD writes (logs,
    stats, settings) to ensure data reaches the SD card.
    - Stats saved immediately on every call end (not just every 60s)
    so at mos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
    [bell_driver.cpp, main.cpp, stats.cpp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]
2026-06-15 feat(web): redesign UI for non-technical staff with light/dark mode
    - Replaced all hardcoded colors with CSS custom properties for theming
    - Added light/dark mode toggle with localStorage persistence
    - Renamed all controls for clarity (Auto-ring → Time Between Rings, etc.)
    - Added help text and plain-English explanations for every setting
    - Added section icons for visual scanning
    - Split Controls into Phone Status, Sound Settings, Automatic Ringing
    - Added colored mode badge (green=AUTOMATIC, amber=MANUAL)
    - Friendly state names (IDLE → Waiting for visitors)
    - Improved button labels (Flash Firmware → Install Update, etc.)
    - Better spacing, larger tap targets for mobile use
    - Stats disp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
    [web_manager.cpp]
2026-06-17 feat: hidden number discovery logging and Numbers Tried web UI
    - Log unrecognised dialled numbers to a persistent discovery list on SD card
    - New 'Numbers Tried' section in the web dashboard showing what visitors tried
    - Individual remove and clear all controls for managing the log
    - Persisted to /logs/discovery.json with crash-safe write pattern
    - Auto-refreshes every 30 seconds alongside other stats
    - Covers both standard and A+B coin box paths
    [main.cpp, stats.cpp, web_manager.cpp]
2026-06-20 docs: Rev 2 circuit redesign — dual PSU, pull-ups, 4 buttons, dev holes
    Hardware redesign to fix Rev 1 issues:
    - False A+B coin box detection: added external 10kΩ pull-ups (R4/R5/R6)
    on GPIO 36/39/35 (input-only, no internal pull-up)
    - Button non-detection: all 4 buttons documented (MODE was missing)
    - Polarity issues: clear IC orientation markers throughout
    - Power instability: separate 12V (logic) + 48V (bell) DC supplies,
    XL6009 boost converter removed entirely
    Updated schematic, BOM, and wiring guide for Rev 2.
    Updated firmware comments to document external pull-up requirement.
    [coin_box.cpp, config.h]
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2026-06-20 fix: correct transformer, DAC, and R1 footprints
    - Transformer T1: 2x2 pin header matching EI-14 audio transformer
    - DAC: added 2-pin screw terminal (J_SPK) for speaker output
    - R1: same pad size as R2/R3 for consistency (was using larger 1W footprint)
    [k6_carrier_rev2-B_Cu.gtl, k6_carrier_rev2-B_Mask.gts, k6_carrier_rev2-B_SilkS.gto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]
2026-06-20 feat: complete netlist assignments and ground plane connectivity
    - Assign correct nets to all 130 component pads (35 nets total)
    - GND pads on every component connect to B_Cu ground pour via
    thermal relief through plated through-holes
    - Add 21 ground stitching vias across all board zones
    - Add nets: OPTO_A, DAC_LP, DAC_LN, GPIO12, GPIO15, GPIO21
    - 18 pads intentionally unassigned (mounting holes, unused L293D
    channels, barrel jack switches, ESP32 EN/RX0/TX0, DAC SD/GAIN)
    - Ratsnest shows all remaining connections for manual routing
    - Regenerated Gerber and drill files
    [k6_carrier_rev2-B_Cu.gtl, k6_carrier_rev2-B_Mask.gts, k6_carrier_rev2-B_SilkS.gto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]
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2026-06-20 feat: add 5x 1N4007 protection diodes, increase board to 100x100mm
    - D1: anti-parallel across PC817 LED, clamps 48V reverse voltage to 0.7V
    - D2-D5: overvoltage clamps on transformer primary (DAC_LP/DAC_LN to +5V and GND)
    - Board increased from 100x80mm to 100x100mm for new Zone D (protection diodes)
    - Zone layout: A (power) / B (ESP32+peripherals) / D (protection) / E (connectors)
    - BOM and schematic updated with diode specs, interconnect table, and layout rules
    - 158 total pads, 140 assigned to nets, 18 intentionally unassigned
    [k6_carrier_rev2-B_Cu.gtl, k6_carrier_rev2-B_Mask.gts, k6_carrier_rev2-B_SilkS.gto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]
2026-06-20 fix: update SD card module pin order to 3V3 CS MOSI CLK MISO GND
    Matches the user's actual breakout board pin sequence (previously
    CS SCK MOSI MISO VCC GND). Silkscreen labels and net assignments
    updated accordingly.
    [k6_carrier_rev2-B_Cu.gtl, k6_carrier_rev2-B_Mask.gts, k6_carrier_rev2-B_SilkS.gto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]
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2026-06-22 feat: add engagement stats and tabbed web portal
    - Add session count (total pickups), time-to-first-digit, completion
    rate tracking to StatsTracker
    - Add error log ring buffer (bell faults, line anomalies, SD failures)
    - Hook new stats into phone state machine callbacks
    - Redesign web portal with tabbed navigation:
    Overview (status/controls), Stats, Diagnostics, Settings
    - Add mobile burger menu for responsive navigation
    - Add /api/diagnostics endpoint for error log
    - Update /api/stats to include new engagement metrics
    [main.cpp, stats.cpp, web_manager.cpp]
2026-06-22 refactor: move sound/ringing settings to Settings tab, add session summary + health to Overview
    - Overview tab now shows: Phone Status, Session Summary (pickups,
    completion rate, top number, uptime), Quick Health (SD, memory, errors)
    - Settings tab now contains: Sound Settings, Automatic Ringing,
    Audio Files, Record Audio, Firmware Update
    - Fix: nav-close button hidden on desktop by default
    [web_manager.cpp]
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2026-07-02 fix: coin box false detection + manual override
    - Change detection from single-sample to consecutive-sample (10 in a row)
    to filter GPIO 36/39 glitches from WiFi radio startup
    - Add serial command 'B' to cycle override (auto -> off -> on -> auto)
    - Add A+B Coin Box card to web Settings tab with dropdown
    - Persist coin_override in settings.json
    - Update status API with coin_override and coin_active fields
    [coin_box.cpp, main.cpp, web_manager.cpp]
2026-07-03 fix: SD card init — SPI reset + retry after boot glitches
    GPIO 5 (CS) is an ESP32 strapping pin that outputs PWM during boot,
    sending spurious chip-select pulses to the SD card. Fix by:
    - Explicitly calling SPI.begin() before SD.begin()
    - Deselecting card (CS HIGH) and sending 80 dummy clocks to flush
    any partial SPI command from boot
    - Retrying SD.begin() up to 3 times with delays between attempts
    [audio_player.cpp]
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2026-07-05 feat: compact mobile menu dropdown + web command terminal
    Mobile menu: replace the full-screen overlay with a compact dropdown
    anchored below the burger icon, dismissed by tapping outside.
    Terminal: add a Terminal tab with a text command interface for manual
    control and troubleshooting. Backend /api/terminal handler supports
    status, ring, hangup, cancel, mode, vol, bell, coin, play, stop, ls,
    cat, rm, sd, mem, uptime, wifi, reboot. Includes command history
    (up/down arrows) and quick-command buttons.
    [web_manager.cpp]
2026-07-05 feat: adjustable bell ring frequency (10-50 Hz)
    Ring frequency is now a runtime setting instead of the fixed 25 Hz
    compile-time constant. UK exchanges used ~17 Hz (16-2/3) through 25 Hz
    depending on era, and electromechanical bells often ring fuller at a
    lower frequency, so allow tuning by ear.
    - BellDriver::setRingFreq/ringFreq, clamped 10-50 Hz, default RING_FREQ_HZ
    - persisted in settings.json as bell_freq
    - web Settings: Bell Frequency field + Test Ring button
    - terminal: bellfreq [10-50] command
    - /api/bellfreq route + bell_freq in /api/status
    [bell_driver.cpp, web_manager.cpp]
2026-07-05 feat: fixed-duration test ring (~3s) for bell tuning
    Add PhoneController::testRing(seconds) that rings the bell for a fixed
    time regardless of the Maximum Ring Cycles setting, so frequency tuning
    is quick. The Settings 'Test Ring' button now rings for 3s; also a
    'testring [secs]' terminal command and /api/testring route.
    [phone_controller.cpp, phone_controller.h, web_manager.cpp]
2026-07-05 feat: steady sine test tone via terminal 'tone' command
    Add AudioPlayer::playTestTone(hz, secs): generates a short whole-cycle
    WAV sine at the requested frequency on the SD card, plays it looped, and
    auto-stops after the duration. Gives a stable AC signal across Line A/B
    that is easy to measure with a meter, unlike speech.
    Terminal: 'tone [hz] [secs]' (default 1000 Hz, 5s). Range 50-4000 Hz.
    [audio_player.cpp, web_manager.cpp]
2026-07-05 feat: master line-level trim to fix earpiece distortion
    The MAX98357A is a speaker amp; even the audio library's minimum volume
    step (vol 1 = 1/64 = -36dB) overdrives a telephone earpiece. Add a
    master attenuation applied per-sample via the library's audio_process_i2s
    hook, letting audio sit far below that floor without re-encoding files.
    - AudioPlayer::setLineLevel(0-100%) scales all samples pre-I2S
    - persisted in settings.json as line_level
    - web Settings: Line Level slider + Test Tone (5s) button
    - terminal: linelevel [0-100]
    - /api/linelevel + /api/tone routes; line_level in /api/status
    [audio_player.cpp, web_manager.cpp]
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2026-07-19 feat(firmware): earpiece click on each rotary dial pulse
    Reproduce the authentic ticks a GPO earpiece makes as the dial runs back.
    RotaryDecoder now flags each counted pulse (pulsed()); the controller plays
    a short generated click WAV (/system/_tick.wav, built once at begin) per
    pulse during DIAL_TONE/DIALING. Toggle via serial 'I' or web 'ticks'
    (default on), persisted to settings as dial_ticks.
    [audio_player.cpp, main.cpp, phone_controller.cpp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]
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2026-07-25 fix(firmware): reliable rotary pulse decode via higher break threshold
    Off-hook the loop sense rails near full-scale and each dial-pulse break
    decays slowly, only dipping below the low hook OFF threshold for the last
    ~20ms of a real ~66ms break. That made half the pulses fail the 20ms
    minimum-break filter (dialling 0 decoded as 4-5). Detect breaks against
    the higher ON threshold so each pulse registers for most of its duration,
    and relax PULSE_MIN_BREAK_MS to 8ms for margin.
    [config.h, phone_line.cpp]
2026-07-26 fix(firmware): ignore bell-coupled hook sense during ring; add audio normalize script
    Pressing Ring caused an immediate false 'answered' because the 48 V bell
    drive couples onto the phone line and pins the hook sense to off-hook while
    striking. Only trust the hook state during the silent gaps of the ring
    cadence (guarded by the hook debounce); a genuine handset lift is still
    caught within one cadence cycle (<3 s).
    Also add docs/audio-scripts/normalize_audio.sh to batch-level all SD-card
    tracks (mp3gain lossless or ffmpeg loudnorm) before copying.
    [bell_driver.cpp, phone_controller.cpp]
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2026-07-26 fix(firmware): only answer ring deep in the long silent gap
    The 80 ms guard was too short: rectified bell-coupling charge holds the
    hook sense high into the 200 ms gap, still self-answering. Only trust the
    hook state RING_ANSWER_GUARD_MS (350 ms) into a silent gap so only the long
    2 s gap qualifies, by which point the line has fully settled. Also suppress
    spurious hook-change log spam while the bell is striking, and log the raw
    reading when a ring is genuinely answered.
    [config.h, phone_controller.cpp]
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
